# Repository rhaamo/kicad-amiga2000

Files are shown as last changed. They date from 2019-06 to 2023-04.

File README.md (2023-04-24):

# Amiga 2000 KiCAD Schematics and PCB

# Revision

Current schematics are based on 6.0 plus known 6.2 fixes.

Deviations from the original 6.2:
- The snapped resistor net around the 68k have been removed from schematics.
- The two res net soldered to U603 and U604 have a dedicated footprint on PCB
- The bridge C1/R1 also has footprint, same for R2 from U800
- The PST reset have dedicated footprint, diode have been removed
- There is an aditionnal header, J3, with OVR and INT2 breakout for accelerator cards, easier than clipping on chips
- Jumpers should have a default working configuration labelled on the PCB plus various notes
- The keyboard connector footprint have been modified to handle either the original one, or a standard MIDI one
- The battery terminals are just a two pins header, just plug some wires and use any battery you want aside or glued or whatever

# TODO

- Check if there is no useless local labels that could have generated spurious nets connected in the PCB

# Notes

The capacitors on the left of the POWER Connector are somewhat troubling if you don't have a lot of experience.

So the five caps should be placed like this (IGNORE the + footprint on the PCB):

- C400, GND pin on left
- C406, GND pin on left
- C408, GND pin on right
- C410, GND pin on left
- C412, GND pin on right

If using an A500-Flash from Retro 7-bit, U540 and U203 can't be socketted or they will be too high.

# Building

The file `amiga2000.csv` contains a full Mouser BOM, around ~150€.

Memory and RTC chip should be got from eBay, same for the PST reset thingy (U1).

The ISA (8bit and 16bit connectors) fits perfectly a full-length connector got from like an old PC motherboard.

The the table at the bottom of this README for a list of DigiKey and Mouser P/N for ZORRO, CoPro, Video and ISA slots.

Other chips (paula, denise, CIA, etc.) are got from a donor motherboard.

If building it for real: first test the PCB for short between GND and the various power lines (+5V, -5V, +12V, +5V_USER, etc.), the zorro should have all.

Then solder all the electrolytics caps, connect power, re-test all the lines.

Solder everything else, don't populate ICs yet, re-power and re-test.

Then you can add ICs and run DiagROM and then enjoy.

DO NOT POPULATE: J1, J2, C902, C917, R901, FB904, FB906, RP904, RP906, RP905, C230, C240, they are unpopulated on factory 6.2 rev, so, let them as-is.

# Testing

My first prototype have been tested with DiagROM v1.1.

Working: mouse, zorro listing of detected cards, composite video out, video out, serial (out at least), one audio ch (the other one should work too), keyboard.
Booting a workbench from the accelerator CF sorta work until noise issue or something make any disk I/O hang and crash.

Left to test: floppy, parallel port, if the RTC works properly.

The DiagROM detects 1024kB of chipmem, the extended test goes all the way up to 1023kB and then throw an error, I'm not sure if it's a DiagROM issue or just expected.

# Libraries

Uses libraries from https://dev.sigpipe.me/dashieelectronics/kicad_libraries

# Various tools

## extract_labels.py
NOTE: Broken since format change with KiCAD 7.0

Use this script to quickly extract all Global Labels from wanted sheets.

```
./extract_labels.py agnus.kicad_sch amiga2000.kicad_sch chipram.kicad_sch coprocessor\ slot.kicad_sch denise.kicad_sch expansion\ logic.kicad_sch parallel.kicad_sch paula.kicad_sch pc\ slots.kicad_sch power.kicad_sch processor.kicad_sch serial.kicad_sch zorro.kicad_sch
```

# License

CC0

# Sources

My own dying 6.2 A2000 board.

This pre-6.2 schematics, best scan quality available...:
- http://amiga.serveftp.net/Schematics/A2000_schematics/A2000_rev6_schematics_scanned.pdf

A big thanks for Floppie209 for his 1:1 board replica:
- https://github.com/Floppie209/Amiga2000-remake/

Whithout Floppie work I wouldn't have had enough motivation to sacrifice a sorta working board for measurements.

Documented 6.2 fixes: https://wiki.sigpipe.me/amiga:a2000:rev6.2fixes

# Random parts numbers

| for | Digikey PN | Mouser PN | Manufacturer PN | EOL |
|-----|---|---|---|-----|
| Zorro (100pins) | A121376-ND | 571-5645235-3 | 5645235-3 | no |
| CoPro (86pins) | A144213-ND | 571-1-5530843-0 | 1-5530843-0 | no |
| Video Slots and ISA16bit (36p) | A31716-ND |  571-5530843-3 | 5530843-3 | no |
| ISA 8bit (62) | A121053-ND |  571-7-5530843-0  | 7-5530843-0 | no |
| Full lenght ISA slots | A101941-ND |  571-5176139-2  | 5176139-2 | no |
| Power connector, 14 pins | | 538-26-60-4140 | 26-60-4140 | no |

# Pictures

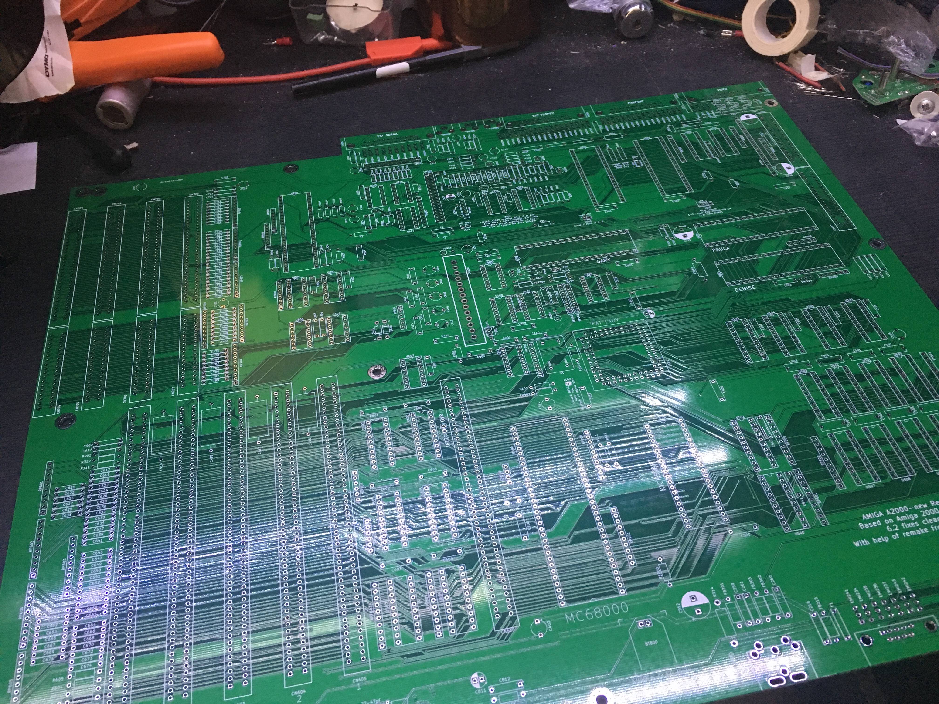
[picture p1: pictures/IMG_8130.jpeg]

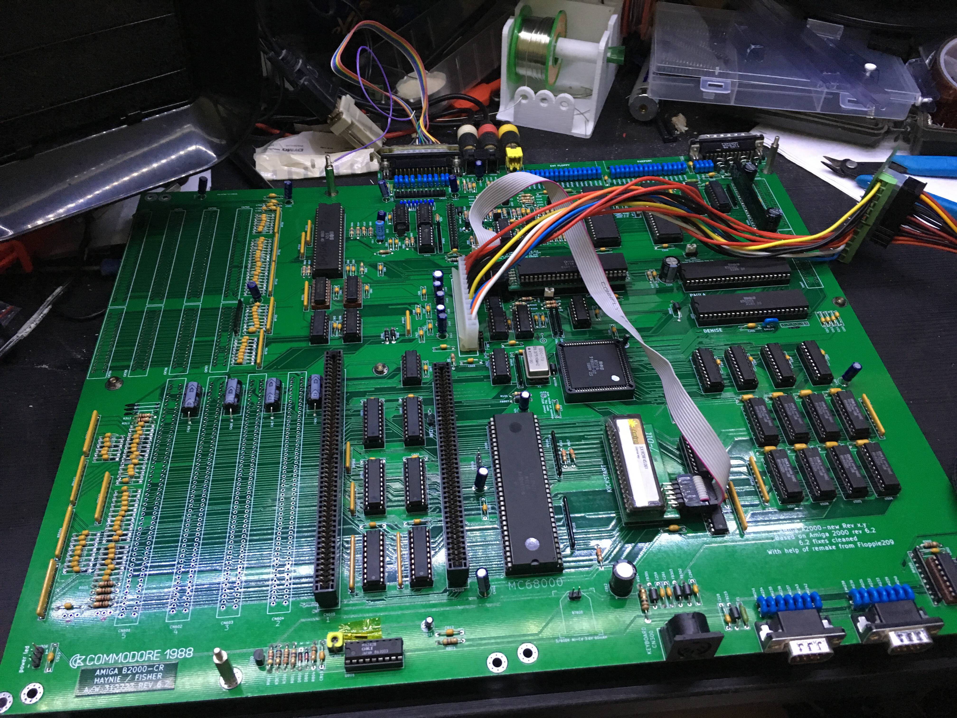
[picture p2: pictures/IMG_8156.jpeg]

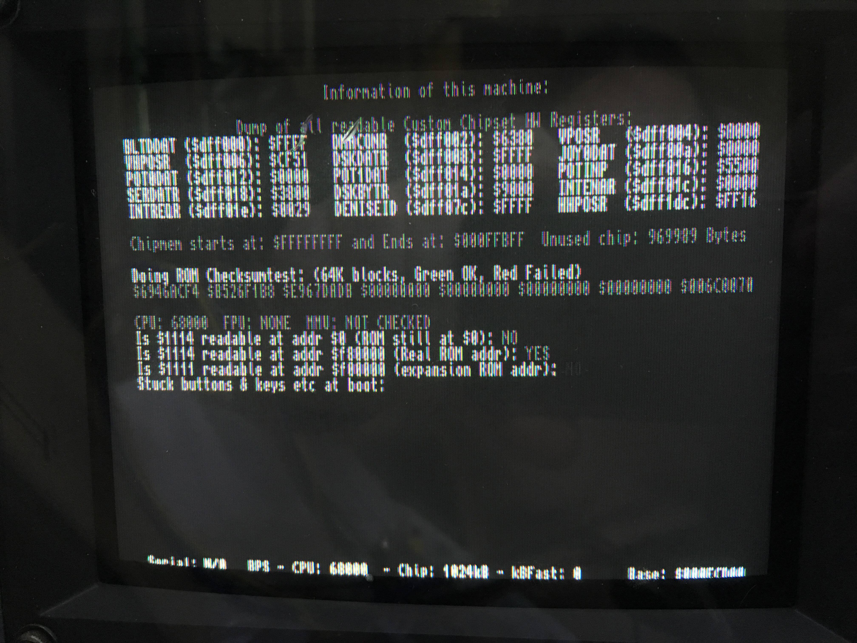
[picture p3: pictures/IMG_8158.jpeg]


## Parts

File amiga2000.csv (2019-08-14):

Ref | Qty | Value | Footprint | Datasheet | DoNotPopulate | Gender | MouserPN
BT800 | 1 | 3/60DK Ni-Cd 3.6V 60mAH | Connector_PinSocket_2.54mm:PinSocket_2x01_P2.54mm_Vertical | ~
C1 | 1 | 270pF | Capacitor_THT:C_Rect_L11.5mm_W2.6mm_P10.00mm_MKT | ~ |  |  | 581-SA101A271KAA
C100 C101 C102 C103 C104 C105 C106 C107 C108 C110 C200 C202 C203 C205 C206 C234 C244 C300 C301 C302 C303 C540 C541 C600 C601 C602 C603 C604 C605 C606 C607 C800 C802 C803 C804 C805 C812 C815 C900 C901 C903 C906 C909 C910 C915 C916 C918 C919 | 48 | 0.1uF | Capacitor_THT:C_Rect_L11.5mm_W2.6mm_P10.00mm_MKT | ~ |  |  | 581-SA105C104KARC
C201 C215 C216 C217 C219 C220 C221 C500 C700 C702 C703 C704 C705 | 13 | 0.22uF | Capacitor_THT:C_Rect_L11.5mm_W2.6mm_P10.00mm_MKT | ~ |  |  | 594-A224K20X7RF5TAA
C204 C305 C322 C323 C401 C407 C409 C411 C413 C414 | 10 | 0.01uF | Capacitor_THT:C_Rect_L11.5mm_W2.6mm_P10.00mm_MKT | ~ |  |  | 581-SA105C103K
C210 C211 C212 C213 C218 | 5 | 0.047uF | Capacitor_THT:C_Rect_L11.5mm_W2.6mm_P10.00mm_MKT | ~ |  |  | 581-SA105C473KARC
C214 C225 C226 C912 | 4 | 470uF 16/25v | Capacitor_THT:CP_Radial_D10.0mm_P5.00mm | ~ |  |  | 647-UVR1E471MPD
C222 C223 C402 C403 C404 C405 C406 C408 C410 C412 C420 C421 C422 | 13 | 47uF 16V | Capacitor_THT:CP_Radial_Tantal_D5.5mm_P5.00mm | ~ |  |  | 667-ECA-1CM470B
C224 C415 C811 | 3 | 4.7uF 16V | Capacitor_THT:CP_Radial_D5.0mm_P2.50mm | ~ |  |  | 647-UMA1C4R7MCD2TP
C230 C240 | 2 | 0.1uF | Capacitor_THT:C_Rect_L11.5mm_W2.6mm_P10.00mm_MKT | ~ | yes |  | 581-SA105C104KARC
C231 C241 | 2 | 6800pF | Capacitor_THT:C_Rect_L11.5mm_W2.6mm_P10.00mm_MKT | ~ |  |  | 581-SA101C682MAA
C232 C242 | 2 | 3900pF | Capacitor_THT:C_Rect_L11.5mm_W2.6mm_P10.00mm_MKT | ~ |  |  | 581-SA051C392KAA
C233 C243 C317 C318 C701 C813 C814 | 7 | 22uF 16V | Capacitor_THT:CP_Radial_Tantal_D5.0mm_P5.00mm | ~ |  |  | 667-ECA-1CM220B
C259 C260 C261 C304 C306 C904 C905 C907 C908 C914 C920 | 11 | 100pF | Capacitor_THT:C_Rect_L11.5mm_W2.6mm_P10.00mm_MKT | ~ |  |  | 80-C410C101K5G
C310 C311 C312 C313 C314 C315 C316 | 7 | 1000pF | Capacitor_THT:C_Rect_L7.0mm_W2.0mm_P5.00mm | ~ |  |  | 810-FG28C0G1H102JNT6
C320 C321 | 2 | 470pF | Capacitor_THT:C_Rect_L7.0mm_W2.0mm_P5.00mm | ~ |  |  | 810-FG28C0G1H471JNT0
C400 | 1 | 220uF 16V | Capacitor_THT:CP_Radial_Tantal_D6.0mm_P5.00mm | ~ |  |  | 667-ECA-1CM221B
C416 C417 C418 C419 | 4 | 220uF 16V | Capacitor_THT:C_Axial_L19.0mm_D8.0mm_P25.00mm_Horizontal | ~ |  |  | 75-516D227M025MM6AE3
C501 C502 C503 C504 C505 C506 C507 C508 | 8 | 0.33uF | Capacitor_THT:C_Rect_L11.5mm_W4.0mm_P10.00mm_MKT | ~ |  |  | 581-SA305C334KAA
C617 C619 C620 C621 C622 C623 C624 C625 C626 C627 C628 C629 C630 C631 C632 C633 C635 C637 C639 C641 C645 C647 C649 C650 C651 C652 C654 C655 C657 C658 C659 C660 C661 C662 C663 C664 C665 C666 C667 C668 C669 C670 C671 C672 C673 C674 C678 C711 C713 C714 C716 C717 C719 C720 C722 C726 C728 C730 C732 C734 C736 C738 C740 C742 C744 C746 C748 C750 C752 C754 C756 C758 C760 C762 C764 C766 C768 C770 C776 C778 C780 C782 C784 C786 C787 C789 C790 C791 C793 C794 C796 | 91 | 1000pF | Capacitor_THT:C_Rect_L11.5mm_W2.6mm_P10.00mm_MKT | ~ |  |  | 581-SA105C102KAR
C810 | 1 | 20pF | Capacitor_THT:C_Rect_L11.5mm_W2.6mm_P10.00mm_MKT | ~ |  |  | 581-SA102A200JAR
C902 C917 | 2 | empty | Capacitor_THT:C_Rect_L11.5mm_W2.0mm_P10.00mm_MKT | ~ | yes
C913 | 1 | 47pF | Capacitor_THT:C_Rect_L11.5mm_W2.6mm_P10.00mm_MKT | ~ |  |  | 80-C410C470K1G
CN200 | 1 | DB9P RIGHT(1) | Connector_Dsub:DSUB-9_Male_Horizontal_P2.77x2.84mm_EdgePinOffset7.70mm_Housed_MountingHolesOffset9.12mm | ~ |  | Male
CN201 | 1 | DB9P LEFT(0) | Connector_Dsub:DSUB-9_Male_Horizontal_P2.77x2.84mm_EdgePinOffset7.70mm_Housed_MountingHolesOffset9.12mm | ~ |  | Male
CN202 | 1 | DB23M | d_amiga:DSUB-23_Male_Horizontal_P2.77x2.84mm_EdgePinOffset7.70mm_Housed_MountingHolesOffset9.12mm | ~ |  | Male
CN203 | 1 | INTERNAL VIDEO SLOT TOP | d_amiga:VIDEOSLOT | ~
CN204 | 1 | RIGHT AUDIO | d_amiga:RCA | ~
CN205 | 1 | LEFT AUDIO | d_amiga:RCA | ~
CN206 | 1 | COMPOSITE | d_amiga:RCA | ~
CN207 | 1 | INTERNAL VIDEO SLOT BOT | d_amiga:VIDEOSLOT | ~
CN300 | 1 | KEYBOARD | d_amiga:DIN_5_KBD | http://www.mouser.com/ds/2/18/40_c091_abd_e-75918.pdf |  | Female
CN301 | 1 | DB25F | Connector_Dsub:DSUB-25_Female_Horizontal_P2.77x2.84mm_EdgePinOffset7.70mm_Housed_MountingHolesOffset9.12mm | ~ |  | Female
CN302 | 1 | DB23F | d_amiga:DSUB-23_Female_Horizontal_P2.77x2.84mm_EdgePinOffset7.70mm_Housed_MountingHolesOffset9.12mm | ~ |  | Female
CN303 | 1 | Conn_02x17_Odd_Even | Connector_PinHeader_2.54mm:PinHeader_2x17_P2.54mm_Vertical | ~ |  | Male
CN304 | 1 | Conn_02x13_Odd_Even | Connector_PinHeader_2.54mm:PinHeader_2x13_P2.54mm_Vertical | ~ |  | Male
CN305 | 1 | DB25M | Connector_Dsub:DSUB-25_Male_Horizontal_P2.77x2.84mm_EdgePinOffset7.70mm_Housed_MountingHolesOffset9.12mm | ~ |  | Male
CN400 | 1 | POWER_CONN | d_amiga:A2K_PWR | ~ |  | Male
CN600 | 1 | CO-PROCESSOR_SLOT | d_amiga:COPRO
CN601 CN602 CN603 CN604 CN605 | 5 | zorro_socket | d_amiga:Zorro
CN606 | 1 | Conn_01x04_Male | Connector_PinHeader_2.54mm:PinHeader_1x04_P2.54mm_Vertical | ~
CN700 CN701 CN702 CN703 | 4 | IBM_8_BIT_EXPANSION_BUS | ISA:ISA8
CN704 CN705 | 2 | IBM_16_BIT_EXTENDED_BUS | ISA:ISA16 |  | yes
CN706 CN707 | 2 | IBM_16_BIT_EXTENDED_BUS | ISA:ISA16
D300 D800 D801 | 3 | 1N4148 | Diode_THT:D_DO-35_SOD27_P7.62mm_Horizontal | https://assets.nexperia.com/documents/data-sheet/1N4148_1N4448.pdf |  |  | 78-1N4148
D400 D401 | 2 | 1N4001 | Diode_THT:D_DO-41_SOD81_P10.16mm_Horizontal | http://www.vishay.com/docs/88503/1n4001.pdf |  |  | 750-1N4001-G
EMI201 | 1 | Fitted with a double ferrite beads... | d_amiga:EMI_FILTER | ~ |  |  | 81-BL03RN2R1P1A
EMI206 EMI207 EMI210 EMI211 EMI229 EMI322 EMI323 EMI324 EMI339 EMI340 EMI341 | 11 | 100pF (Type C 101) | d_amiga:EMI_FILTER | ~ |  |  | Using Type F instead 81-DSS1NB32A101Q91A
EMI208 EMI311 EMI312 EMI313 EMI314 EMI315 EMI316 EMI317 EMI318 EMI319 EMI320 EMI321 | 12 | 100pF (Type F 101) | d_amiga:EMI_FILTER | ~ |  |  | 81-DSS1NB32A101Q91A
EMI209 | 1 | 3.8nF (Type F 382) | d_amiga:EMI_FILTER | ~ |  |  | 81-DSS1NB32A332Q91A
EMI230 EMI231 EMI232 EMI233 EMI234 EMI235 EMI236 EMI237 EMI238 EMI239 EMI240 EMI241 EMI242 EMI243 | 14 | 6.8nF (Type F 682) | d_amiga:EMI_FILTER | ~ |  |  | 81-DSS1NB32A682Q91A
EMI300 EMI301 EMI302 EMI303 EMI304 EMI305 EMI306 EMI307 EMI308 EMI309 EMI310 EMI325 EMI326 EMI327 EMI328 EMI329 EMI330 EMI331 EMI332 EMI333 EMI334 EMI335 EMI336 EMI337 EMI338 | 25 | 330pF (Type F 331) | d_amiga:EMI_FILTER | ~ |  |  | 81-DSS1NB32A331Q91A
F1 F2 F3 F4 F5 | 5 | 4A | Capacitor_THT:C_Rect_L11.5mm_W2.0mm_P10.00mm_MKT | ~ |  |  | 576-0251004.MRT1L
FB101 FB215 FB301 FB302 FB303 FB401 FB907 | 7 | Ferrite_Bead_Small | Inductor_THT:L_Axial_L7.0mm_D3.3mm_P10.16mm_Horizontal_Fastron_MICC | ~ |  |  | 875-28L0138-10R-10
FB102 | 1 | Ferrite_Bead_Small | Inductor_THT:L_Axial_L9.5mm_D4.0mm_P15.24mm_Horizontal_Fastron_SMCC | ~ |  |  | 875-28L0138-10R-10
FB216 FB217 FB218 FB219 FB220 FB221 FB900 FB901 FB902 FB903 | 10 | Ferrite_Bead_Small | d_amiga:FERRITE_BEADS_DOUBLE | ~ |  |  | 81-BL03RN2R1P1A
FB904 FB906 | 2 | Ferrite_Bead | Inductor_THT:L_Axial_L7.0mm_D3.3mm_P5.08mm_Vertical_Fastron_MICC | ~ | yes
H1 H2 H3 H4 H5 H6 H7 H8 H9 H10 H11 H12 H13 H14 | 14 | MountingHole_Pad | MountingHole:MountingHole_4mm_Pad_Via | ~ | yes
HY200 | 1 | HY200VIDIOT | Connector_PinSocket_2.54mm:PinSocket_1x22_P2.54mm_Vertical
J1 J2 | 2 | Conn_01x03_Male | Connector_PinHeader_2.54mm:PinHeader_1x03_P2.54mm_Vertical | ~ | yes
J3 | 1 | ACCEL | Connector_PinHeader_2.54mm:PinHeader_1x02_P2.54mm_Vertical | ~
J101 J200 J300 J306 | 4 | Conn_01x03_Male | Connector_PinHeader_2.54mm:PinHeader_1x03_P2.54mm_Vertical | ~
J102 | 1 | Jumper_2_Open | Jumper:SolderJumper-2_P1.3mm_Open_RoundedPad1.0x1.5mm | ~
J301 | 1 | DF1: | Connector_PinHeader_2.54mm:PinHeader_2x01_P2.54mm_Vertical | ~
J500 J900 | 2 | Jumper_2_Bridged | Connector_PinHeader_2.54mm:PinHeader_2x01_P2.54mm_Vertical | ~
Q200 Q201 | 2 | MPF102 | Package_TO_SOT_THT:TO-92_Inline | ~ |  |  | 610-2N3906 or 512-J113D74Z
Q202 Q302 | 2 | 2N3906 | Package_TO_SOT_THT:TO-92_Inline | https://www.fairchildsemi.com/datasheets/2N/2N3906.pdf |  |  | 833-2N3906-AP
Q300 | 1 | 2SC945 | Package_TO_SOT_THT:TO-92_Inline | ~
Q301 | 1 | 2N3904 | Package_TO_SOT_THT:TO-92_Inline | https://www.fairchildsemi.com/datasheets/2N/2N3904.pdf |  |  | 833-2N3904-AP
R1 R307 | 2 | 68 | Resistor_THT:R_Axial_DIN0207_L6.3mm_D2.5mm_P10.16mm_Horizontal | ~ |  |  | 603-CFR-25JT-52-68R
R2 R233 R243 R301 R302 R311 R312 R601 R602 R603 R604 R605 R800 R900 | 14 | 1k | Resistor_THT:R_Axial_DIN0207_L6.3mm_D2.5mm_P10.16mm_Horizontal | ~ |  |  | 603-CFR-25JR-521K
R101 R109 R201 R300 R309 R500 R806 R807 R902 R916 | 10 | 4.7k | Resistor_THT:R_Axial_DIN0207_L6.3mm_D2.5mm_P10.16mm_Horizontal | ~ |  |  | 603-CFR-25JT-52-4K7
R104 | 1 | 4.7K | Resistor_THT:R_Axial_DIN0207_L6.3mm_D2.5mm_P10.16mm_Horizontal | ~ |  |  | 603-CFR-25JR-524K7
R105 R106 R212 | 3 | 22 | Resistor_THT:R_Axial_DIN0207_L6.3mm_D2.5mm_P10.16mm_Horizontal | ~ |  |  | 603-CFR-25JR-52-22R
R110 R111 R114 R115 R917 R1000 | 6 | 330 | Resistor_THT:R_Axial_DIN0207_L6.3mm_D2.5mm_P10.16mm_Horizontal | ~ |  |  | 603-CFR-25JT-52-330R
R200 R215 | 2 | 1 | Resistor_THT:R_Axial_DIN0207_L6.3mm_D2.5mm_P10.16mm_Horizontal | ~ |  |  | 603-CFR-25JR-52-1R
R202 R203 R206 R211 R214 R216 R231 R232 R241 R242 R305 R306 R802 R804 | 14 | 10k | Resistor_THT:R_Axial_DIN0207_L6.3mm_D2.5mm_P10.16mm_Horizontal | ~ |  |  | 603-CFR-25JR-5210K
R204 R205 | 2 | 470k | Resistor_THT:R_Axial_DIN0207_L6.3mm_D2.5mm_P10.16mm_Horizontal | ~ |  |  | 603-CFR-25JR-52470K
R207 R208 | 2 | 10 | Resistor_THT:R_Axial_DIN0207_L6.3mm_D2.5mm_P10.16mm_Horizontal | ~ |  |  | 603-CFR-25JB-52-10R
R209 R210 | 2 | 1.2k | Resistor_THT:R_Axial_DIN0207_L6.3mm_D2.5mm_P10.16mm_Horizontal | ~ |  |  | 603-CFR-25JT-52-1K2
R213 | 1 | 2.7k | Resistor_THT:R_Axial_DIN0207_L6.3mm_D2.5mm_P10.16mm_Horizontal | ~ |  |  | 603-CFR-25JR-522K7
R230 R240 | 2 | 360 | Resistor_THT:R_Axial_DIN0207_L6.3mm_D2.5mm_P10.16mm_Horizontal | ~ |  |  | 603-CFR-25JB-52-360R
R234 R244 | 2 | 390 | Resistor_THT:R_Axial_DIN0207_L6.3mm_D2.5mm_P10.16mm_Horizontal | ~ |  |  | 603-CFR-25JR-52390R
R308 | 1 | 200 | Resistor_THT:R_Axial_DIN0207_L6.3mm_D2.5mm_P10.16mm_Horizontal | ~ |  |  | 603-CFR-25JR-52-200R
R310 | 1 | 47 0.5W | Resistor_THT:R_Axial_DIN0411_L9.9mm_D3.6mm_P15.24mm_Horizontal | ~ |  |  | 588-OL4705E-R52
R801 R803 | 2 | 470 | Resistor_THT:R_Axial_DIN0207_L6.3mm_D2.5mm_P10.16mm_Horizontal | ~ |  |  | 603-CFR-25JT-52-470R
R805 | 1 | 47k | Resistor_THT:R_Axial_DIN0207_L6.3mm_D2.5mm_P10.16mm_Horizontal | ~ |  |  | 603-CFR-25JR-5247K
R901 | 1 | empty | Resistor_THT:R_Axial_DIN0207_L6.3mm_D2.5mm_P10.16mm_Horizontal | ~ | yes
R904 R905 | 2 | 47 | Resistor_THT:R_Axial_DIN0207_L6.3mm_D2.5mm_P10.16mm_Horizontal | ~ |  |  | 603-CFR-25JT-52-47R
R914 | 1 | 1 0.5W | Resistor_THT:R_Axial_DIN0411_L9.9mm_D3.6mm_P15.24mm_Horizontal | ~ |  |  | 603-CFR-50JB-52-1R
RP100 RP101 RP200 RP705 | 4 | 4.7k | Resistor_THT:R_Array_SIP10 | http://www.vishay.com/docs/31509/csc.pdf |  |  | 858-L101S472LF
RP102 RP201 RP203 RP902 RP907 | 5 | 47 (isolated pack) | Resistor_THT:R_Array_SIP8 | http://www.vishay.com/docs/31509/csc.pdf |  |  | 858-L083S470LF
RP204 | 1 | 68 (isolated pack) | Resistor_THT:R_Array_SIP8 | http://www.vishay.com/docs/31509/csc.pdf |  |  | 858-L083S680LF
RP205 RP301 RP607 RP903 RP908 | 5 | 1k | Resistor_THT:R_Array_SIP6 | http://www.vishay.com/docs/31509/csc.pdf |  |  | 652-4606M-1LF-1K
RP300 | 1 | 10k | Resistor_THT:R_Array_SIP10 | http://www.vishay.com/docs/31509/csc.pdf |  |  | 652-4610X-1LF-10K
RP500 RP501 | 2 | 47 (isolated pack) | Resistor_THT:R_Array_SIP10 | http://www.vishay.com/docs/31509/csc.pdf |  |  | 652-4610X-2LF-47
RP502 | 1 | 22 (isolated pack) | Resistor_THT:R_Array_SIP10 | http://www.vishay.com/docs/31509/csc.pdf |  |  | 652-4610X-2LF-22
RP503 RP604 | 2 | 470 | Resistor_THT:R_Array_SIP10 | http://www.vishay.com/docs/31509/csc.pdf |  |  | 652-4610X-1LF-470
RP600 | 1 | 10k | Resistor_THT:R_Array_SIP8 | http://www.vishay.com/docs/31509/csc.pdf |  |  | 652-4608X-101-103FLF
RP601 RP602 RP603 RP605 RP700 RP701 RP702 RP703 RP704 | 9 | 1k | Resistor_THT:R_Array_SIP10 | http://www.vishay.com/docs/31509/csc.pdf |  |  | 652-4610X-1LF-1K
RP800 | 1 | 1k | Resistor_THT:R_Array_SIP8 | http://www.vishay.com/docs/31509/csc.pdf |  |  | 652-4608X-AP1-102LF
RP801 | 1 | 4.7k | Resistor_THT:R_Array_SIP8 | http://www.vishay.com/docs/31509/csc.pdf |  |  | 652-4608X-AP1-472LF
RP802 | 1 | 1k (isolated pack) | Resistor_THT:R_Array_SIP10 | http://www.vishay.com/docs/31509/csc.pdf |  |  | 269-1.0K-RC
RP904 RP905 RP906 | 3 | 4.7k | Resistor_THT:R_Array_SIP6 | http://www.vishay.com/docs/31509/csc.pdf | yes |  | 264-4.7K-RC
RPF603 RPF604 | 2 | 3.3k | Resistor_THT:R_Array_SIP10 | http://www.vishay.com/docs/31509/csc.pdf |  |  | 652-4610X-1LF-3.3K
U1 | 1 | PST518B | Package_TO_SOT_THT:TO-92L_Inline | http://www.amigawiki.org/lib/exe/fetch.php?media=de:service:upgrades:pst518b_mitsumi_datasheet.pdf
U100 | 1 | MC68000 | Package_DIP:DIP-64_W22.86mm_Socket | https://www.nxp.com/docs/en/reference-manual/MC68000UM.pdf
U101 | 1 | AGNUS8372 | Package_LCC:PLCC-84_THT-Socket
U102 | 1 | GARY5719 | Package_DIP:DIP-48_W15.24mm_Socket
U103 U105 | 2 | 74F245 | Package_DIP:DIP-20_W7.62mm_Socket | http://www.mouser.com/ds/2/308/fairchild%20semiconductor_74f245-1116738.pdf |  |  | 595-SN74F245N
U104 U106 | 2 | 74LS373 | Package_DIP:DIP-20_W7.62mm_Socket | http://www.ti.com/lit/gpn/sn74LS373 |  |  | 595-SN74LS373N
U107 | 1 | 74F04 | Package_DIP:DIP-14_W7.62mm_Socket | https://www.soemtron.org/downloads/disposals/74f04.pdf |  |  | 595-SN74F04N
U108 | 1 | 74LS74A | Package_DIP:DIP-14_W7.62mm_Socket | http://www.ti.com/lit/ds/symlink/sn74ls74a.pdf |  |  | 595-SN74LS74AN
U200 | 1 | PAULA | Package_DIP:DIP-48_W15.24mm_Socket | https://www.amigawiki.org/doku.php?id=de:parts:paula
U201 | 1 | DENISE8373 | Package_DIP:DIP-48_W15.24mm_Socket
U202 | 1 | 74LS157 | Package_DIP:DIP-16_W7.62mm_Socket | http://www.ti.com/lit/gpn/sn74LS157 |  |  | 595-SN74LS157N
U203 | 1 | 74LS38 | Package_DIP:DIP-14_W7.62mm_Socket | http://www.ti.com/lit/gpn/sn74LS38 |  |  | 595-SN74LS38N
U204 | 1 | LF347 | Package_DIP:DIP-14_W7.62mm_Socket | http://www.ti.com/lit/ds/symlink/lf347-n.pdf |  |  | 926-LF347N/NOPB
U205 U206 | 2 | 74LS244 | Package_DIP:DIP-20_W7.62mm_Socket | http://www.ti.com/lit/gpn/sn74LS244 |  |  | 595-SN74LS244N
U300 | 1 | CIA8520 | Package_DIP:DIP-40_W15.24mm_Socket | https://www.amigawiki.org/doku.php?id=de:parts:cia
U301 | 1 | 8520 | Package_DIP:DIP-40_W15.24mm_Socket | https://www.amigawiki.org/doku.php?id=de:parts:cia
U302 U606 | 2 | 74LS32 | Package_DIP:DIP-14_W7.62mm_Socket | http://www.ti.com/lit/gpn/sn74LS32 |  |  | 595-SN74LS32N
U303 | 1 | 74F08 | Package_DIP:DIP-14_W7.62mm_Socket | http://www.ti.com/lit/gpn/sn74LS08 |  |  | 595-SN74F08N
U304 | 1 | 1488 | Package_DIP:DIP-14_W7.62mm_Socket | https://www.onsemi.com/pub/Collateral/MC1488-D.PDF |  |  | 595-MC1488N
U305 | 1 | 1489 | Package_DIP:DIP-14_W7.62mm_Socket | https://www.onsemi.com/pub/Collateral/MC1489-D.PDF |  |  | 595-MC1489N
U500 | 1 | 62402 | Package_DIP:DIP-40_W15.24mm_Socket
U501 U502 U503 U504 U505 U506 U507 U508 | 8 | XX4256-15 | Package_DIP:DIP-20_W7.62mm_Socket
U540 U541 | 2 | 74F244 | Package_DIP:DIP-20_W7.62mm_Socket | http://www.ti.com/lit/gpn/sn74F244 |  |  | 595-SN74F244N
U600 U601 U603 U604 | 4 | 74LS245 | Package_DIP:DIP-20_W7.62mm_Socket | http://www.ti.com/lit/gpn/sn74LS245 |  |  | 595-SN74LS245N
U602 U605 | 2 | 74ALS245 | Package_DIP:DIP-20_W7.62mm_Socket | http://www.ti.com/lit/ds/symlink/sn74als245a.pdf |  |  | 595-SN74ALS245AN
U607 U803 | 2 | 74LS08 | Package_DIP:DIP-14_W7.62mm_Socket | http://www.ti.com/lit/gpn/sn74LS08 |  |  | 595-SN74LS08N
U800 | 1 | BUSTER5721 | Package_DIP:DIP-48_W15.24mm_Socket | http://obligement.free.fr/articles/chipsetamiga.php#buster
U801 | 1 | MSM6242 | Package_DIP:DIP-18_W7.62mm_Socket | https://pdf1.alldatasheet.com/datasheet-pdf/view/11259/OKI/MSM6242B.html
U802 | 1 | 74LS138 | Package_DIP:DIP-16_W7.62mm_Socket | http://www.ti.com/lit/gpn/sn74LS138 |  |  | 595-SN74LS138N
U804 | 1 | 74LS148 | Package_DIP:DIP-16_W7.62mm_Socket | http://www.ti.com/lit/gpn/sn74LS148 |  |  | 595-SN74LS148N
U805 | 1 | LM339 | Package_DIP:DIP-14_W7.62mm_Socket | http://www.ti.com/lit/ds/symlink/lm339.pdf |  |  | 595-LM339N
U900 | 1 | 74F00 | Package_DIP:DIP-14_W7.62mm_Socket | http://www.ti.com/lit/gpn/sn74ls00 |  |  | 595-SN74F00N
VC800 | 1 | 22-47pF | Capacitor_THT:C_Rect_L7.0mm_W6.5mm_P5.00mm | ~
X1 | 1 | 28.37516MHz (pal) | Oscillator:Oscillator_DIP-14
Y800 | 1 | 32768Hz | Crystal:Crystal_DS15_D1.5mm_L5.0mm_Horizontal | ~ |  |  | 695-CFS145-327K-U

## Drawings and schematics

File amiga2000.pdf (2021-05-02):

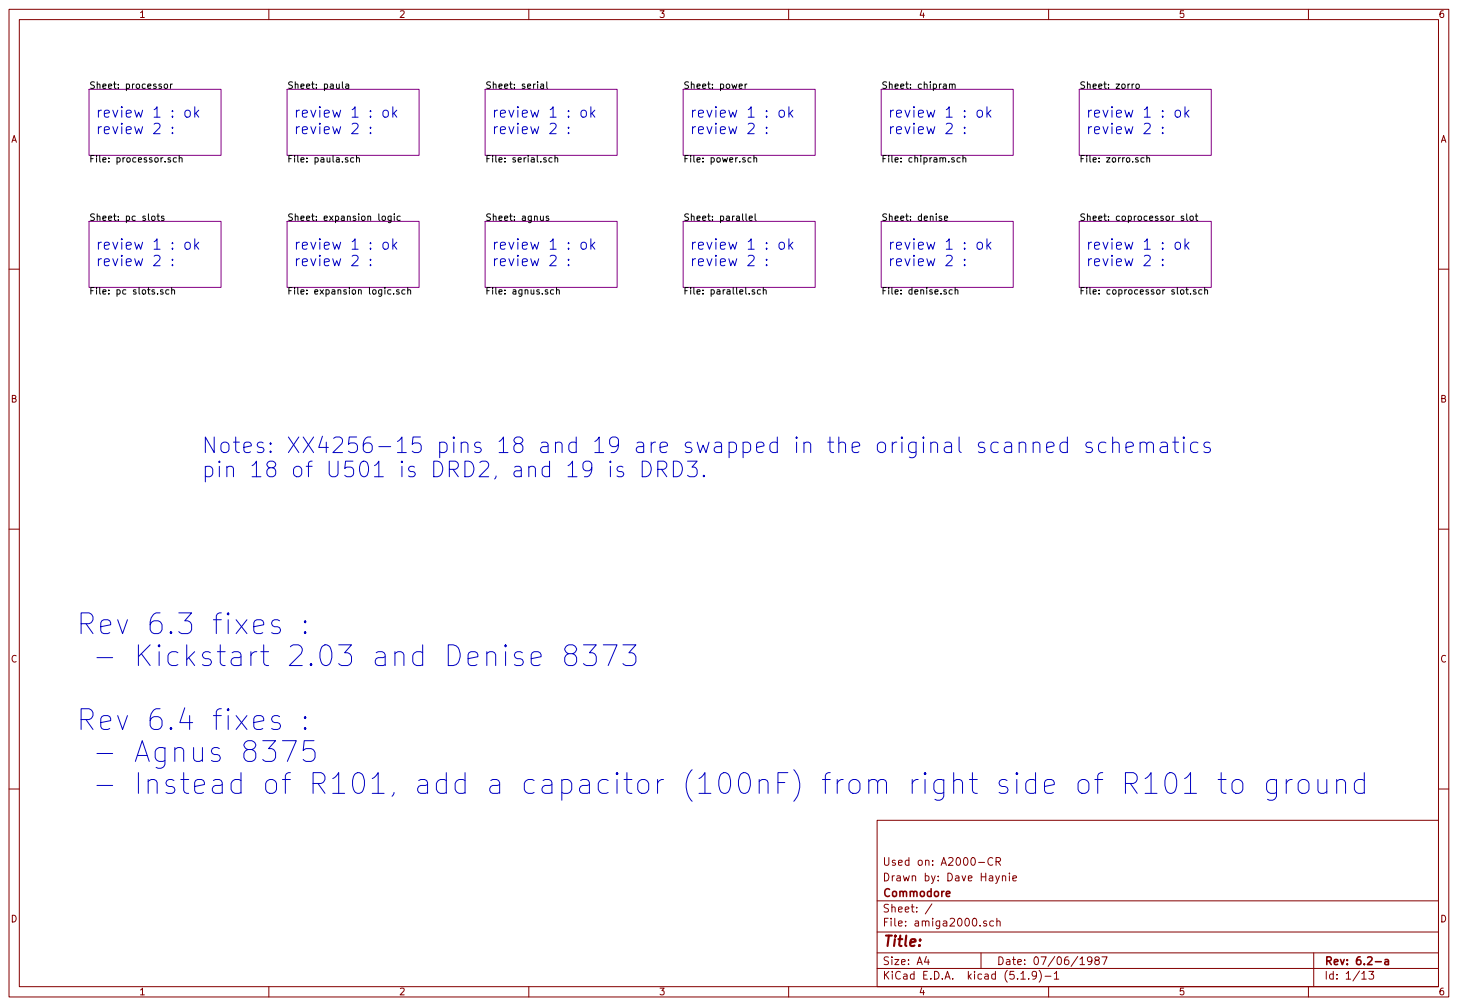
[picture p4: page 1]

File: power.sch Sheet: serial File: serial.sch Notes: XX4256-15 pins 18 and 19 are swapped in the original scanned schematics

File: coprocessor slot.sch Sheet: denise File: denise.sch Sheet: parallel
review 1 : ok
review 2 :

File: expansion logic.sch

pin 18 of U501 is DRD2, and 19 is DRD3.

Rev 6.3 fixes :
- Kickstart 2.03 and Denise 8373
Rev 6.4 fixes :
- Agnus 8375
- Instead of R101, add a capacitor (100nF) from right side of R101 to ground

File: amiga2000.sch Sheet: / Commodore Drawn by: Dave Haynie Used on: A2000-CR

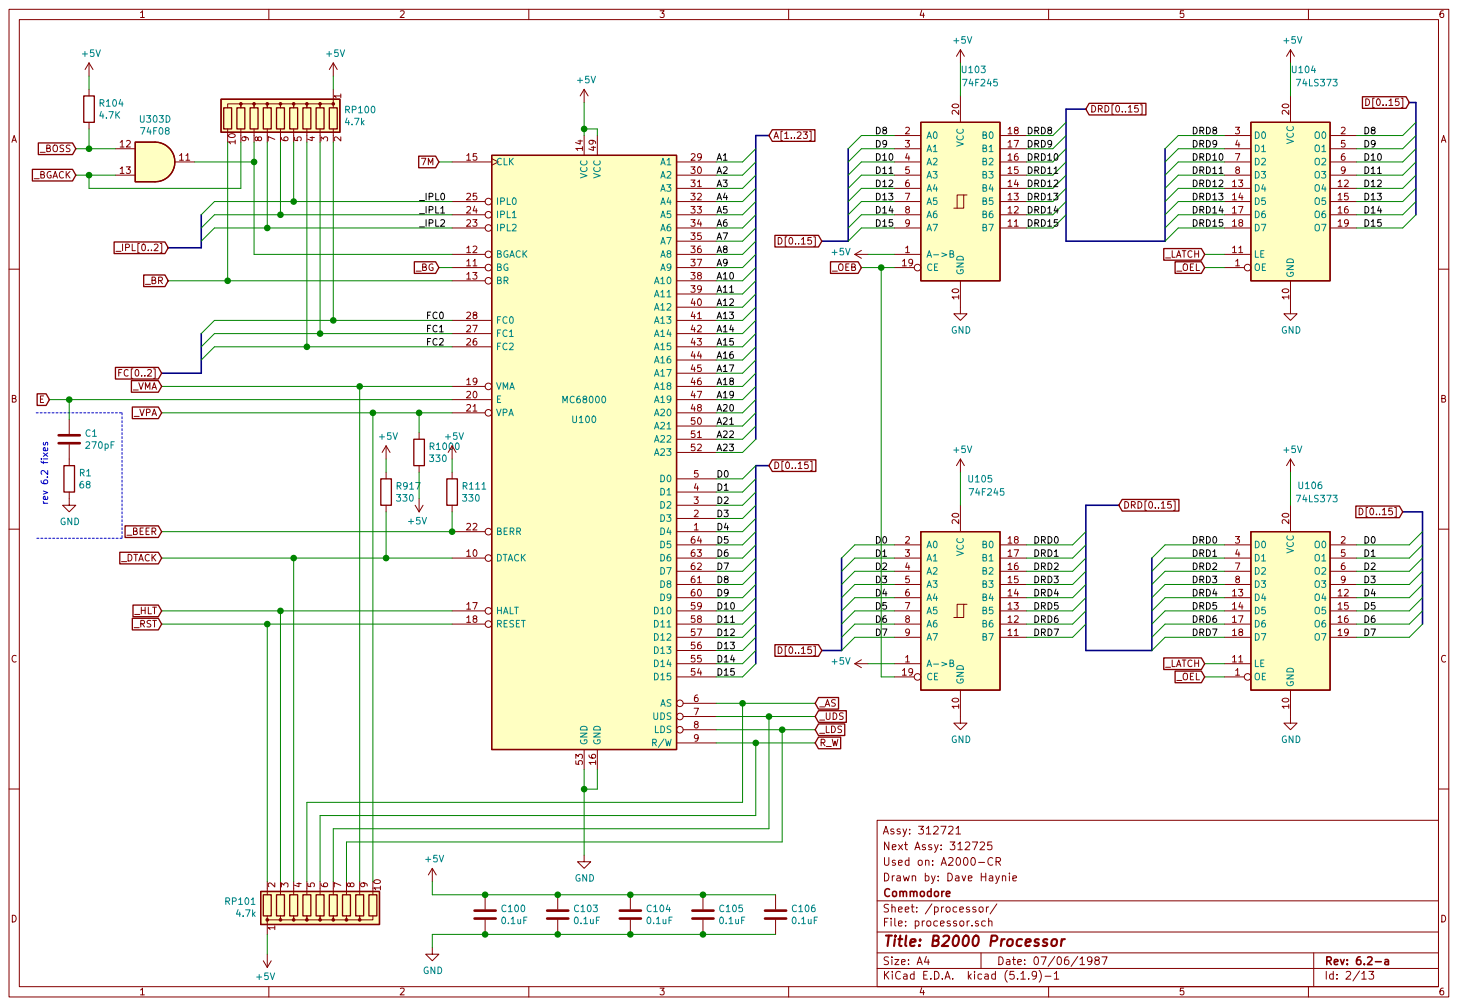
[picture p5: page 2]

Next Assy: 312725
Sheet: /processor/ Commodore Drawn by: Dave Haynie Used on: A2000-CR

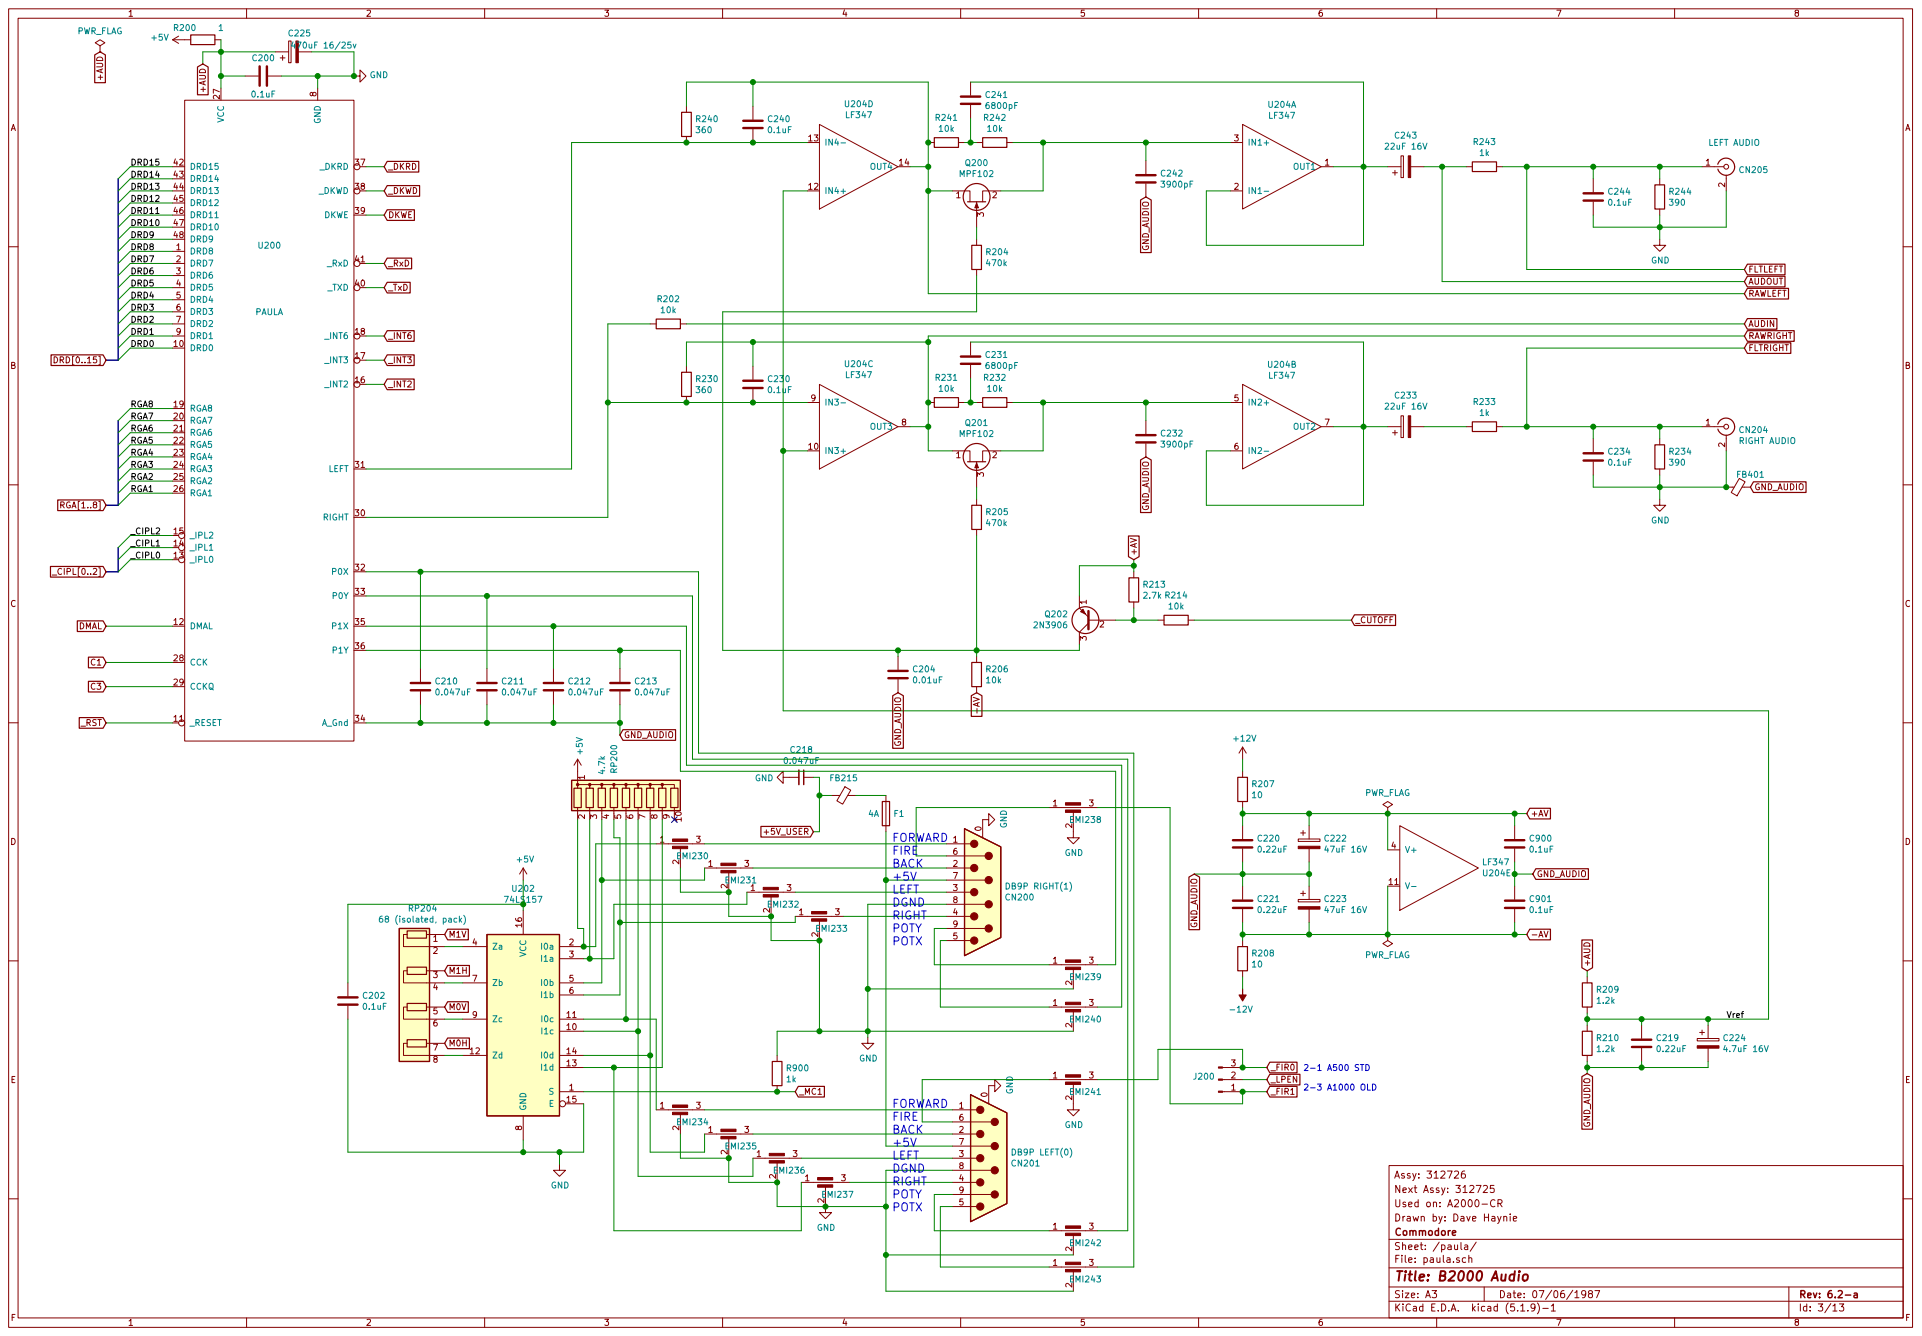
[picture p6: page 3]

1 | BACK | 6

Assy: 312726
Next Assy: 312725
Sheet: /paula/ Commodore Drawn by: Dave Haynie Used on: A2000-CR

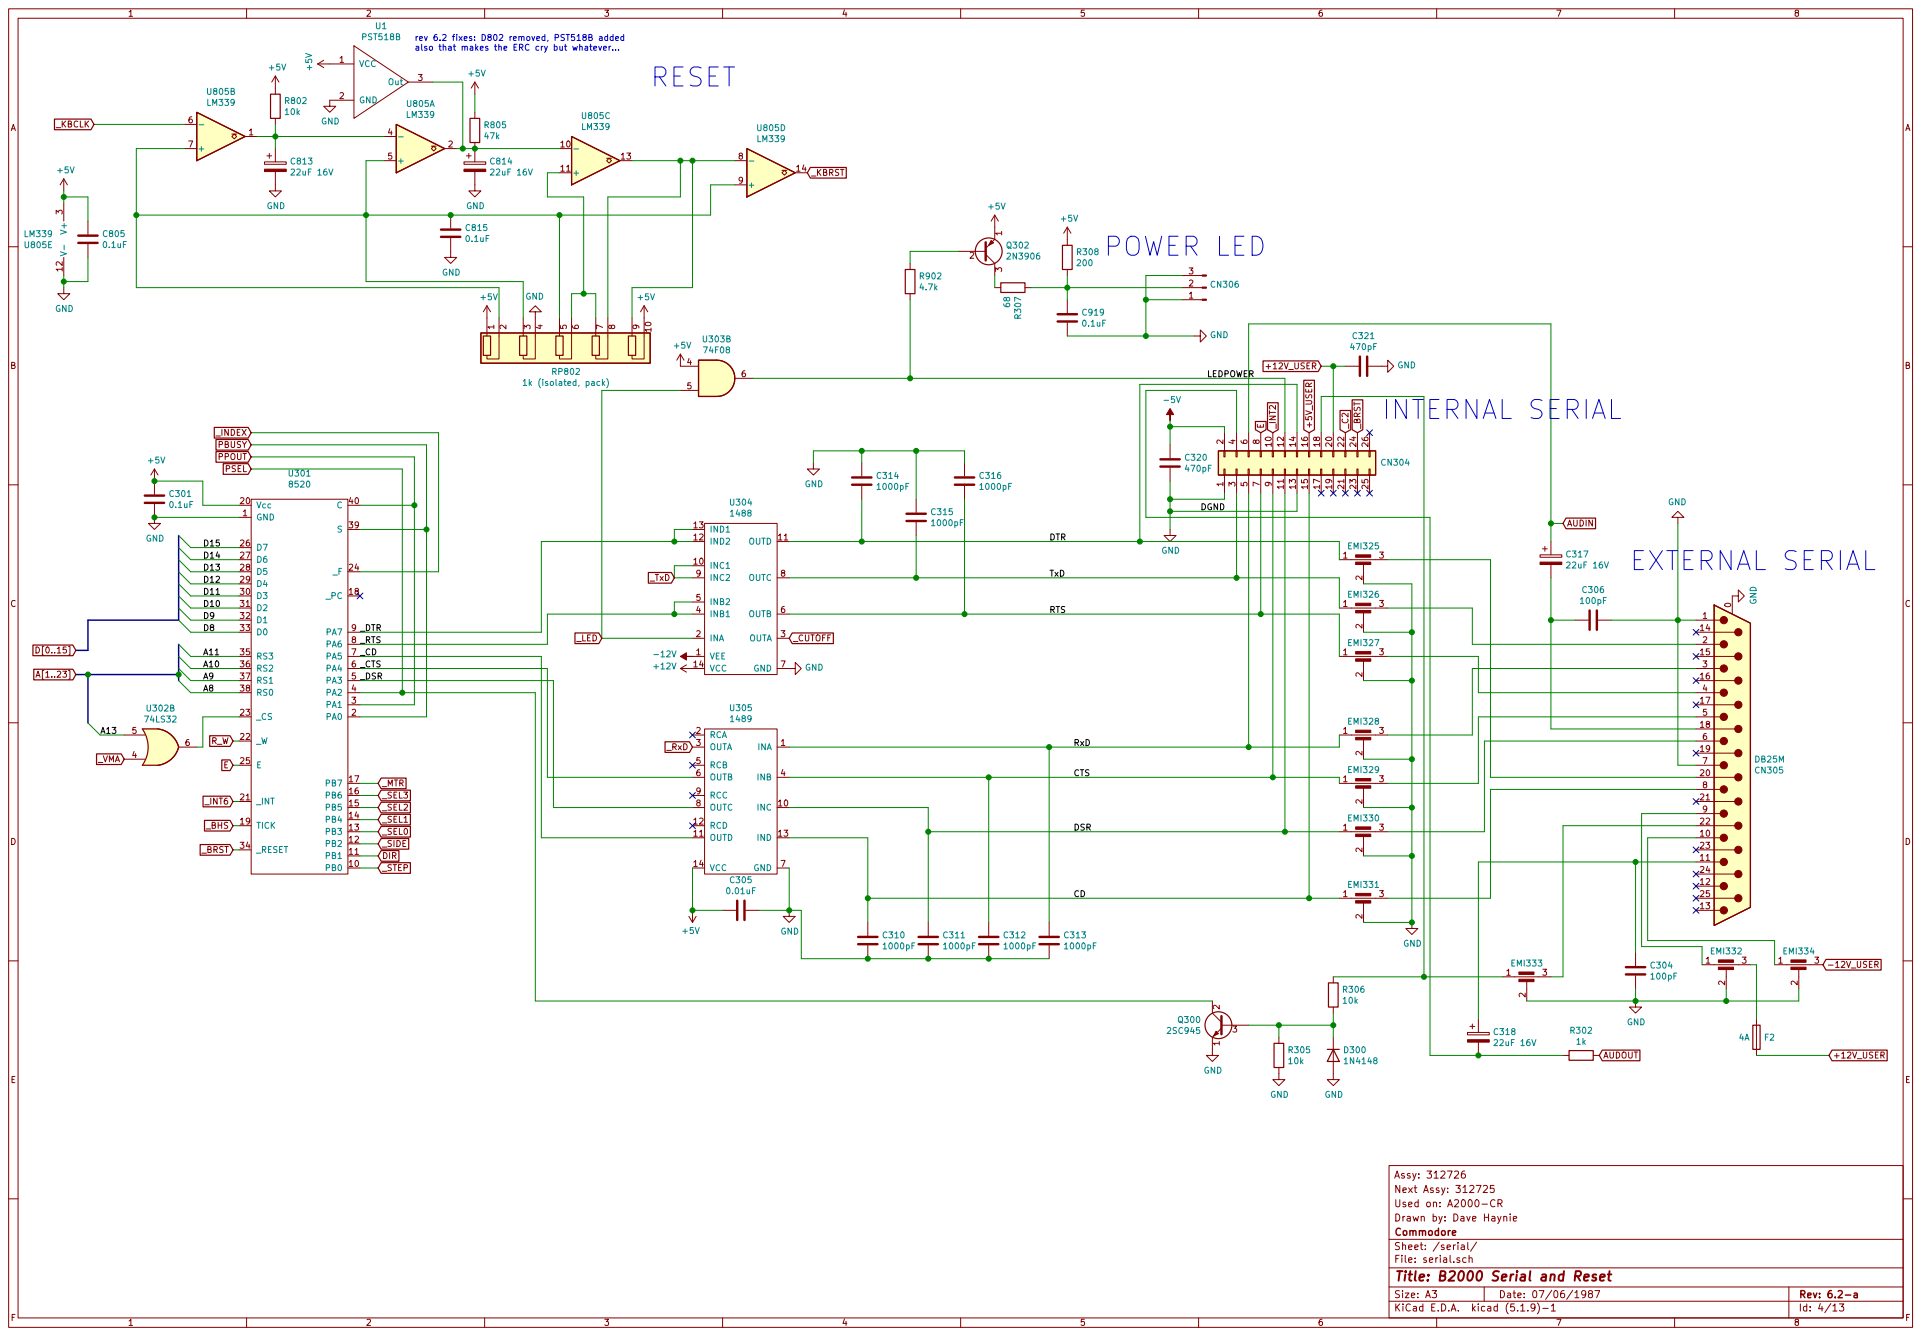
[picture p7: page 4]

rev 6.2 fixes: D802 removed, PST518B added
also that makes the ERC cry but whatever...

TxD

_DTR

CTS DSR

Assy: 312726
Next Assy: 312725
Id: 4/13 Title: B2000 Serial and Reset File: serial.sch Sheet: /serial/ Commodore Drawn by: Dave Haynie Used on: A2000-CR

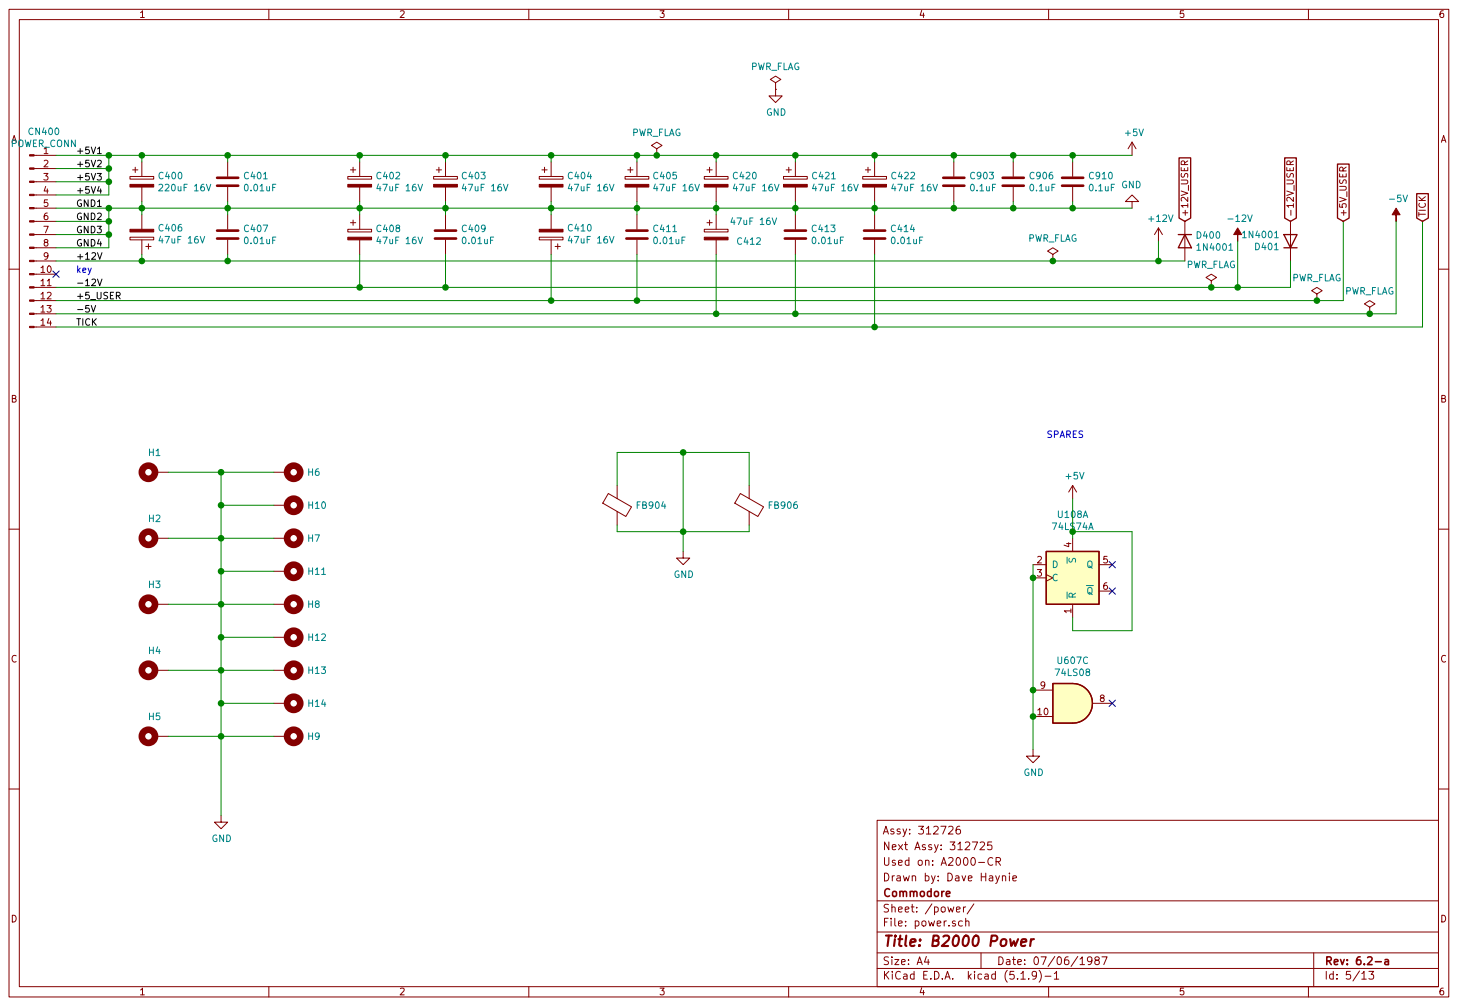
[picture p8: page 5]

Next Assy: 312725
Sheet: /power/ Commodore Drawn by: Dave Haynie Used on: A2000-CR

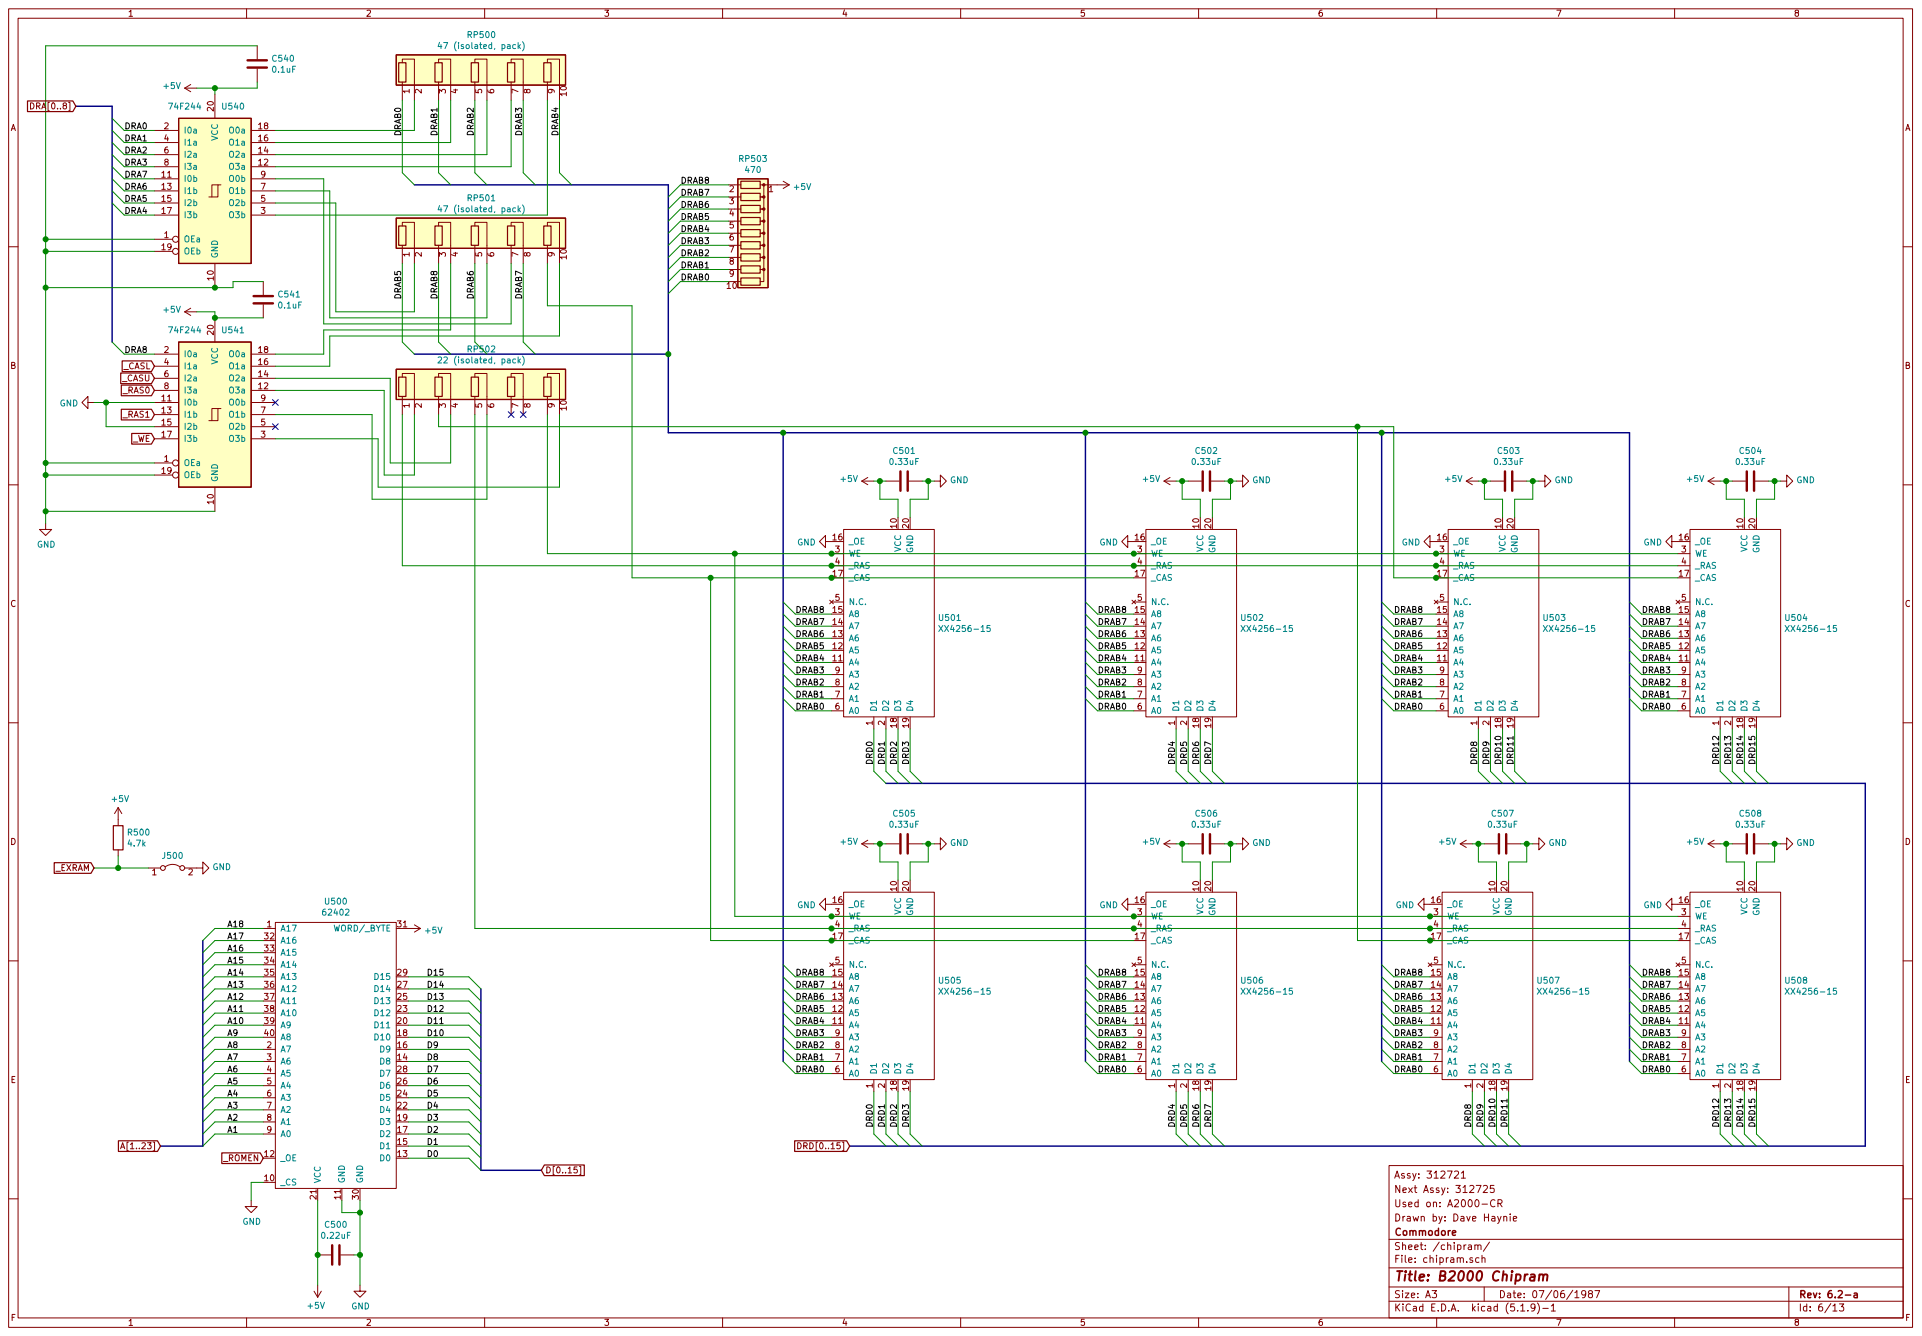
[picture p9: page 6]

Assy: 312721
Next Assy: 312725
Sheet: /chipram/ Commodore Drawn by: Dave Haynie Used on: A2000-CR

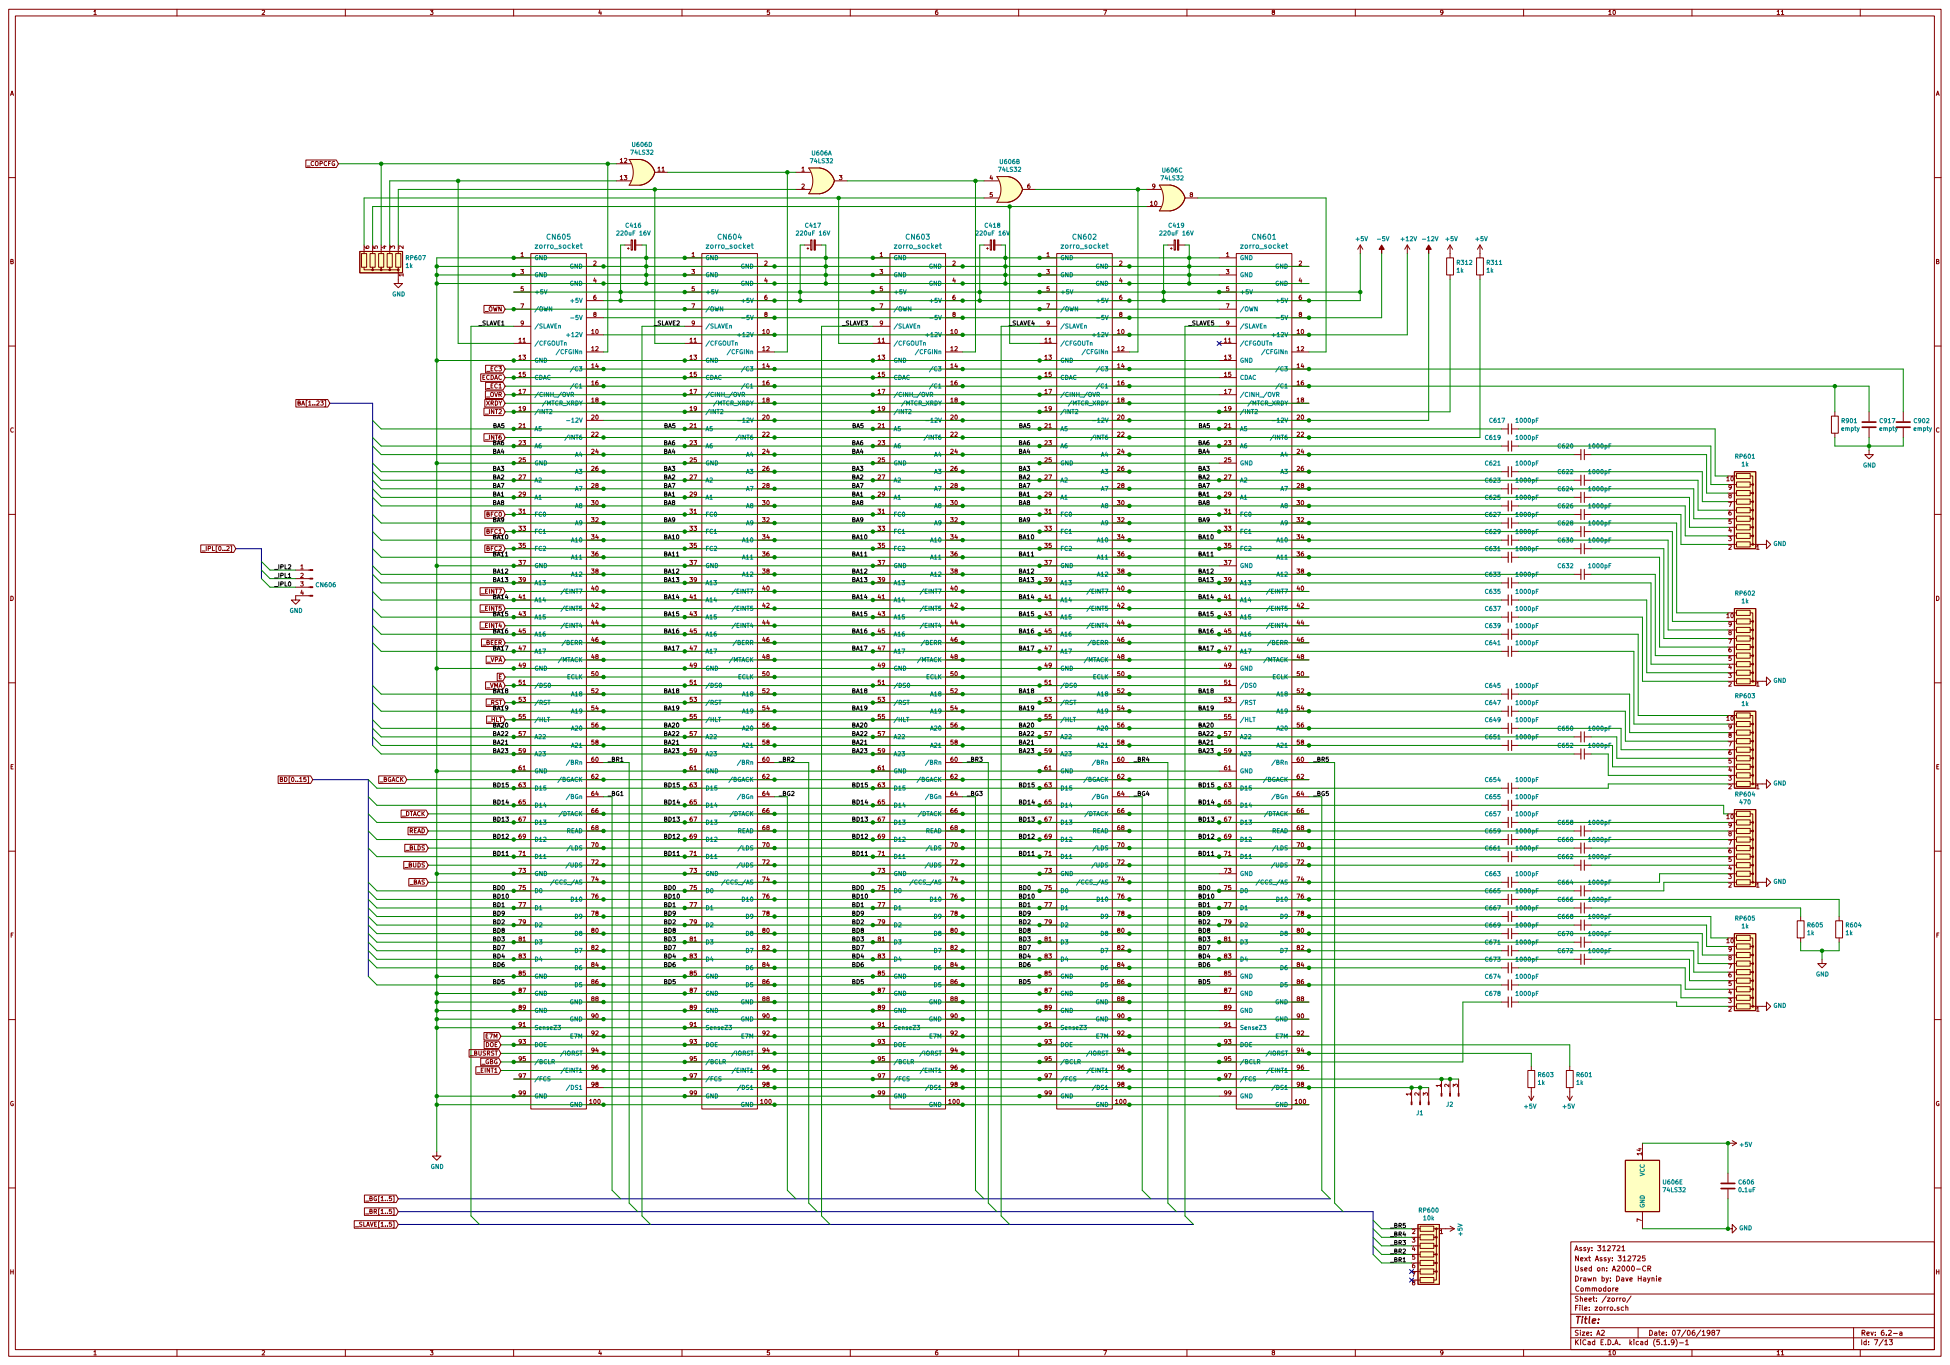
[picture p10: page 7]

Assy: 312721
Next Assy: 312725
Id: 7/13 Title: File: zorro.sch Sheet: /zorro/ Commodore Drawn by: Dave Haynie Used on: A2000-CR

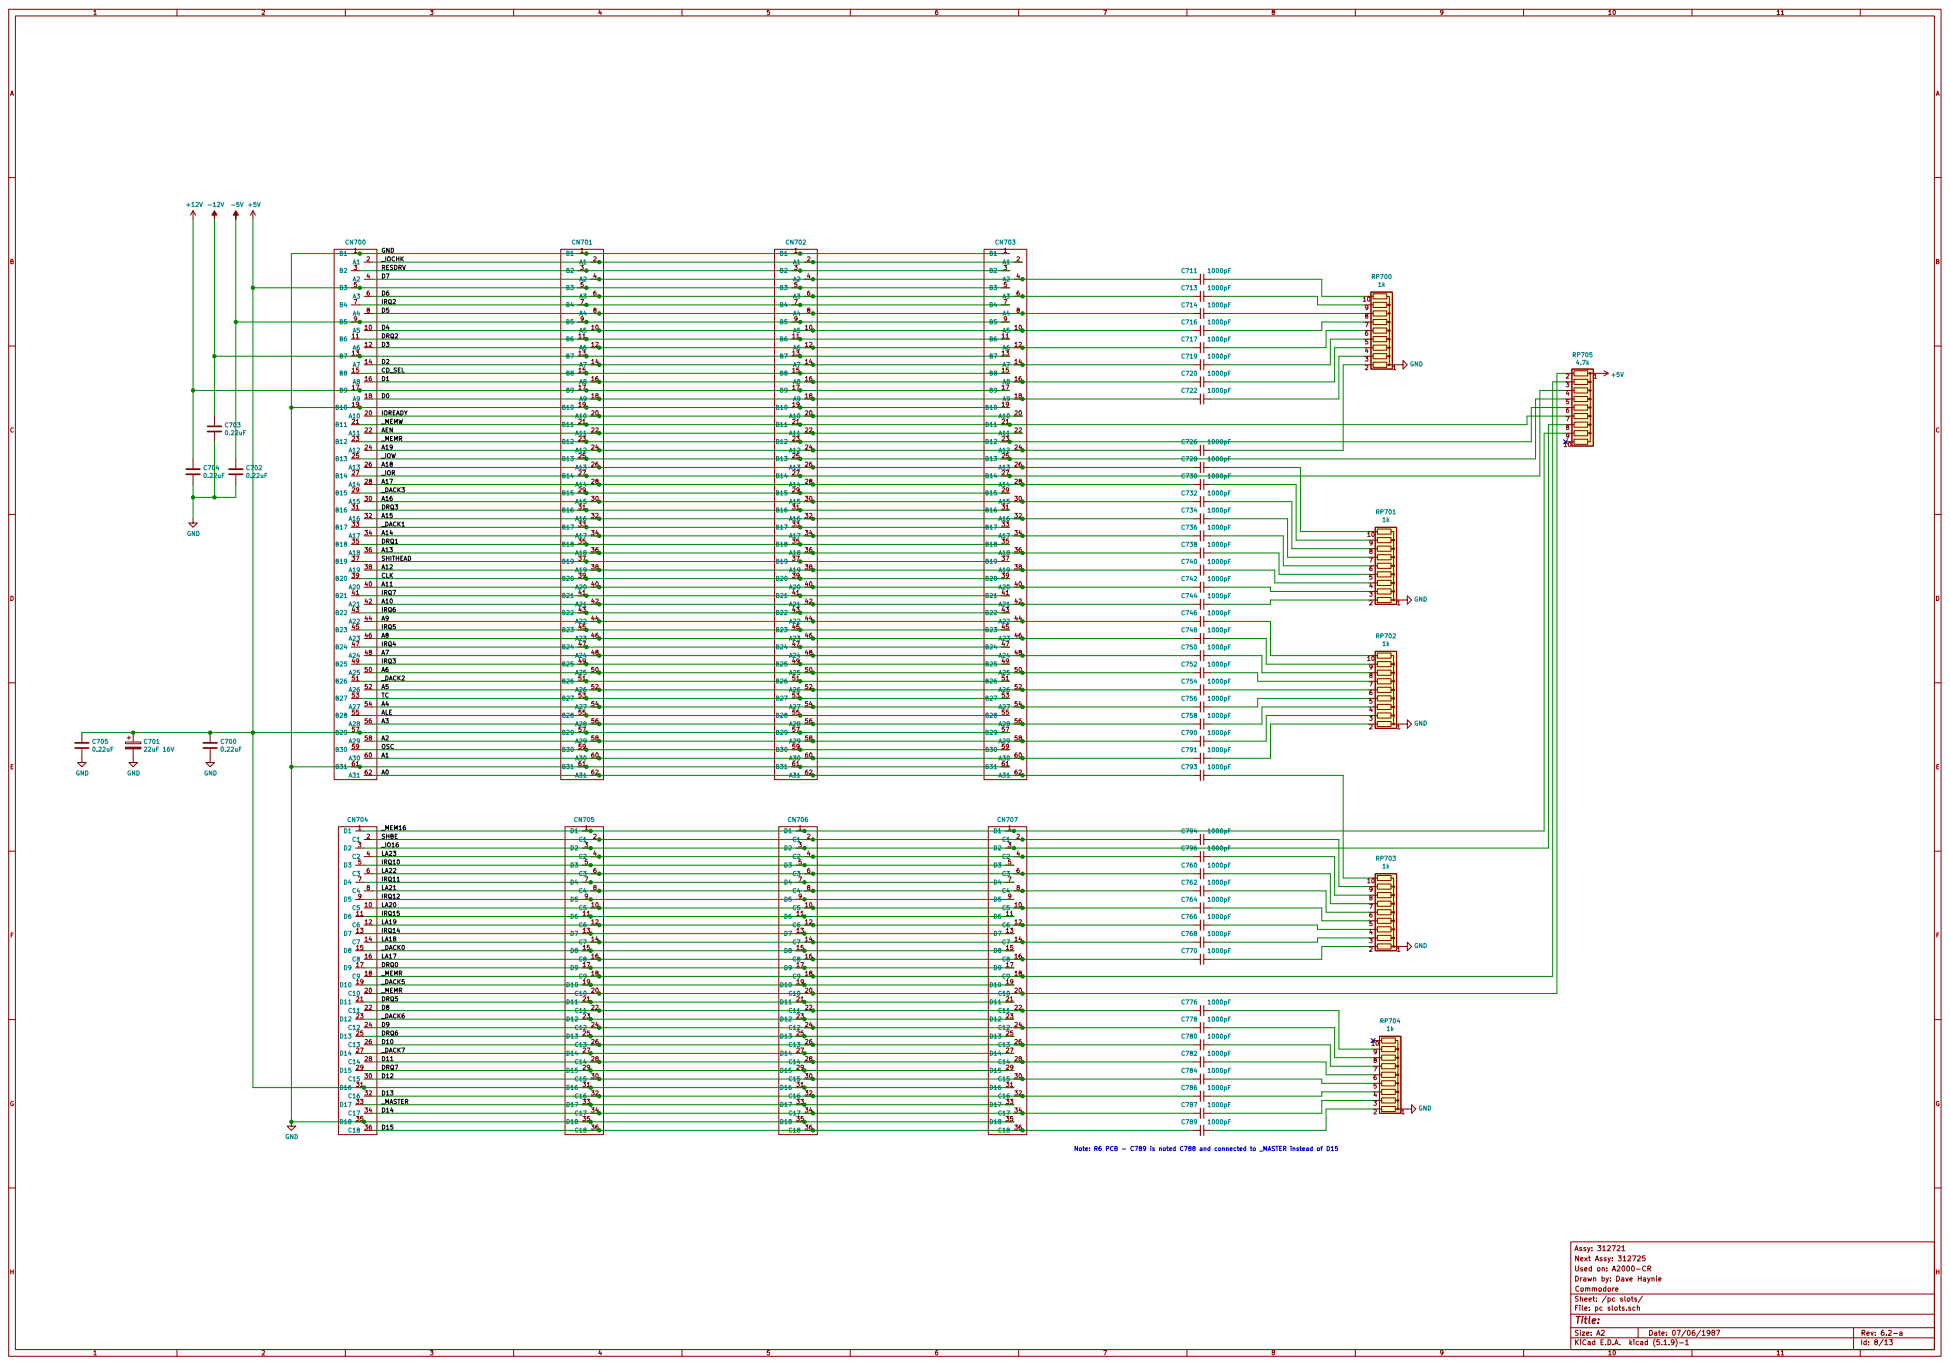
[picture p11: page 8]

Note: R6 PCB - C789 is noted C788 and connected to _MASTER instead of D15

Assy: 312721
Next Assy: 312725
Sheet: /pc slots/ Commodore Drawn by: Dave Haynie Used on: A2000-CR

File: pc slots.sch
Id: 8/13 Title:

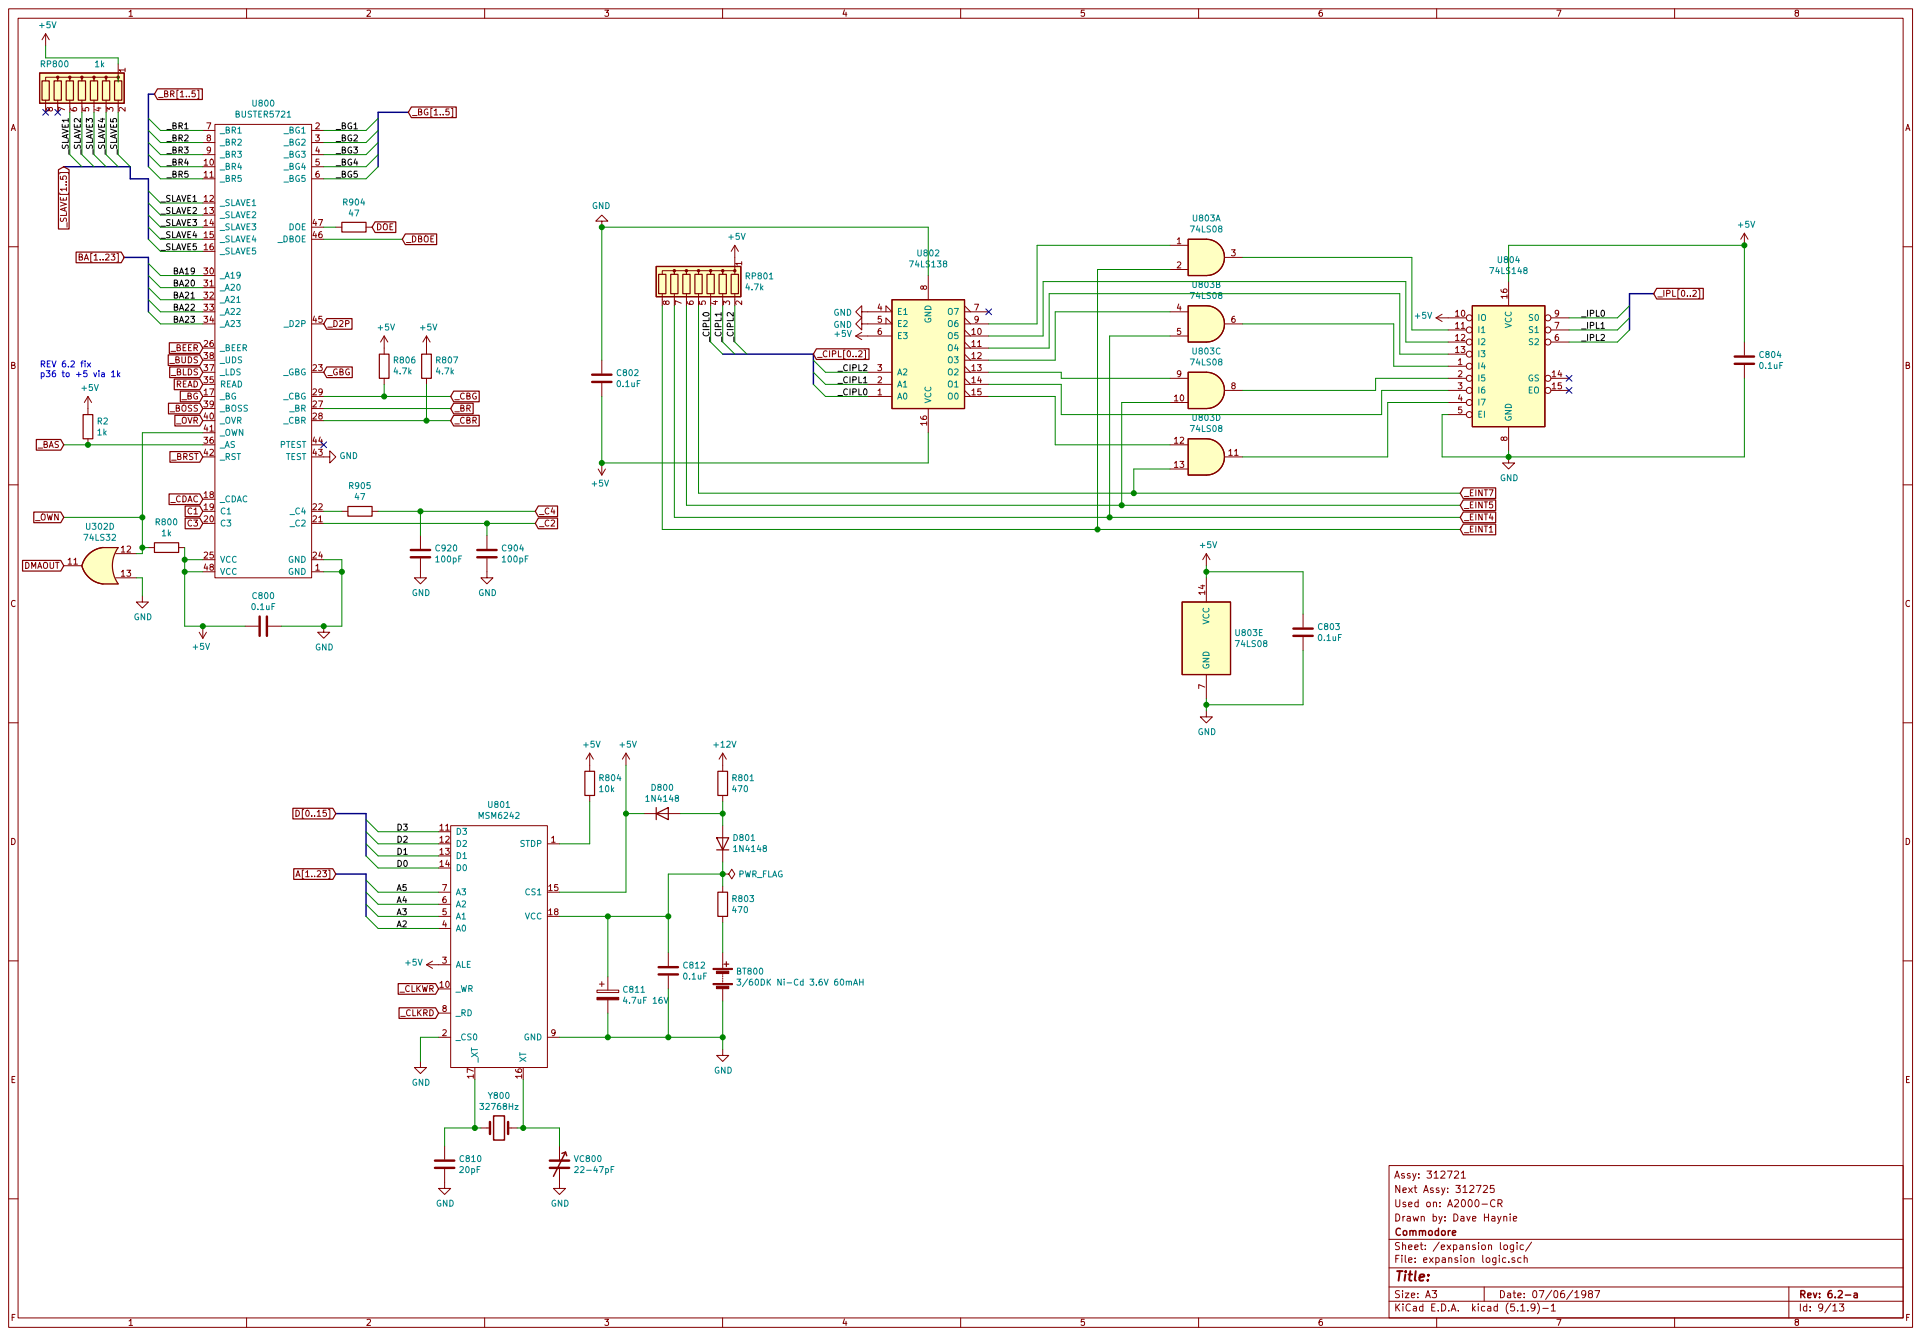
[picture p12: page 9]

_CIPL2 REV 6.2 fix p36 to +5 via 1k

Next Assy: 312725
Sheet: /expansion logic/ Commodore Drawn by: Dave Haynie Used on: A2000-CR

File: expansion logic.sch
Id: 9/13 Title:

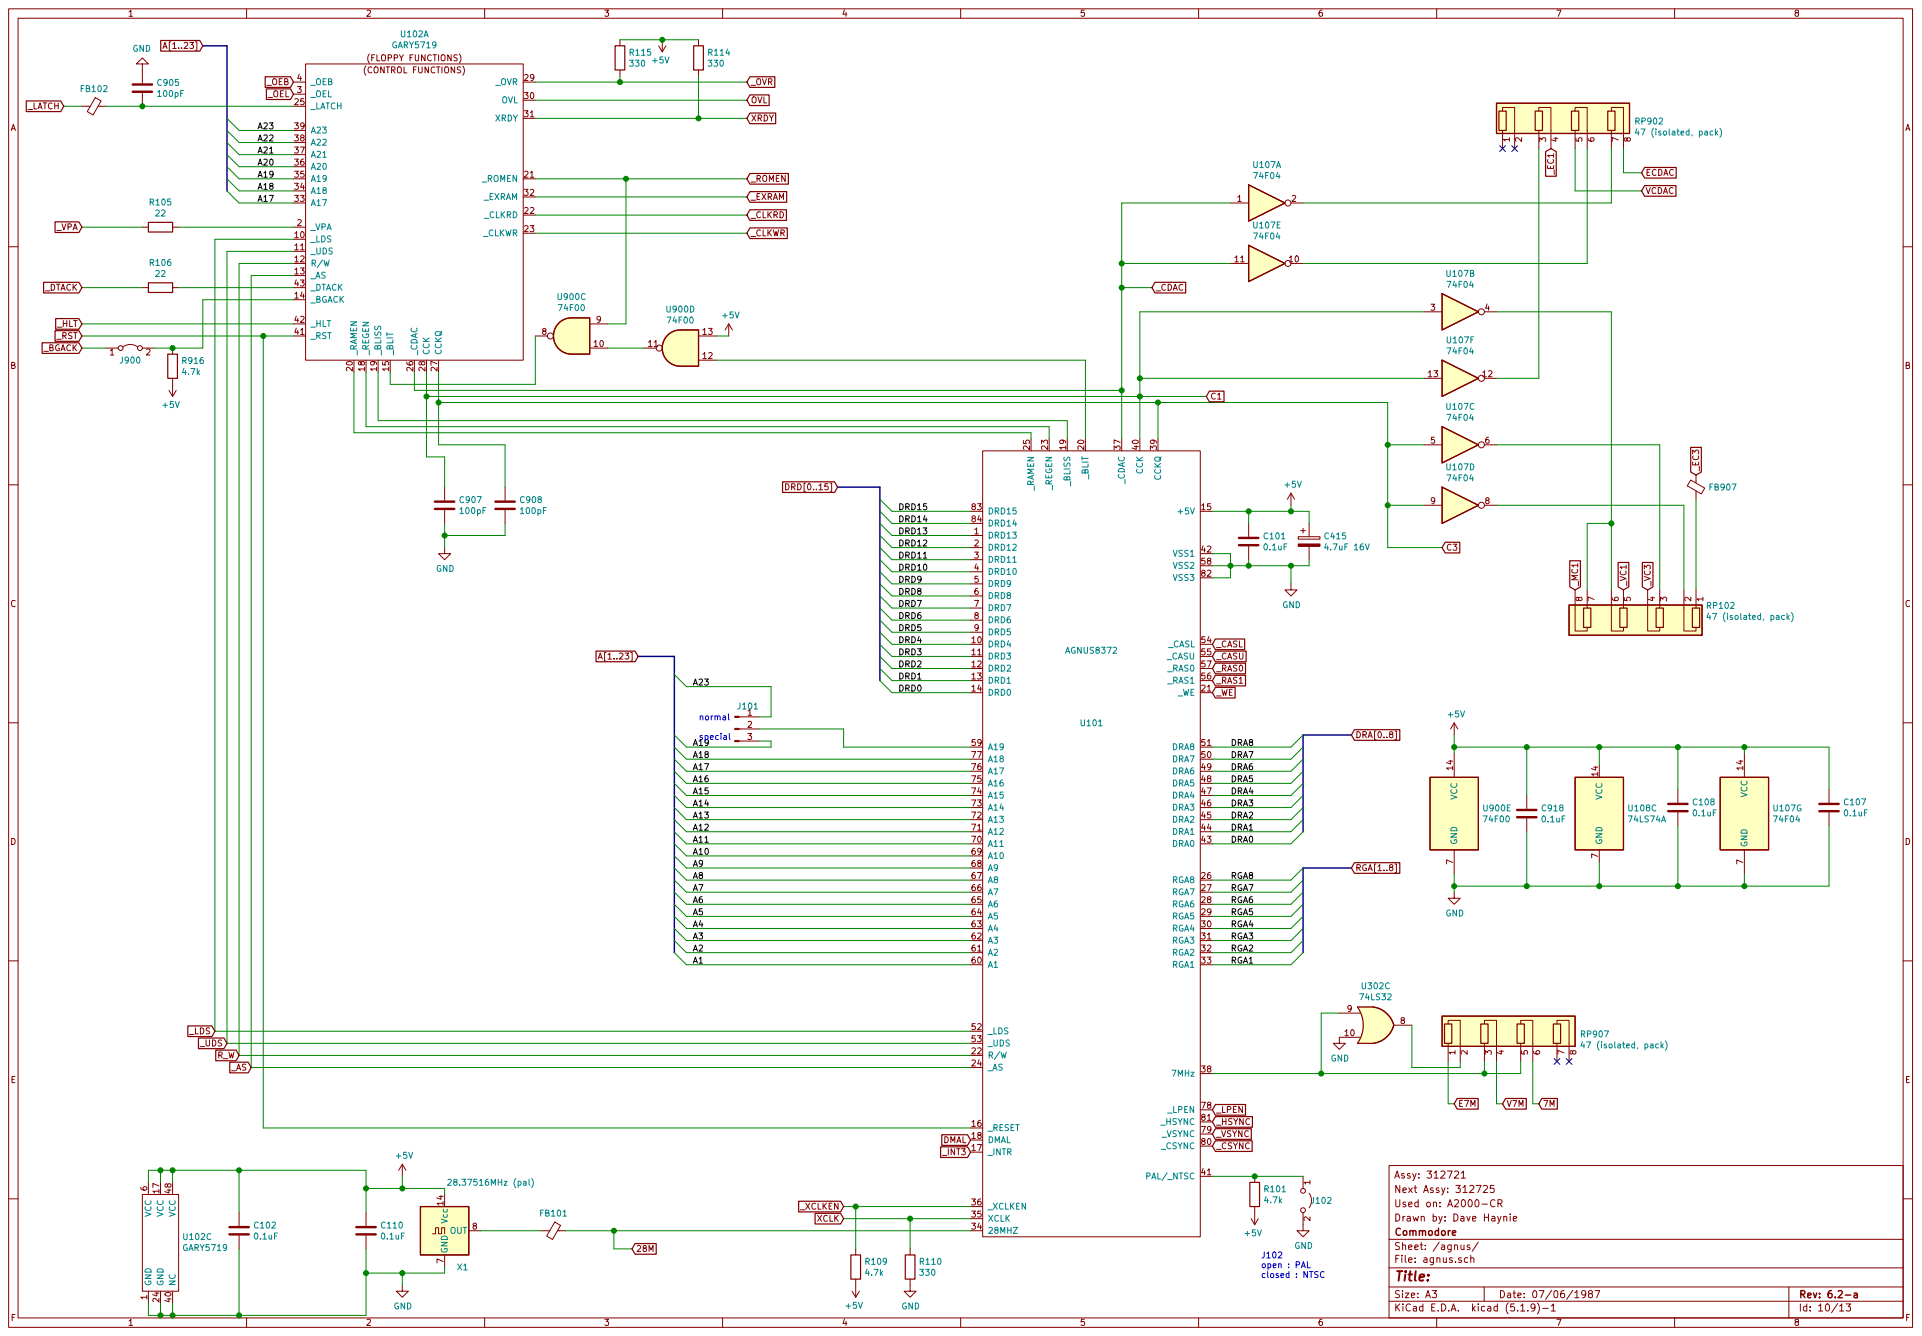
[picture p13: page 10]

Assy: 312721
Next Assy: 312725
Sheet: /agnus/ Commodore Drawn by: Dave Haynie Used on: A2000-CR

1 VCC 17 GND 24 NC 40 VCC 48 VCC

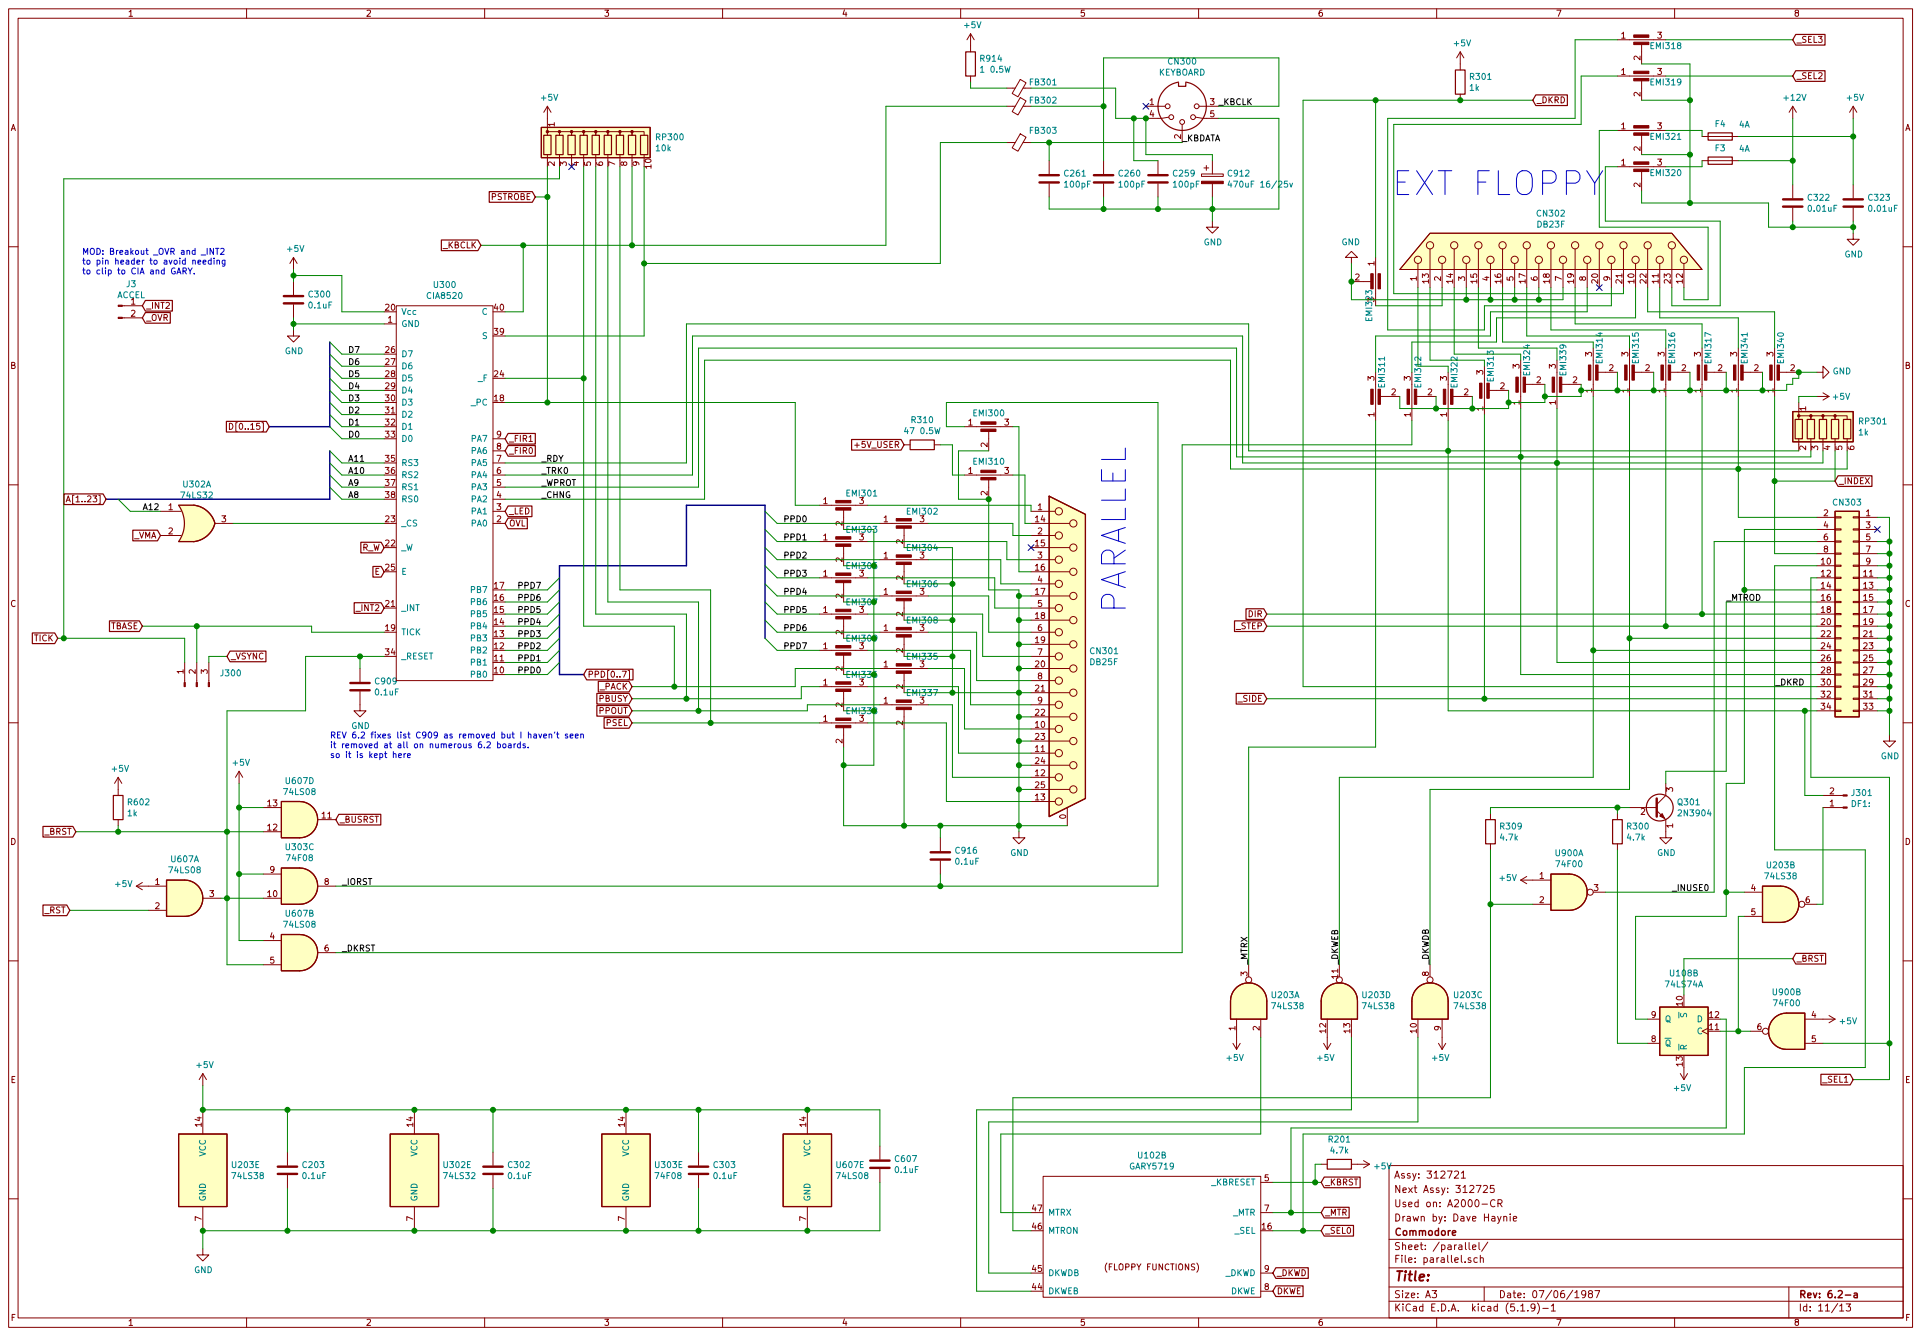
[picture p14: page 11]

MOD: Breakout _OVR and _INT2
to pin header to avoid needing
to clip to CIA and GARY.

_TRK0
_WPROT
_CHNG

_LED

20 | 19
22 | 21

26 | 25
28 | 27

REV 6.2 fixes list C909 as removed but I haven't seen
it removed at all on numerous 6.2 boards. so it is kept here

Assy: 312721
Next Assy: 312725
Sheet: /parallel/ Commodore Drawn by: Dave Haynie Used on: A2000-CR

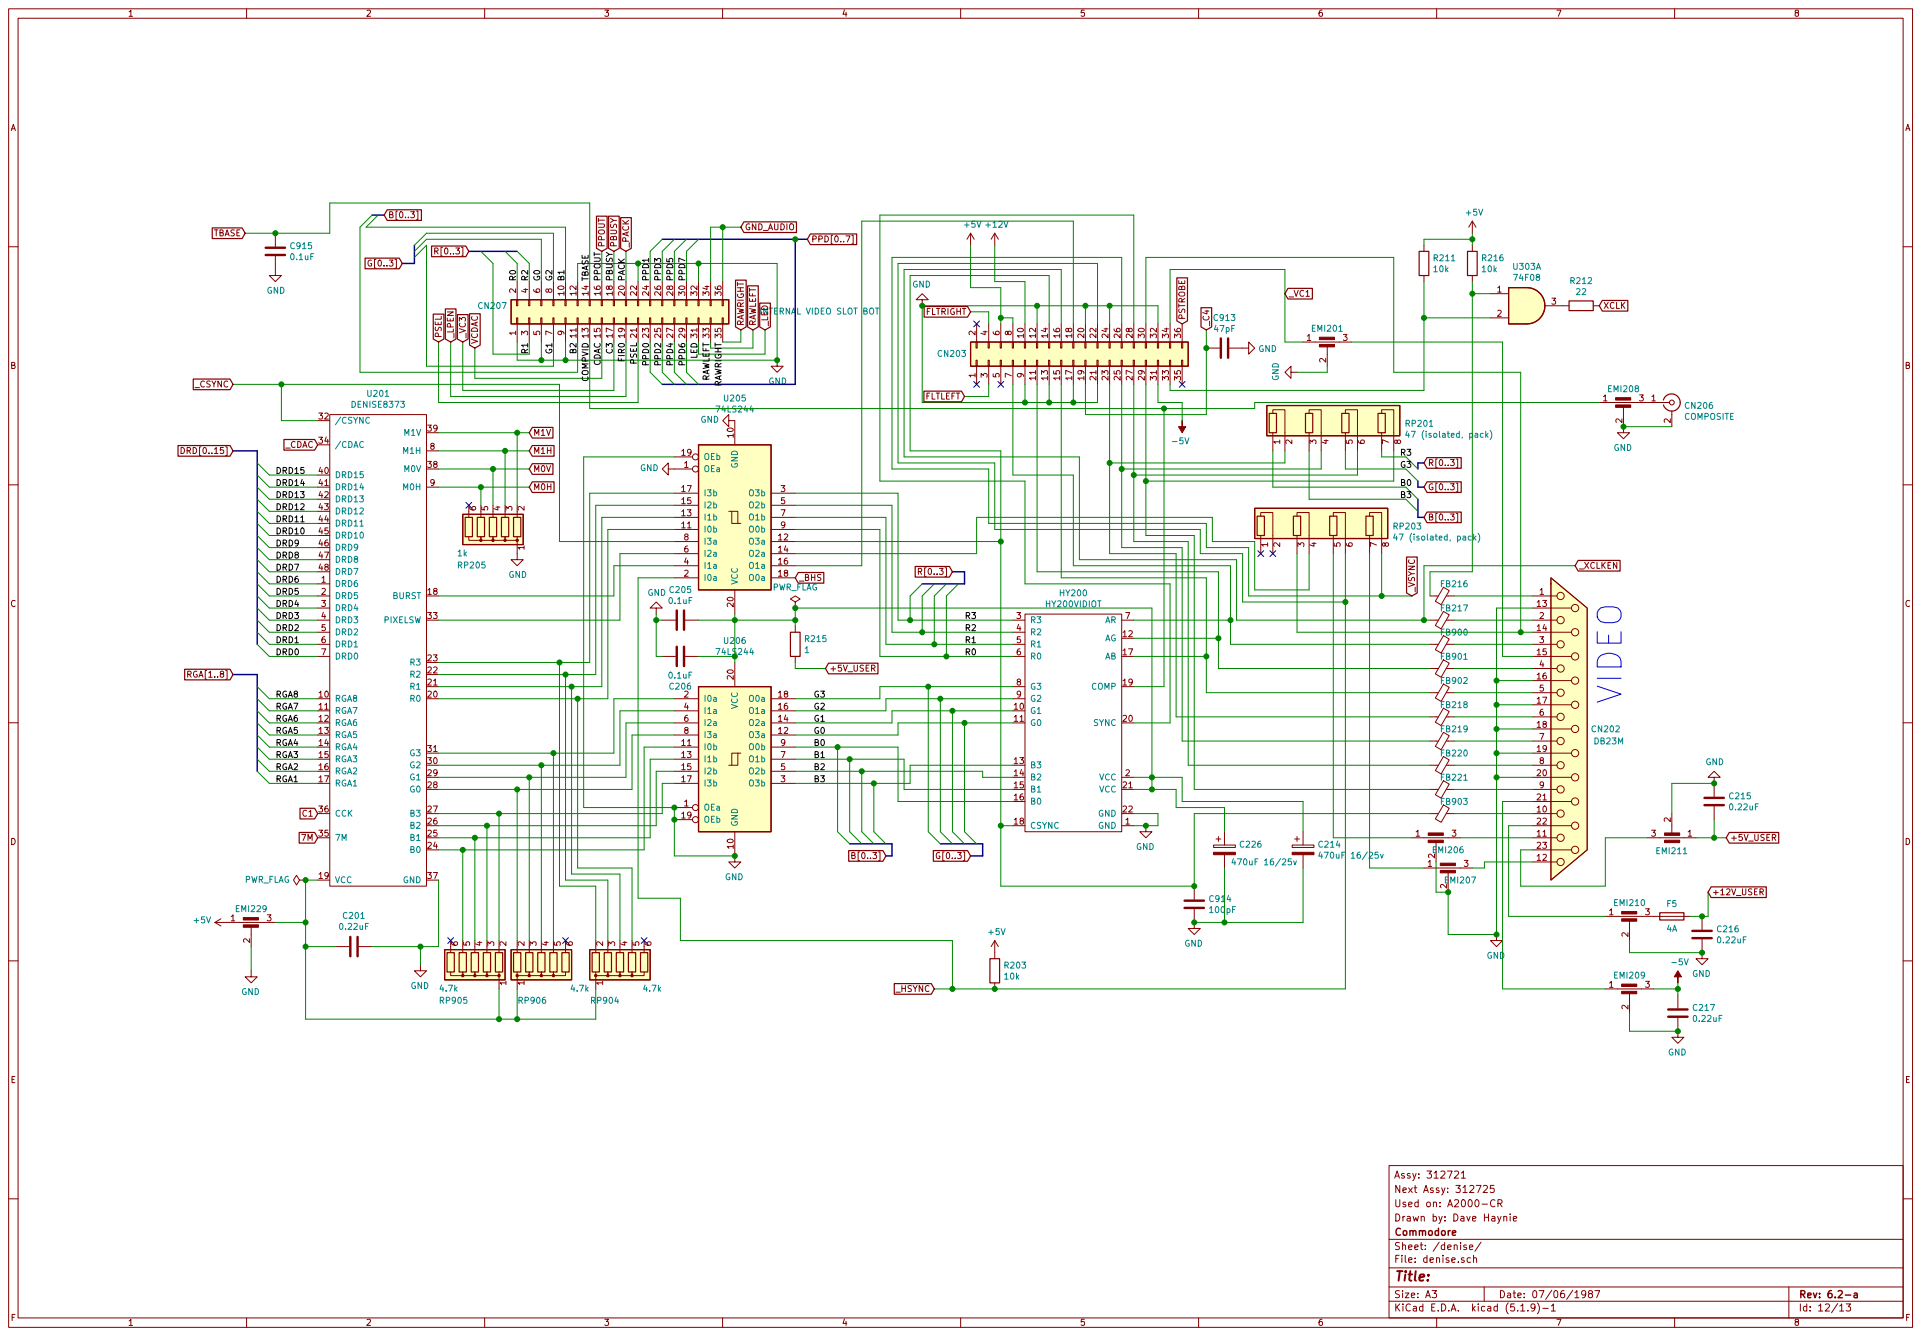
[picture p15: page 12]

9 CN207 INTERNAL VIDEO SLOT BOT

Assy: 312721
Next Assy: 312725
Id: 12/13 Title: File: denise.sch Sheet: /denise/ Commodore Drawn by: Dave Haynie Used on: A2000-CR


REV 6.2 fixes: RP900 and RP901, 3.3k both, connected to D[0..15] were removed
And instead connected directly to U603 and U604

Assy: 312721
Next Assy: 312725
Sheet: /coprocessor slot/ Commodore Drawn by: Dave Haynie Used on: A2000-CR

File: coprocessor slot.sch
Id: 13/13 Title:

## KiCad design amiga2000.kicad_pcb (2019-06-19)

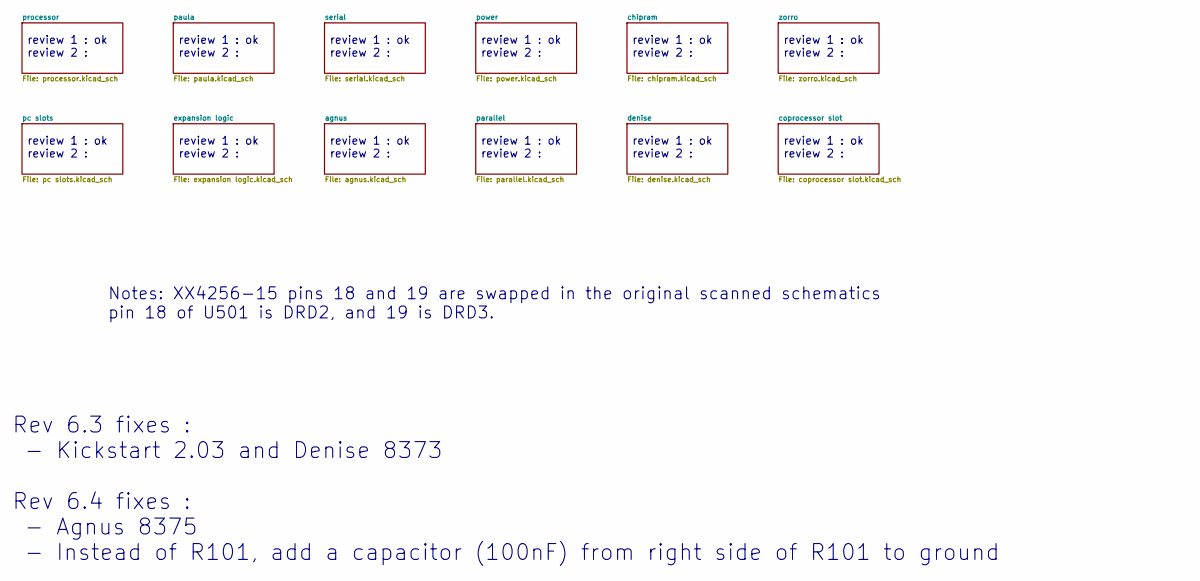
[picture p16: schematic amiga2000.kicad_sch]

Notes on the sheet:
review 1 : ok review 2 :
Notes: XX4256-15 pins 18 and 19 are swapped in the original scanned schematics pin 18 of U501 is DRD2, and 19 is DRD3.
Rev 6.3 fixes : - Kickstart 2.03 and Denise 8373 Rev 6.4 fixes : - Agnus 8375 - Instead of R101, add a capacitor (100nF) from right side of R101 to ground

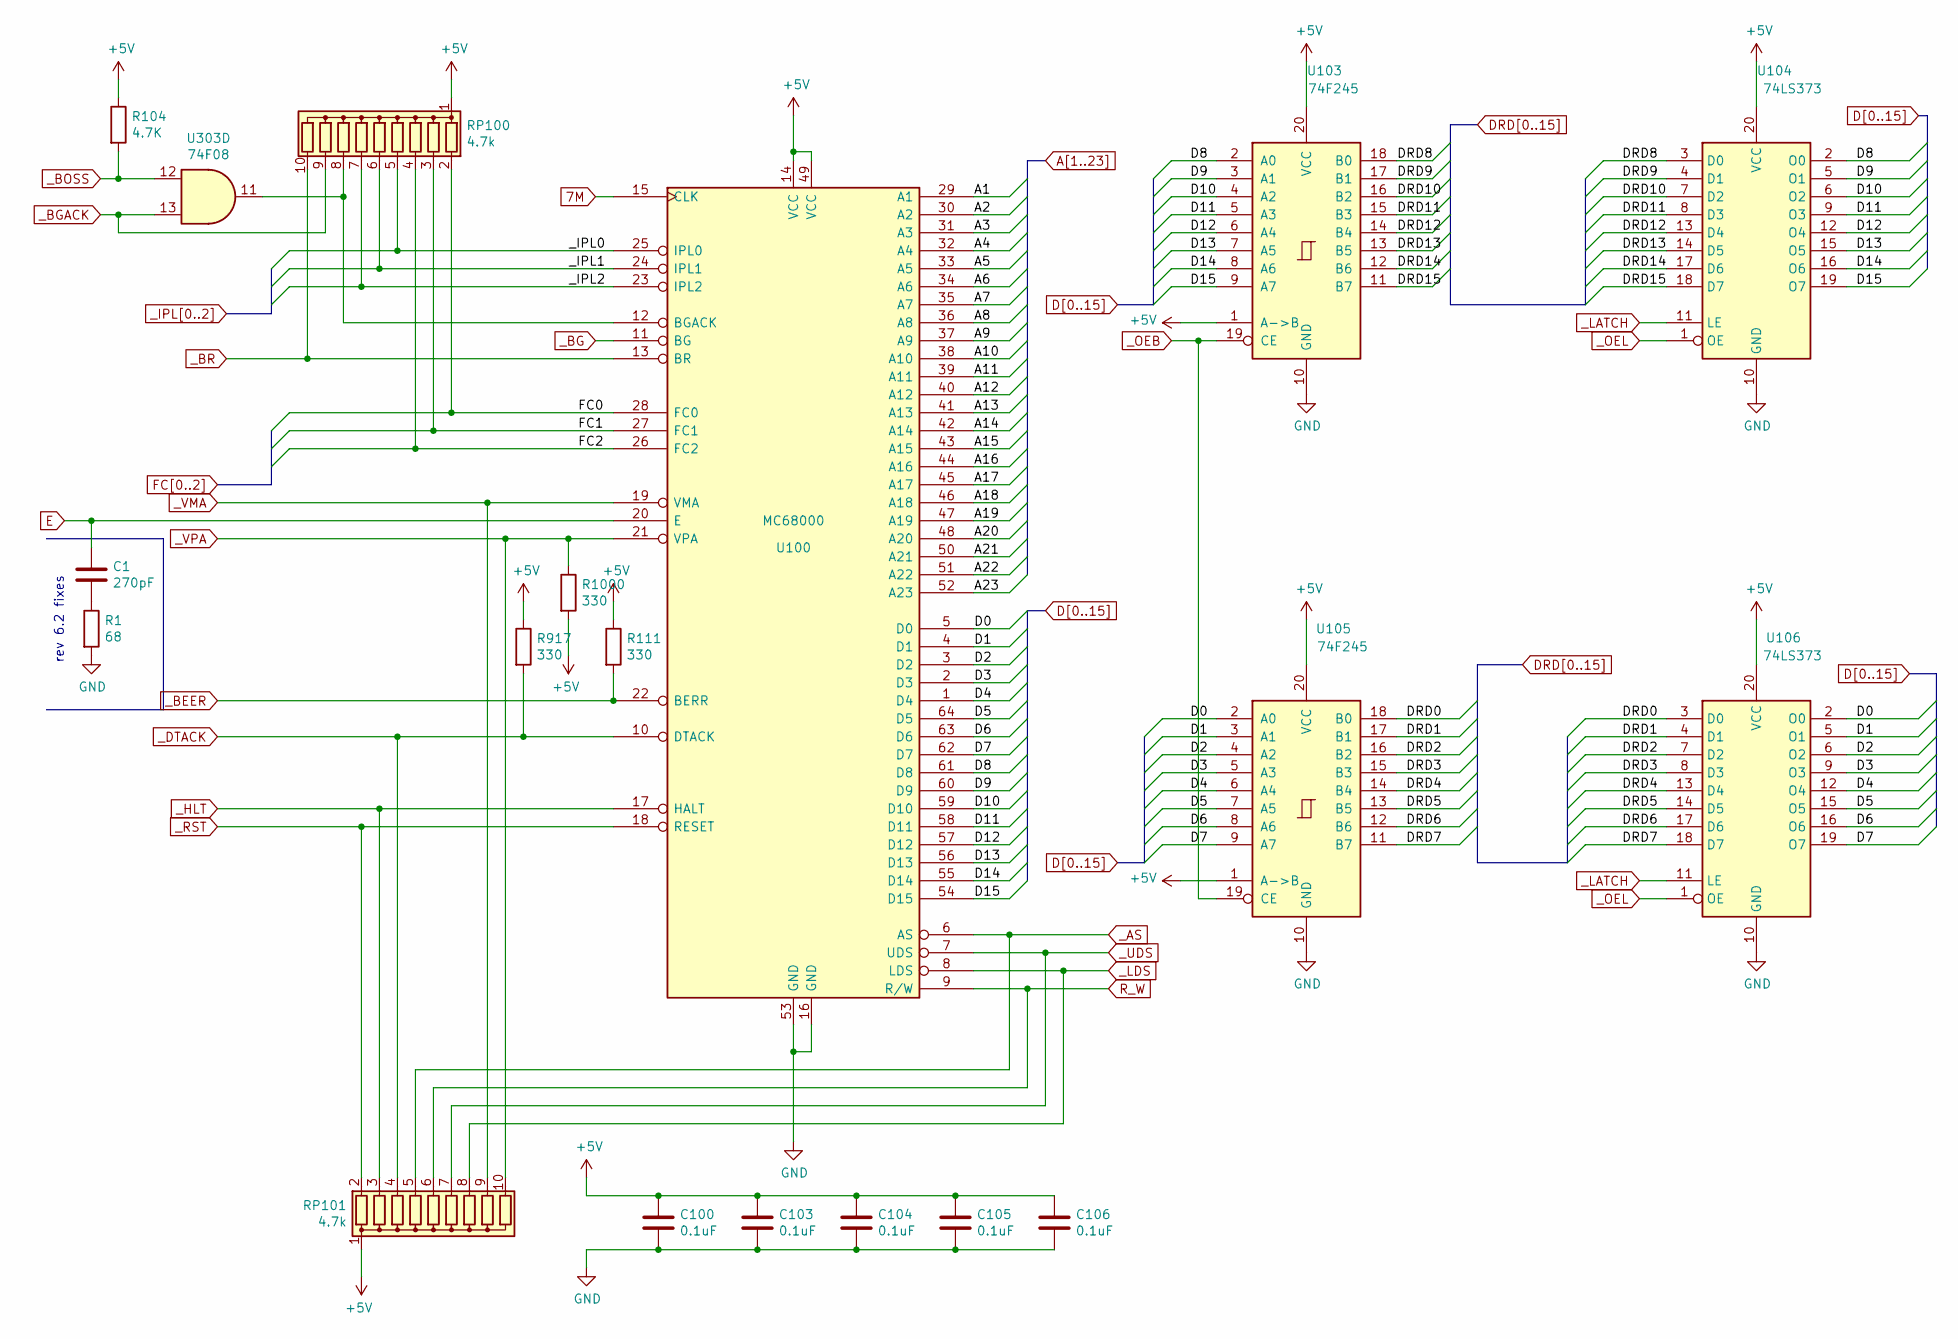
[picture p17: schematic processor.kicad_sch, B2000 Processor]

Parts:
C1: 270pF; C_Rect_L11.5mm_W2.6mm_P10.00mm_MKT
C100, C103, C104, C105, C106: 0.1uF; C_Rect_L11.5mm_W2.6mm_P10.00mm_MKT
R1: 68; R_Axial_DIN0207_L6.3mm_D2.5mm_P10.16mm_Horizontal
R104: 4.7K; R_Axial_DIN0207_L6.3mm_D2.5mm_P10.16mm_Horizontal
R111, R917, R1000: 330; R_Axial_DIN0207_L6.3mm_D2.5mm_P10.16mm_Horizontal
RP100, RP101: 4.7k; R_Array_SIP10
U100: MC68000; DIP-64_W22.86mm_Socket
U103, U105: 74F245; DIP-20_W7.62mm_Socket
U104, U106: 74LS373; DIP-20_W7.62mm_Socket
U303: 74F08; DIP-14_W7.62mm_Socket

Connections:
7M: U100.15 (CLK); also elsewhere on the board
A1: U100.29 (A1); also elsewhere on the board
A2: U100.30 (A2); also elsewhere on the board
A3: U100.31 (A3); also elsewhere on the board
A4: U100.32 (A4); also elsewhere on the board
A5: U100.33 (A5); also elsewhere on the board
A6: U100.34 (A6); also elsewhere on the board
A7: U100.35 (A7); also elsewhere on the board
A8: U100.36 (A8); also elsewhere on the board
A9: U100.37 (A9); also elsewhere on the board
A10: U100.38 (A10); also elsewhere on the board
A11: U100.39 (A11); also elsewhere on the board
A12: U100.40 (A12); also elsewhere on the board
A13: U100.41 (A13); also elsewhere on the board
A14: U100.42 (A14); also elsewhere on the board
A15: U100.43 (A15); also elsewhere on the board
A16: U100.44 (A16); also elsewhere on the board
A17: U100.45 (A17); also elsewhere on the board
A18: U100.46 (A18); also elsewhere on the board
A19: U100.47 (A19); also elsewhere on the board
A20: U100.48 (A20); also elsewhere on the board
A21: U100.50 (A21); also elsewhere on the board
A22: U100.51 (A22); also elsewhere on the board
A23: U100.52 (A23); also elsewhere on the board
D0: U100.5 (D0), U105.2 (A0), U106.2 (O0); also elsewhere on the board
D1: U100.4 (D1), U105.3 (A1), U106.5 (O1); also elsewhere on the board
D2: U100.3 (D2), U105.4 (A2), U106.6 (O2); also elsewhere on the board
D3: U100.2 (D3), U105.5 (A3), U106.9 (O3); also elsewhere on the board
D4: U100.1 (D4), U105.6 (A4), U106.12 (O4); also elsewhere on the board
D5: U100.64 (D5), U105.7 (A5), U106.15 (O5); also elsewhere on the board
D6: U100.63 (D6), U105.8 (A6), U106.16 (O6); also elsewhere on the board
D7: U100.62 (D7), U105.9 (A7), U106.19 (O7); also elsewhere on the board
D8: U100.61 (D8), U103.2 (A0), U104.2 (O0); also elsewhere on the board
D9: U100.60 (D9), U103.3 (A1), U104.5 (O1); also elsewhere on the board
D10: U100.59 (D10), U103.4 (A2), U104.6 (O2); also elsewhere on the board
D11: U100.58 (D11), U103.5 (A3), U104.9 (O3); also elsewhere on the board
D12: U100.57 (D12), U103.6 (A4), U104.12 (O4); also elsewhere on the board
D13: U100.56 (D13), U103.7 (A5), U104.15 (O5); also elsewhere on the board
D14: U100.55 (D14), U103.8 (A6), U104.16 (O6); also elsewhere on the board
D15: U100.54 (D15), U103.9 (A7), U104.19 (O7); also elsewhere on the board
DRD0: U105.18 (B0), U106.3 (D0); also elsewhere on the board
DRD1: U105.17 (B1), U106.4 (D1); also elsewhere on the board
DRD2: U105.16 (B2), U106.7 (D2); also elsewhere on the board
DRD3: U105.15 (B3), U106.8 (D3); also elsewhere on the board
DRD4: U105.14 (B4), U106.13 (D4); also elsewhere on the board
DRD5: U105.13 (B5), U106.14 (D5); also elsewhere on the board
DRD6: U105.12 (B6), U106.17 (D6); also elsewhere on the board
DRD7: U105.11 (B7), U106.18 (D7); also elsewhere on the board
DRD8: U103.18 (B0), U104.3 (D0); also elsewhere on the board
DRD9: U103.17 (B1), U104.4 (D1); also elsewhere on the board
DRD10: U103.16 (B2), U104.7 (D2); also elsewhere on the board
DRD11: U103.15 (B3), U104.8 (D3); also elsewhere on the board
DRD12: U103.14 (B4), U104.13 (D4); also elsewhere on the board
DRD13: U103.13 (B5), U104.14 (D5); also elsewhere on the board
DRD14: U103.12 (B6), U104.17 (D6); also elsewhere on the board
DRD15: U103.11 (B7), U104.18 (D7); also elsewhere on the board
E: C1.1, U100.20 (E); also elsewhere on the board
FC0: RP100.2 (R1), U100.28 (FC0); also elsewhere on the board
FC1: RP100.3 (R2), U100.27 (FC1); also elsewhere on the board
FC2: RP100.4 (R3), U100.26 (FC2); also elsewhere on the board
GND: C100.2, C103.2, C104.2, C105.2, C106.2, R1.2, U100.16 (GND), U100.53 (GND), U103.10 (GND), U104.10 (GND), U105.10 (GND), U106.10 (GND); also elsewhere on the board
unnamed: C1.2, R1.1
unnamed: RP100.8 (R7), U100.12 (BGACK), U303.11
R_W: RP101.6 (R5), U100.9 (R/W); also elsewhere on the board
_AS: RP101.5 (R4), U100.6 (AS); also elsewhere on the board
_BEER: R111.2, U100.22 (BERR); also elsewhere on the board
_BG: U100.11 (BG); also elsewhere on the board
_BGACK: RP100.9 (R8), U303.13; also elsewhere on the board
_BOSS: R104.2, U303.12; also elsewhere on the board
_BR: RP100.10 (R9), U100.13 (BR); also elsewhere on the board
_DTACK: R917.2, RP101.4 (R3), U100.10 (DTACK); also elsewhere on the board
_HLT: RP101.3 (R2), U100.17 (HALT); also elsewhere on the board
_IPL0: RP100.5 (R4), U100.25 (IPL0); also elsewhere on the board
_IPL1: RP100.6 (R5), U100.24 (IPL1); also elsewhere on the board
_IPL2: RP100.7 (R6), U100.23 (IPL2); also elsewhere on the board
_LATCH: U104.11 (LE), U106.11 (LE); also elsewhere on the board
_LDS: RP101.8 (R7), U100.8 (LDS); also elsewhere on the board
_OEB: U103.19 (CE), U105.19 (CE); also elsewhere on the board
_OEL: U104.1 (OE), U106.1 (OE); also elsewhere on the board
_RST: RP101.2 (R1), U100.18 (RESET); also elsewhere on the board
_UDS: RP101.7 (R6), U100.7 (UDS); also elsewhere on the board
_VMA: RP101.9 (R8), U100.19 (VMA); also elsewhere on the board
_VPA: R1000.1, RP101.10 (R9), U100.21 (VPA); also elsewhere on the board

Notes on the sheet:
rev 6.2 fixes

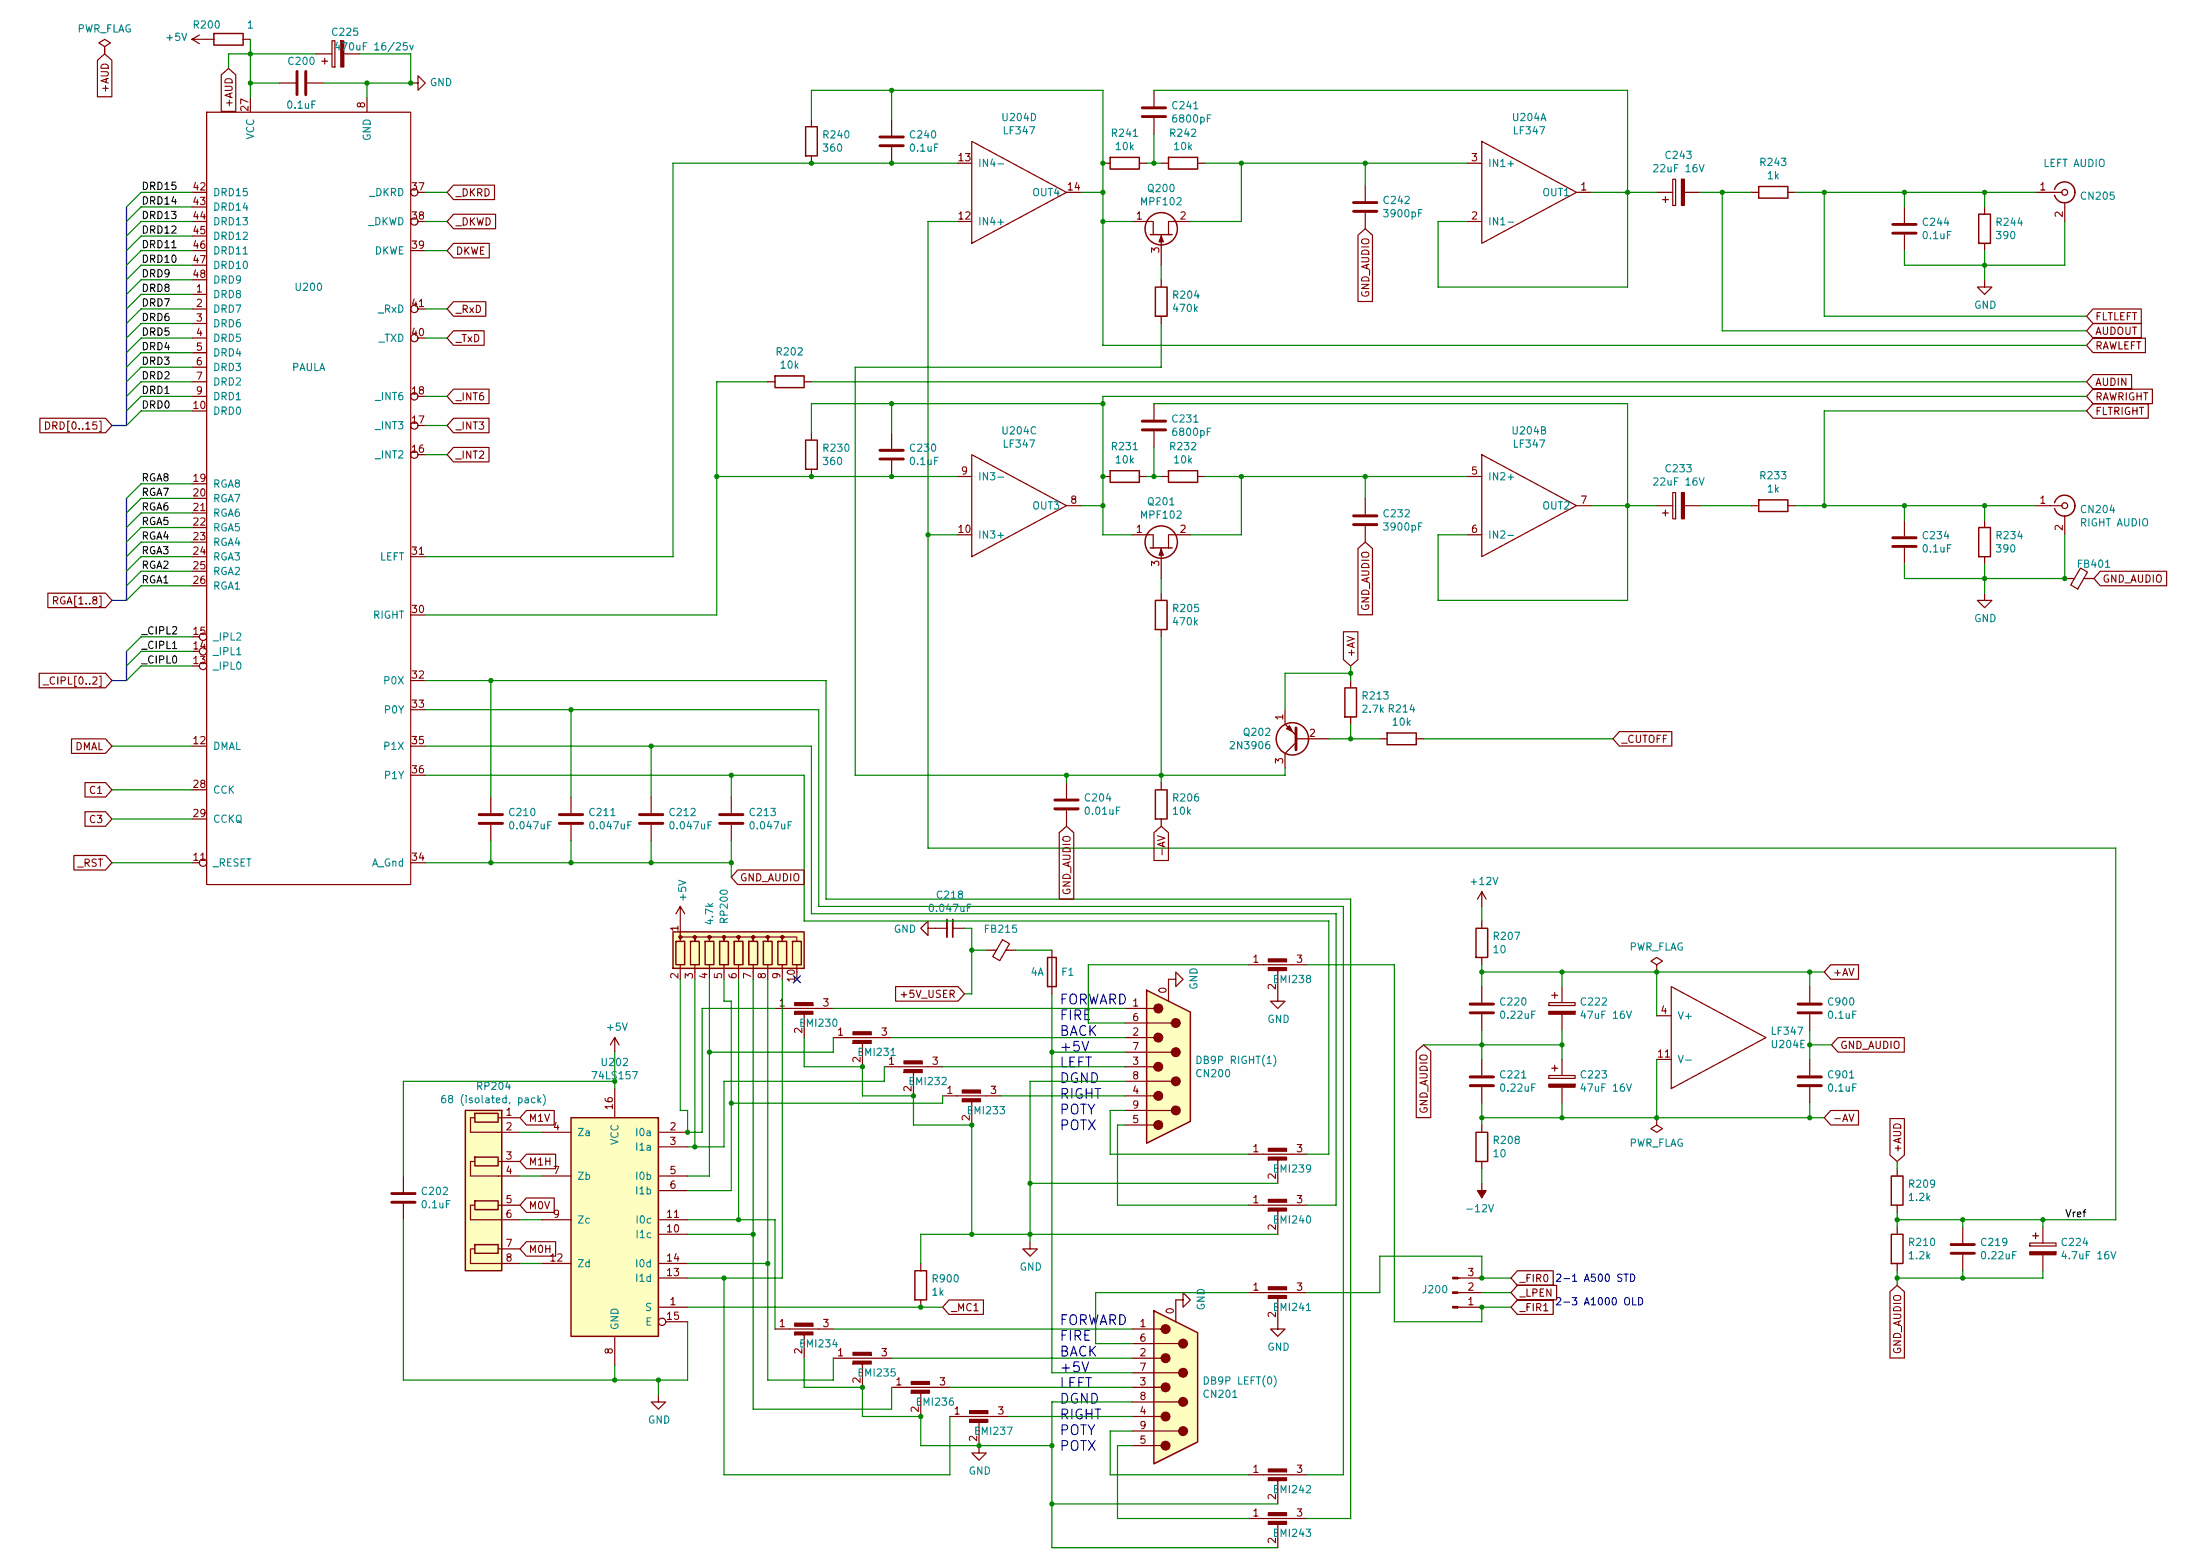
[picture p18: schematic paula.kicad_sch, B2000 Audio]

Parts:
C200, C202, C230, C234, C240, C244, C900, C901: 0.1uF; C_Rect_L11.5mm_W2.6mm_P10.00mm_MKT
C204: 0.01uF; C_Rect_L11.5mm_W2.6mm_P10.00mm_MKT
C210, C211, C212, C213, C218: 0.047uF; C_Rect_L11.5mm_W2.6mm_P10.00mm_MKT
C219, C220, C221: 0.22uF; C_Rect_L11.5mm_W2.6mm_P10.00mm_MKT
C222, C223: 47uF 16V; CP_Radial_Tantal_D5.5mm_P5.00mm
C224: 4.7uF 16V; CP_Radial_D5.0mm_P2.50mm
C225: 470uF 16/25v; CP_Radial_D10.0mm_P5.00mm
C231, C241: 6800pF; C_Rect_L11.5mm_W2.6mm_P10.00mm_MKT
C232, C242: 3900pF; C_Rect_L11.5mm_W2.6mm_P10.00mm_MKT
C233, C243: 22uF 16V; CP_Radial_Tantal_D5.0mm_P5.00mm
CN200: DB9P RIGHT(1); DSUB-9_Male_Horizontal_P2.77x2.84mm_EdgePinOffset7.70mm_Hou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
CN201: DB9P LEFT(0); DSUB-9_Male_Horizontal_P2.77x2.84mm_EdgePinOffset7.70mm_Hou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
CN204: RIGHT AUDIO; RCA
CN205: LEFT AUDIO; RCA
EMI230, EMI231, EMI232, EMI233, EMI234, EMI235, EMI236, EMI237, EMI238, EMI239, EMI240, EMI241, EMI242, EMI243: 6.8nF (Type F 682); EMI_FILTER
F1: 4A; C_Rect_L11.5mm_W2.0mm_P10.00mm_MKT
FB215, FB401: Ferrite_Bead_Small; L_Axial_L7.0mm_D3.3mm_P10.16mm_Horizontal_Fastron_MICC
J200: Conn_01x03_Male; PinHeader_1x03_P2.54mm_Vertical
Q200, Q201: MPF102; TO-92_Inline
Q202: 2N3906; TO-92_Inline
R200: 1; R_Axial_DIN0207_L6.3mm_D2.5mm_P10.16mm_Horizontal
R202, R206, R214, R231, R232, R241, R242: 10k; R_Axial_DIN0207_L6.3mm_D2.5mm_P10.16mm_Horizontal
R204, R205: 470k; R_Axial_DIN0207_L6.3mm_D2.5mm_P10.16mm_Horizontal
R207, R208: 10; R_Axial_DIN0207_L6.3mm_D2.5mm_P10.16mm_Horizontal
R209, R210: 1.2k; R_Axial_DIN0207_L6.3mm_D2.5mm_P10.16mm_Horizontal
R213: 2.7k; R_Axial_DIN0207_L6.3mm_D2.5mm_P10.16mm_Horizontal
R230, R240: 360; R_Axial_DIN0207_L6.3mm_D2.5mm_P10.16mm_Horizontal
R233, R243, R900: 1k; R_Axial_DIN0207_L6.3mm_D2.5mm_P10.16mm_Horizontal
R234, R244: 390; R_Axial_DIN0207_L6.3mm_D2.5mm_P10.16mm_Horizontal
RP200: 4.7k; R_Array_SIP10
RP204: 68 (isolated, pack); R_Array_SIP8
U200: PAULA; DIP-48_W15.24mm_Socket
U202: 74LS157; DIP-16_W7.62mm_Socket
U204: LF347; DIP-14_W7.62mm_Socket

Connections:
+5V_USER: C218.1, FB215.2; also elsewhere on the board
+12V: R207.1; also elsewhere on the board
+AUD: C200.2, C225.1, R200.1, R209.1, U200.27 (VCC)
+AV: C220.1, C222.1, C900.1, Q202.1 (E), R207.2, R213.1, U204.4 (V+)
-12V: R208.2; also elsewhere on the board
-AV: C221.2, C223.2, C901.2, R206.2, R208.1, U204.11 (V-)
/paula/Vref: C219.1, C224.1, R209.2, R210.1, U204.10 (IN3+), U204.12 (IN4+)
AUDIN: R202.1; also elsewhere on the board
AUDOUT: C243.2, R243.2; also elsewhere on the board
C1: U200.28 (CCK); also elsewhere on the board
C3: U200.29 (CCKQ); also elsewhere on the board
DKWE: U200.39 (DKWE); also elsewhere on the board
DMAL: U200.12 (DMAL); also elsewhere on the board
DRD0: U200.10 (DRD0); also elsewhere on the board
DRD1: U200.9 (DRD1); also elsewhere on the board
DRD2: U200.7 (DRD2); also elsewhere on the board
DRD3: U200.6 (DRD3); also elsewhere on the board
DRD4: U200.5 (DRD4); also elsewhere on the board
DRD5: U200.4 (DRD5); also elsewhere on the board
DRD6: U200.3 (DRD6); also elsewhere on the board
DRD7: U200.2 (DRD7); also elsewhere on the board
DRD8: U200.1 (DRD8); also elsewhere on the board
DRD9: U200.48 (DRD9); also elsewhere on the board
DRD10: U200.47 (DRD10); also elsewhere on the board
DRD11: U200.46 (DRD11); also elsewhere on the board
DRD12: U200.45 (DRD12); also elsewhere on the board
DRD13: U200.44 (DRD13); also elsewhere on the board
DRD14: U200.43 (DRD14); also elsewhere on the board
DRD15: U200.42 (DRD15); also elsewhere on the board
FLTLEFT: C244.1, CN205.1 (In), R243.1, R244.1; also elsewhere on the board
FLTRIGHT: C234.1, CN204.1 (In), R233.1, R234.1; also elsewhere on the board
GND: C200.1, C202.2, C218.2, C225.2, C234.2, C244.2, CN200.0 (PAD), CN200.8, CN201.0 (PAD), CN201.8, CN204.2 (Ext), CN205.2 (Ext), EMI230.2, EMI231.2, EMI232.2, EMI233.2, EMI234.2, EMI235.2, EMI236.2, EMI237.2, EMI238.2, EMI239.2, EMI240.2, EMI241.2, EMI242.2, EMI243.2, FB401.1, R234.2, R244.2, R900.1, U200.8 (GND), U202.8 (GND), U202.15 (E); also elsewhere on the board
GND_AUDIO: C204.2, C210.2, C211.2, C212.2, C213.2, C219.2, C220.2, C221.1, C222.2, C223.1, C224.2, C232.2, C242.2, C900.2, C901.1, FB401.2, R210.2, U200.34 (A_Gnd); also elsewhere on the board
M0H: RP204.7 (R4.1); also elsewhere on the board
M0V: RP204.5 (R3.1); also elsewhere on the board
M1H: RP204.3 (R2.1); also elsewhere on the board
M1V: RP204.1 (R1.1); also elsewhere on the board
unnamed: C204.1, Q202.3 (C), R204.2, R205.2, R206.1
unnamed: C210.1, EMI243.3, U200.32 (P0X)
unnamed: C211.1, EMI242.3, U200.33 (P0Y)
unnamed: C212.1, EMI240.3, U200.35 (P1X)
unnamed: C213.1, EMI239.3, U200.36 (P1Y)
unnamed: C230.2, R202.2, R230.2, U200.30 (RIGHT), U204.9 (IN3-)
unnamed: C231.1, C233.1, U204.6 (IN2-), U204.7 (OUT2)
unnamed: C231.2, R231.1, R232.2
unnamed: C232.1, Q201.2 (S), R232.1, U204.5 (IN2+)
unnamed: C233.2, R233.2
unnamed: C240.2, R240.2, U200.31 (LEFT), U204.13 (IN4-)
unnamed: C241.1, C243.1, U204.1 (OUT1), U204.2 (IN1-)
unnamed: C241.2, R241.1, R242.2
unnamed: C242.1, Q200.2 (S), R242.1, U204.3 (IN1+)
unnamed: EMI230.1, RP200.2 (R1), U202.2 (I0a)
unnamed: EMI231.1, RP200.4 (R3), U202.5 (I0b)
unnamed: EMI232.1, RP200.3 (R2), U202.3 (I1a)
unnamed: EMI233.1, RP200.5 (R4), U202.6 (I1b)
unnamed: EMI234.1, RP200.6 (R5), U202.11 (I0c)
unnamed: EMI235.1, RP200.8 (R7), U202.14 (I0d)
unnamed: EMI236.1, RP200.7 (R6), U202.10 (I1c)
unnamed: EMI237.1, RP200.9 (R8), U202.13 (I1d)
unnamed: F1.1, FB215.1
unnamed: Q200.3 (G), R204.1
unnamed: Q201.3 (G), R205.1
unnamed: Q202.2 (B), R213.2, R214.2
unnamed: RP204.2 (R1.2), U202.4 (Za)
unnamed: RP204.4 (R2.2), U202.7 (Zb)
unnamed: RP204.6 (R3.2), U202.9 (Zc)
unnamed: RP204.8 (R4.2), U202.12 (Zd)
RAWLEFT: C240.1, Q200.1 (D), R240.1, R241.2, U204.14 (OUT4); also elsewhere on the board
RAWRIGHT: C230.1, Q201.1 (D), R230.1, R231.2, U204.8 (OUT3); also elsewhere on the board
RGA1: U200.26 (RGA1); also elsewhere on the board
RGA2: U200.25 (RGA2); also elsewhere on the board
RGA3: U200.24 (RGA3); also elsewhere on the board
RGA4: U200.23 (RGA4); also elsewhere on the board
RGA5: U200.22 (RGA5); also elsewhere on the board
RGA6: U200.21 (RGA6); also elsewhere on the board
RGA7: U200.20 (RGA7); also elsewhere on the board
RGA8: U200.19 (RGA8); also elsewhere on the board
_CIPL0: U200.13 (_IPL0); also elsewhere on the board
_CIPL1: U200.14 (_IPL1); also elsewhere on the board
_CIPL2: U200.15 (_IPL2); also elsewhere on the board
_CUTOFF: R214.1; also elsewhere on the board
_DKWD: U200.38 (_DKWD); also elsewhere on the board
_FIR0: EMI241.3, J200.3; also elsewhere on the board
_FIR1: EMI238.3, J200.1; also elsewhere on the board
_INT2: U200.16 (_INT2); also elsewhere on the board
_INT3: U200.17 (_INT3); also elsewhere on the board
_INT6: U200.18 (_INT6); also elsewhere on the board
_LPEN: J200.2; also elsewhere on the board
_MC1: R900.2, U202.1 (S); also elsewhere on the board
_RST: U200.11 (_RESET); also elsewhere on the board
_RxD: U200.41 (_RxD); also elsewhere on the board
_TxD: U200.40 (_TXD); also elsewhere on the board

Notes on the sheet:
FORWARD FIRE BACK +5V LEFT DGND RIGHT POTY POTX
2-1 A500 STD 2-3 A1000 OLD

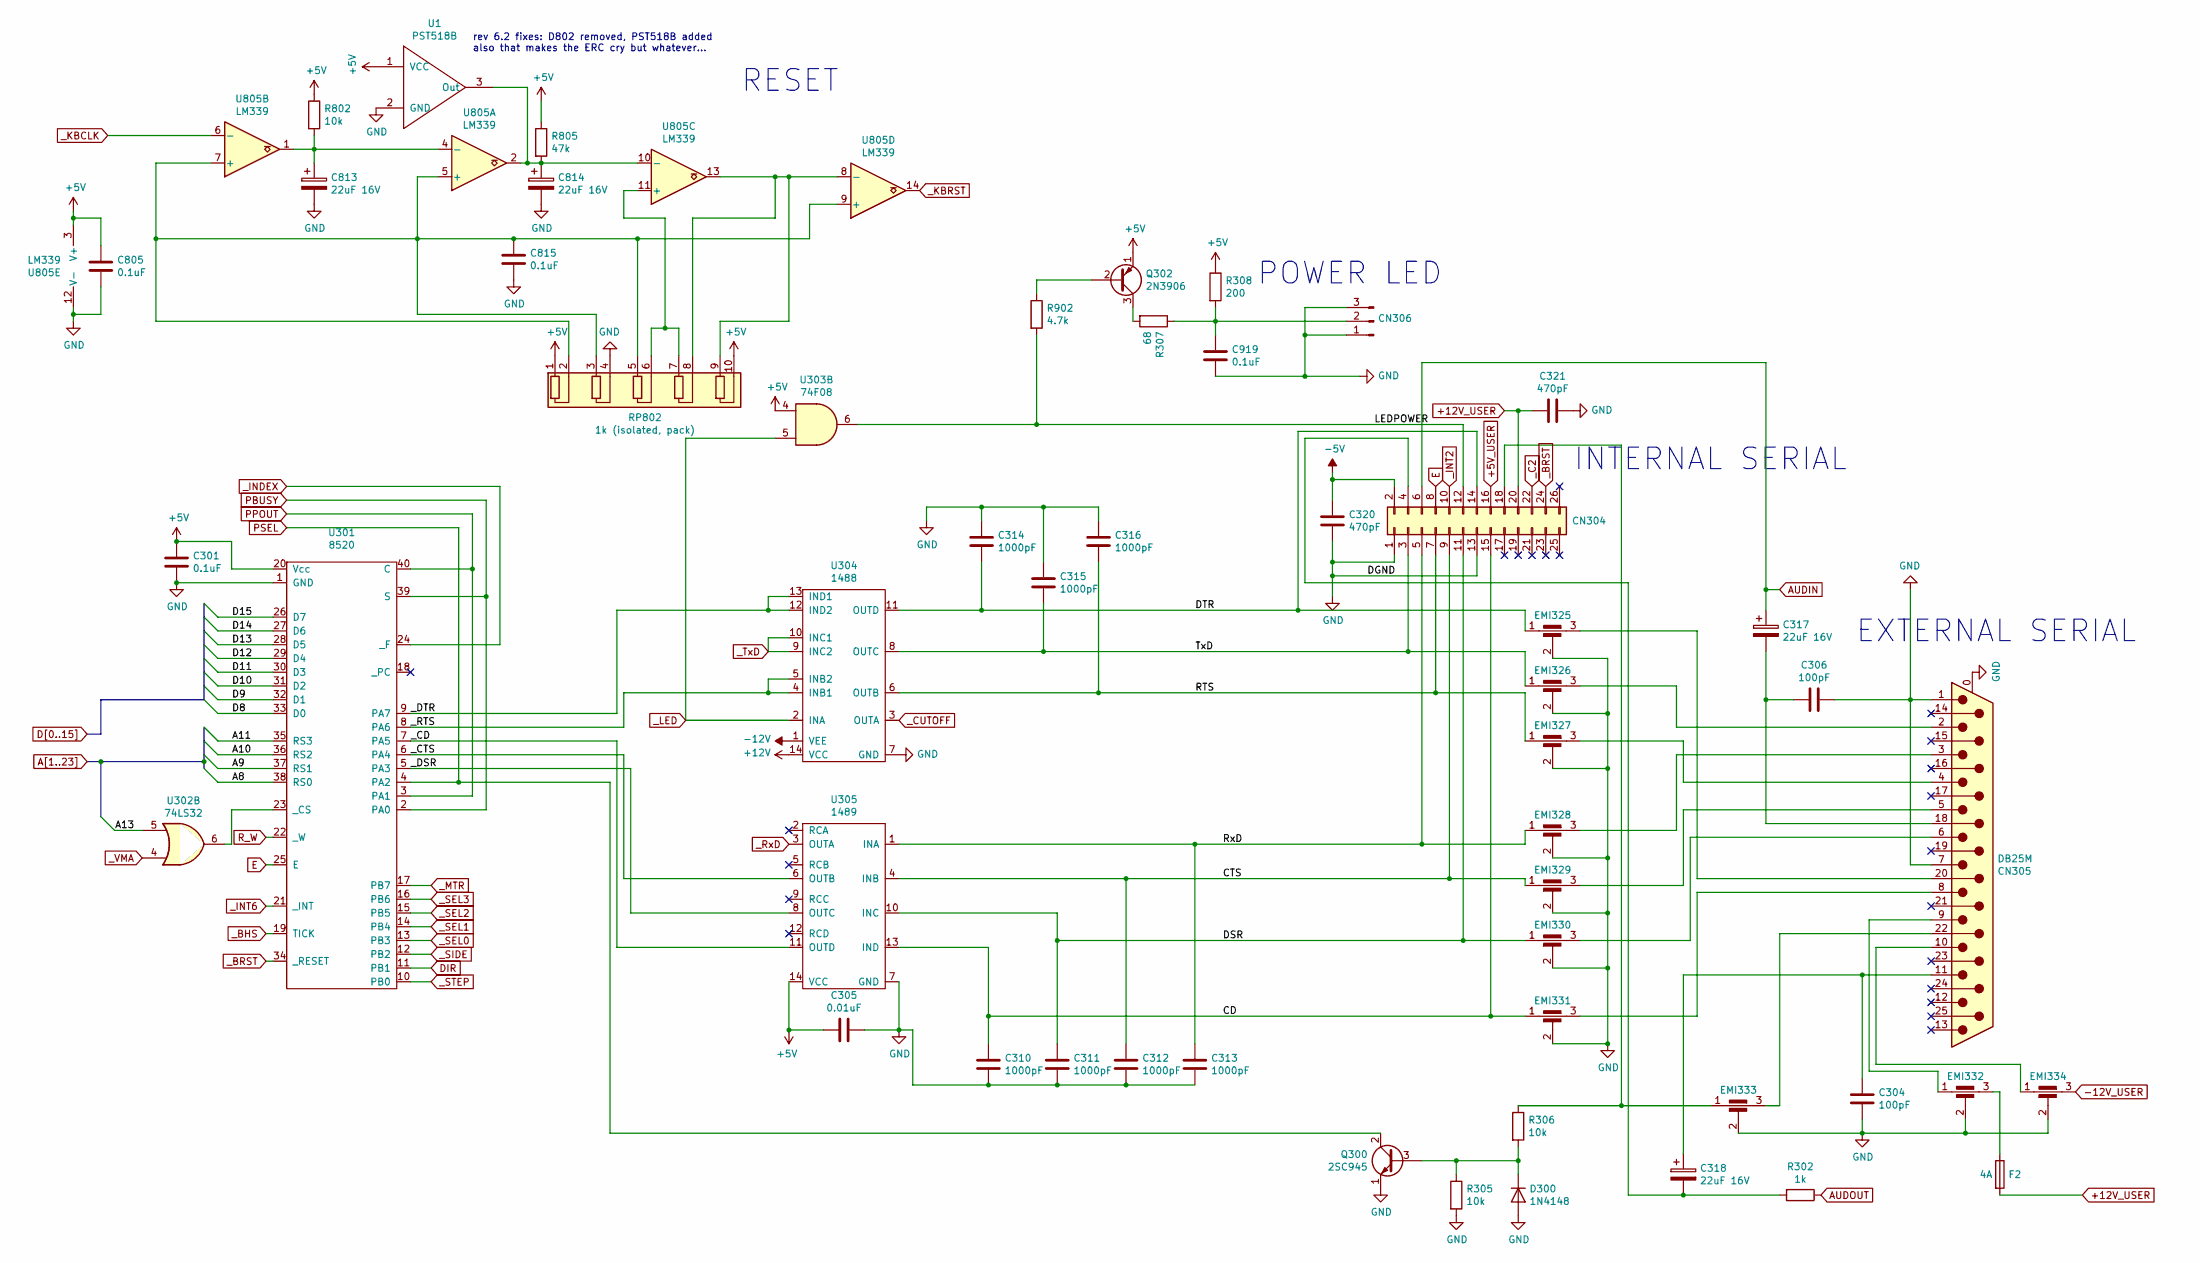
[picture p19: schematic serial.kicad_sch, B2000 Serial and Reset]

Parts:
C301, C805, C815, C919: 0.1uF; C_Rect_L11.5mm_W2.6mm_P10.00mm_MKT
C304, C306: 100pF; C_Rect_L11.5mm_W2.6mm_P10.00mm_MKT
C305: 0.01uF; C_Rect_L11.5mm_W2.6mm_P10.00mm_MKT
C310, C311, C312, C313, C314, C315, C316: 1000pF; C_Rect_L7.0mm_W2.0mm_P5.00mm
C317, C318, C813, C814: 22uF 16V; CP_Radial_Tantal_D5.0mm_P5.00mm
C320, C321: 470pF; C_Rect_L7.0mm_W2.0mm_P5.00mm
CN304: Conn_02x13_Odd_Even; PinHeader_2x13_P2.54mm_Vertical
CN305: DB25M; DSUB-25_Male_Horizontal_P2.77x2.84mm_EdgePinOffset7.70mm_Ho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
CN306: Conn_01x03_Male; PinHeader_1x03_P2.54mm_Vertical
D300: 1N4148; D_DO-35_SOD27_P7.62mm_Horizontal
EMI325, EMI326, EMI327, EMI328, EMI329, EMI330, EMI331, EMI332, EMI333, EMI334: 330pF (Type F 331); EMI_FILTER
F2: 4A; C_Rect_L11.5mm_W2.0mm_P10.00mm_MKT
Q300: 2SC945; TO-92_Inline
Q302: 2N3906; TO-92_Inline
R302: 1k; R_Axial_DIN0207_L6.3mm_D2.5mm_P10.16mm_Horizontal
R305, R306, R802: 10k; R_Axial_DIN0207_L6.3mm_D2.5mm_P10.16mm_Horizontal
R307: 68; R_Axial_DIN0207_L6.3mm_D2.5mm_P10.16mm_Horizontal
R308: 200; R_Axial_DIN0207_L6.3mm_D2.5mm_P10.16mm_Horizontal
R805: 47k; R_Axial_DIN0207_L6.3mm_D2.5mm_P10.16mm_Horizontal
R902: 4.7k; R_Axial_DIN0207_L6.3mm_D2.5mm_P10.16mm_Horizontal
RP802: 1k (isolated, pack); R_Array_SIP10
U1: PST518B; TO-92L_Inline
U301: 8520; DIP-40_W15.24mm_Socket
U302: 74LS32; DIP-14_W7.62mm_Socket
U303: 74F08; DIP-14_W7.62mm_Socket
U304: 1488; DIP-14_W7.62mm_Socket
U305: 1489; DIP-14_W7.62mm_Socket
U805: LM339; DIP-14_W7.62mm_Socket

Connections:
+5V_USER: CN304.16; also elsewhere on the board
+12V: U304.14 (VCC); also elsewhere on the board
+12V_USER: C321.2, CN304.20, F2.2; also elsewhere on the board
-5V: C320.1, CN304.2; also elsewhere on the board
-12V: U304.1 (VEE); also elsewhere on the board
-12V_USER: EMI334.3; also elsewhere on the board
/serial/CD: C310.1, CN304.15, EMI331.1, U305.13 (IND)
/serial/CTS: C312.1, CN304.9, EMI329.1, U305.4 (INB)
/serial/DSR: C311.1, CN304.11, EMI330.1, U305.10 (INC)
/serial/DTR: C314.2, CN304.14, EMI325.1, U304.11 (OUTD)
/serial/LEDPOWER: CN304.12, R902.2, U303.6
/serial/RTS: C316.2, CN304.7, EMI327.1, U304.6 (OUTB)
/serial/RxD: C313.1, CN304.5, EMI328.1, U305.1 (INA)
/serial/TxD: C315.2, CN304.3, EMI326.1, U304.8 (OUTC)
/serial/_CD: U301.7 (PA5), U305.11 (OUTD)
/serial/_CTS: U301.6 (PA4), U305.6 (OUTB)
/serial/_DSR: U301.5 (PA3), U305.8 (OUTC)
/serial/_DTR: U301.9 (PA7), U304.12 (IND2), U304.13 (IND1)
/serial/_RTS: U301.8 (PA6), U304.4 (INB1), U304.5 (INB2)
A8: U301.38 (RS0); also elsewhere on the board
A9: U301.37 (RS1); also elsewhere on the board
A10: U301.36 (RS2); also elsewhere on the board
A11: U301.35 (RS3); also elsewhere on the board
A13: U302.5; also elsewhere on the board
AUDIN: C317.1, CN304.6; also elsewhere on the board
AUDOUT: R302.1; also elsewhere on the board
D8: U301.33 (D0); also elsewhere on the board
D9: U301.32 (D1); also elsewhere on the board
D10: U301.31 (D2); also elsewhere on the board
D11: U301.30 (D3); also elsewhere on the board
D12: U301.29 (D4); also elsewhere on the board
D13: U301.28 (D5); also elsewhere on the board
D14: U301.27 (D6); also elsewhere on the board
D15: U301.26 (D7); also elsewhere on the board
DIR: U301.11 (PB1); also elsewhere on the board
E: CN304.8, U301.25 (E); also elsewhere on the board
GND: C301.2, C304.2, C305.1, C306.1, C310.2, C311.2, C312.2, C313.2, C314.1, C315.1, C316.1, C320.2, C321.1, C805.2, C813.2, C814.2, C815.2, C919.2, CN304.1, CN304.13, CN305.0 (PAD), CN305.1, CN305.7, CN306.1, CN306.3, D300.2 (A), EMI325.2, EMI326.2, EMI327.2, EMI328.2, EMI329.2, EMI330.2, EMI331.2, EMI332.2, EMI333.2, EMI334.2, Q300.1 (E), R305.2, RP802.4 (R2.2), U1.2 (GND), U301.1 (GND), U304.7 (GND), U305.7 (GND), U805.12 (V-); also elsewhere on the board
unnamed: C304.1, C318.1, CN305.11
unnamed: C306.2, C317.2, CN305.18
unnamed: C318.2, CN304.4, R302.2
unnamed: C813.1, R802.2, U805.1, U805.4 (-)
unnamed: C814.1, R805.2, U1.3 (Out), U805.2, U805.10 (-)
unnamed: C815.1, RP802.2 (R1.2), RP802.3 (R2.1), RP802.5 (R3.1), U805.5 (+), U805.7 (+), U805.9 (+)
unnamed: C919.1, CN306.2, R307.1, R308.2
unnamed: CN304.18, EMI333.1, R306.1
unnamed: CN305.2, EMI326.3
unnamed: CN305.3, EMI328.3
unnamed: CN305.4, EMI327.3
unnamed: CN305.5, EMI329.3
unnamed: CN305.6, EMI330.3
unnamed: CN305.8, EMI331.3
unnamed: CN305.9, EMI332.1
unnamed: CN305.10, EMI334.1
unnamed: CN305.20, EMI325.3
unnamed: CN305.22, EMI333.3
unnamed: D300.1 (K), Q300.3 (B), R305.1, R306.2
unnamed: EMI332.3, F2.1
unnamed: Q302.2 (B), R902.1
unnamed: Q302.3 (C), R307.2
unnamed: RP802.6 (R3.2), RP802.7 (R4.1), U805.11 (+)
unnamed: RP802.8 (R4.2), RP802.9 (R5.1), U805.8 (-), U805.13
unnamed: U301.23 (_CS), U302.6
PBUSY: U301.2 (PA0), U301.39 (S); also elsewhere on the board
PPOUT: U301.3 (PA1), U301.40 (C); also elsewhere on the board
PSEL: Q300.2 (C), U301.4 (PA2); also elsewhere on the board
R_W: U301.22 (_W); also elsewhere on the board
_BHS: U301.19 (TICK); also elsewhere on the board
_BRST: CN304.24, U301.34 (_RESET); also elsewhere on the board
_C2: CN304.22; also elsewhere on the board
_CUTOFF: U304.3 (OUTA); also elsewhere on the board
_INDEX: U301.24 (_F); also elsewhere on the board
_INT2: CN304.10; also elsewhere on the board
_INT6: U301.21 (_INT); also elsewhere on the board
_KBCLK: U805.6 (-); also elsewhere on the board
_KBRST: U805.14; also elsewhere on the board
_LED: U303.5, U304.2 (INA); also elsewhere on the board
_MTR: U301.17 (PB7); also elsewhere on the board
_RxD: U305.3 (OUTA); also elsewhere on the board
_SEL0: U301.13 (PB3); also elsewhere on the board
_SEL2: U301.15 (PB5); also elsewhere on the board
_SEL3: U301.16 (PB6); also elsewhere on the board
_SIDE: U301.12 (PB2); also elsewhere on the board
_STEP: U301.10 (PB0); also elsewhere on the board
_TxD: U304.9 (INC2), U304.10 (INC1); also elsewhere on the board
_VMA: U302.4; also elsewhere on the board

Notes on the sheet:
RESET
POWER LED
EXTERNAL SERIAL
INTERNAL SERIAL
rev 6.2 fixes: D802 removed, PST518B added also that makes the ERC cry but whatever...

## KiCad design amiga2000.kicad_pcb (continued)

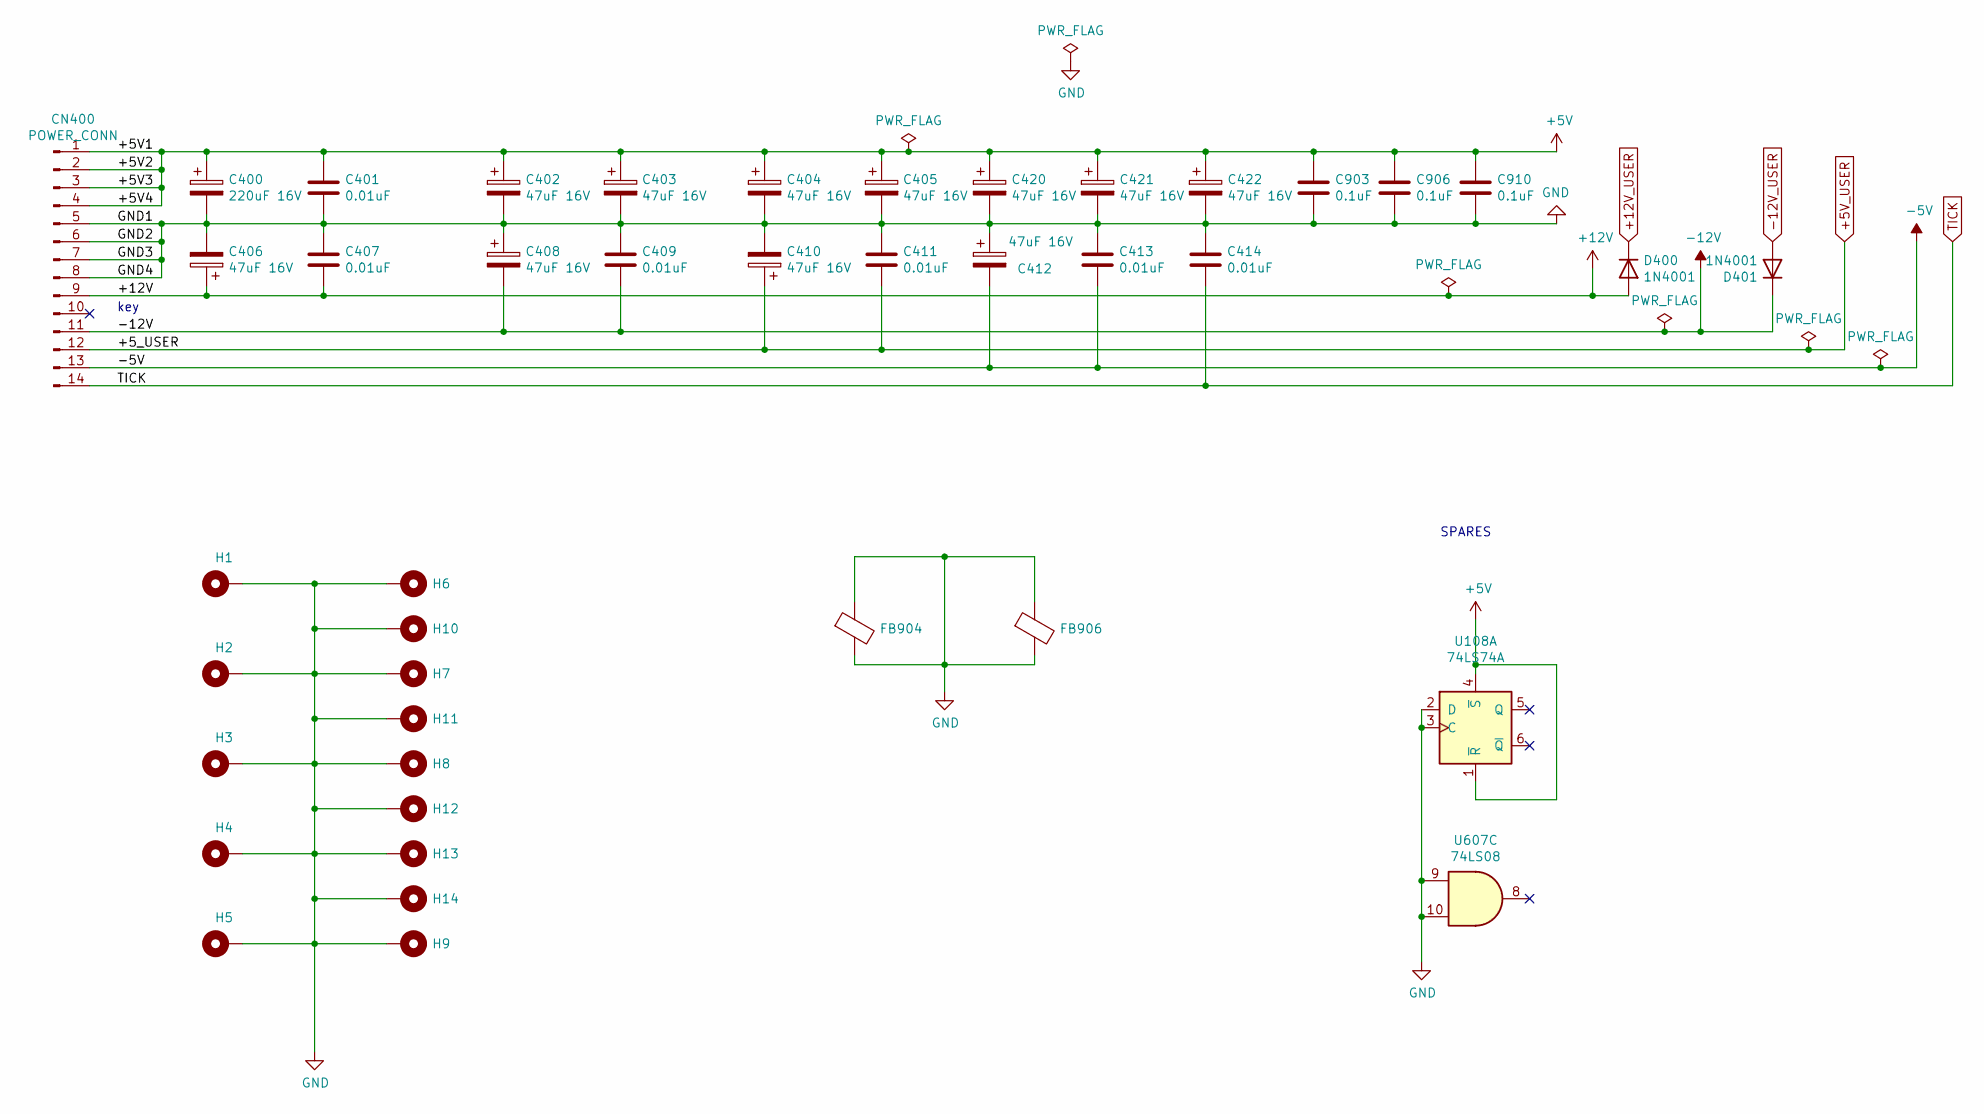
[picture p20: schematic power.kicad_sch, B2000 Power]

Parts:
C400: 220uF 16V; CP_Radial_Tantal_D6.0mm_P5.00mm
C401, C407, C409, C411, C413, C414: 0.01uF; C_Rect_L11.5mm_W2.6mm_P10.00mm_MKT
C402, C403, C404, C405, C406, C408, C410, C412, C420, C421, C422: 47uF 16V; CP_Radial_Tantal_D5.5mm_P5.00mm
C903, C906, C910: 0.1uF; C_Rect_L11.5mm_W2.6mm_P10.00mm_MKT
CN400: POWER_CONN; A2K_PWR
D400, D401: 1N4001; D_DO-41_SOD81_P10.16mm_Horizontal
FB904, FB906: Ferrite_Bead; L_Axial_L7.0mm_D3.3mm_P5.08mm_Vertical_Fastron_MICC
H1, H2, H3, H4, H5, H6, H7, H8, H9, H10, H11, H12, H13, H14: MountingHole_Pad; MountingHole_4mm_Pad_Via
U108: 74LS74A; DIP-14_W7.62mm_Socket
U607: 74LS08; DIP-14_W7.62mm_Socket

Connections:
+5V_USER: C410.1, C411.2, CN400.12; also elsewhere on the board
+12V: C406.1, C407.2, CN400.9, D400.2 (A); also elsewhere on the board
+12V_USER: D400.1 (K); also elsewhere on the board
-5V: C412.2, C413.2, CN400.13; also elsewhere on the board
-12V: C408.2, C409.2, CN400.11, D401.1 (K); also elsewhere on the board
-12V_USER: D401.2 (A); also elsewhere on the board
GND: C400.2, C401.2, C402.2, C403.2, C404.2, C405.2, C406.2, C407.1, C408.1, C409.1, C410.2, C411.1, C412.1, C413.1, C414.1, C420.2, C421.2, C422.2, C903.2, C906.2, C910.2, CN400.5, CN400.6, CN400.7, CN400.8, FB904.1, FB904.2, FB906.1, FB906.2, H1.1, H2.1, H3.1, H4.1, H5.1, H6.1, H7.1, H8.1, H9.1, H10.1, H11.1, H12.1, H13.1, H14.1, U108.2 (D), U108.3 (C), U607.9, U607.10; also elsewhere on the board
TICK: C414.2, CN400.14; also elsewhere on the board

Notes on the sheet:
key
SPARES

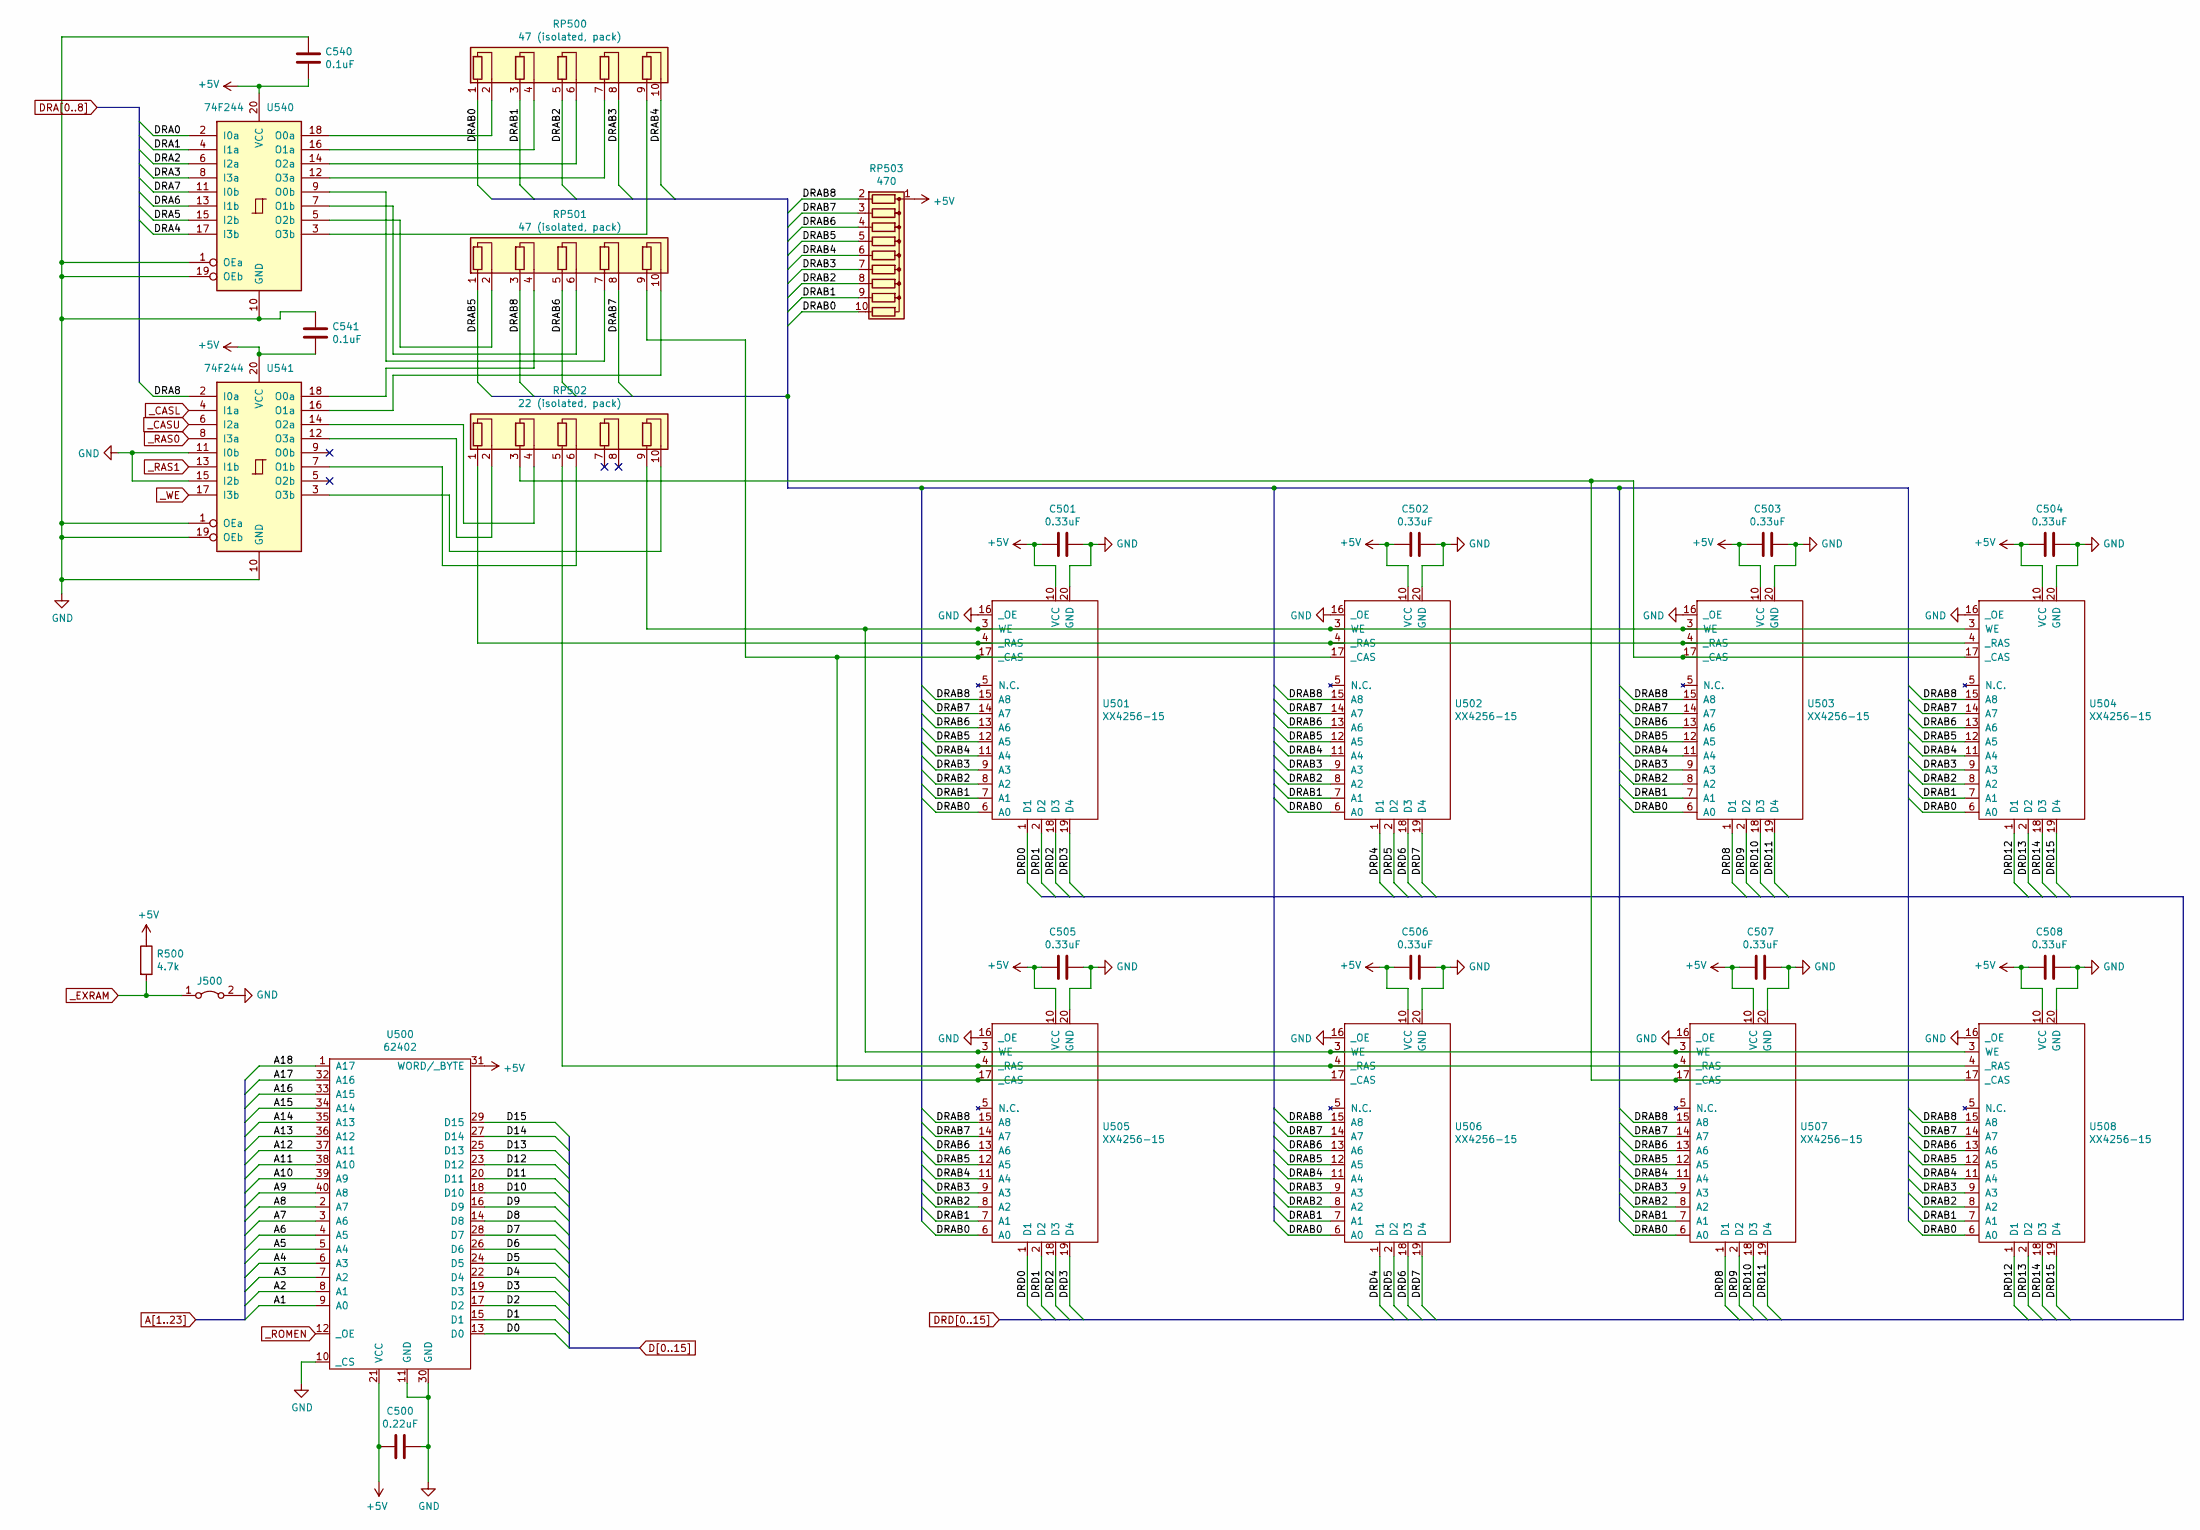
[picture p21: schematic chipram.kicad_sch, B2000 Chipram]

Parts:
C500: 0.22uF; C_Rect_L11.5mm_W2.6mm_P10.00mm_MKT
C501, C502, C503, C504, C505, C506, C507, C508: 0.33uF; C_Rect_L11.5mm_W4.0mm_P10.00mm_MKT
C540, C541: 0.1uF; C_Rect_L11.5mm_W2.6mm_P10.00mm_MKT
J500: Jumper_2_Bridged; PinHeader_2x01_P2.54mm_Vertical
R500: 4.7k; R_Axial_DIN0207_L6.3mm_D2.5mm_P10.16mm_Horizontal
RP500, RP501: 47 (isolated, pack); R_Array_SIP10
RP502: 22 (isolated, pack); R_Array_SIP10
RP503: 470; R_Array_SIP10
U500: 62402; DIP-40_W15.24mm_Socket
U501, U502, U503, U504, U505, U506, U507, U508: XX4256-15; DIP-20_W7.62mm_Socket
U540, U541: 74F244; DIP-20_W7.62mm_Socket

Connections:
/chipram/DRAB0: RP500.1 (R1.1), RP503.10 (R9), U501.6 (A0), U502.6 (A0), U503.6 (A0), U504.6 (A0), U505.6 (A0), U506.6 (A0), U507.6 (A0), U508.6 (A0)
/chipram/DRAB1: RP500.3 (R2.1), RP503.9 (R8), U501.7 (A1), U502.7 (A1), U503.7 (A1), U504.7 (A1), U505.7 (A1), U506.7 (A1), U507.7 (A1), U508.7 (A1)
/chipram/DRAB2: RP500.5 (R3.1), RP503.8 (R7), U501.8 (A2), U502.8 (A2), U503.8 (A2), U504.8 (A2), U505.8 (A2), U506.8 (A2), U507.8 (A2), U508.8 (A2)
/chipram/DRAB3: RP500.8 (R4.2), RP503.7 (R6), U501.9 (A3), U502.9 (A3), U503.9 (A3), U504.9 (A3), U505.9 (A3), U506.9 (A3), U507.9 (A3), U508.9 (A3)
/chipram/DRAB4: RP500.10 (R5.2), RP503.6 (R5), U501.11 (A4), U502.11 (A4), U503.11 (A4), U504.11 (A4), U505.11 (A4), U506.11 (A4), U507.11 (A4), U508.11 (A4)
/chipram/DRAB5: RP501.1 (R1.1), RP503.5 (R4), U501.12 (A5), U502.12 (A5), U503.12 (A5), U504.12 (A5), U505.12 (A5), U506.12 (A5), U507.12 (A5), U508.12 (A5)
/chipram/DRAB6: RP501.5 (R3.1), RP503.4 (R3), U501.13 (A6), U502.13 (A6), U503.13 (A6), U504.13 (A6), U505.13 (A6), U506.13 (A6), U507.13 (A6), U508.13 (A6)
/chipram/DRAB7: RP501.8 (R4.2), RP503.3 (R2), U501.14 (A7), U502.14 (A7), U503.14 (A7), U504.14 (A7), U505.14 (A7), U506.14 (A7), U507.14 (A7), U508.14 (A7)
/chipram/DRAB8: RP501.3 (R2.1), RP503.2 (R1), U501.15 (A8), U502.15 (A8), U503.15 (A8), U504.15 (A8), U505.15 (A8), U506.15 (A8), U507.15 (A8), U508.15 (A8)
A1: U500.9 (A0); also elsewhere on the board
A2: U500.8 (A1); also elsewhere on the board
A3: U500.7 (A2); also elsewhere on the board
A4: U500.6 (A3); also elsewhere on the board
A5: U500.5 (A4); also elsewhere on the board
A6: U500.4 (A5); also elsewhere on the board
A7: U500.3 (A6); also elsewhere on the board
A8: U500.2 (A7); also elsewhere on the board
A9: U500.40 (A8); also elsewhere on the board
A10: U500.39 (A9); also elsewhere on the board
A11: U500.38 (A10); also elsewhere on the board
A12: U500.37 (A11); also elsewhere on the board
A13: U500.36 (A12); also elsewhere on the board
A14: U500.35 (A13); also elsewhere on the board
A15: U500.34 (A14); also elsewhere on the board
A16: U500.33 (A15); also elsewhere on the board
A17: U500.32 (A16); also elsewhere on the board
A18: U500.1 (A17); also elsewhere on the board
D0: U500.13 (D0); also elsewhere on the board
D1: U500.15 (D1); also elsewhere on the board
D2: U500.17 (D2); also elsewhere on the board
D3: U500.19 (D3); also elsewhere on the board
D4: U500.22 (D4); also elsewhere on the board
D5: U500.24 (D5); also elsewhere on the board
D6: U500.26 (D6); also elsewhere on the board
D7: U500.28 (D7); also elsewhere on the board
D8: U500.14 (D8); also elsewhere on the board
D9: U500.16 (D9); also elsewhere on the board
D10: U500.18 (D10); also elsewhere on the board
D11: U500.20 (D11); also elsewhere on the board
D12: U500.23 (D12); also elsewhere on the board
D13: U500.25 (D13); also elsewhere on the board
D14: U500.27 (D14); also elsewhere on the board
D15: U500.29 (D15); also elsewhere on the board
DRA0: U540.2 (I0a); also elsewhere on the board
DRA1: U540.4 (I1a); also elsewhere on the board
DRA2: U540.6 (I2a); also elsewhere on the board
DRA3: U540.8 (I3a); also elsewhere on the board
DRA4: U540.17 (I3b); also elsewhere on the board
DRA5: U540.15 (I2b); also elsewhere on the board
DRA6: U540.13 (I1b); also elsewhere on the board
DRA7: U540.11 (I0b); also elsewhere on the board
DRA8: U541.2 (I0a); also elsewhere on the board
DRD0: U501.1 (D1), U505.1 (D1); also elsewhere on the board
DRD1: U501.2 (D2), U505.2 (D2); also elsewhere on the board
DRD2: U501.18 (D3), U505.18 (D3); also elsewhere on the board
DRD3: U501.19 (D4), U505.19 (D4); also elsewhere on the board
DRD4: U502.1 (D1), U506.1 (D1); also elsewhere on the board
DRD5: U502.2 (D2), U506.2 (D2); also elsewhere on the board
DRD6: U502.18 (D3), U506.18 (D3); also elsewhere on the board
DRD7: U502.19 (D4), U506.19 (D4); also elsewhere on the board
DRD8: U503.1 (D1), U507.1 (D1); also elsewhere on the board
DRD9: U503.2 (D2), U507.2 (D2); also elsewhere on the board
DRD10: U503.18 (D3), U507.18 (D3); also elsewhere on the board
DRD11: U503.19 (D4), U507.19 (D4); also elsewhere on the board
DRD12: U504.1 (D1), U508.1 (D1); also elsewhere on the board
DRD13: U504.2 (D2), U508.2 (D2); also elsewhere on the board
DRD14: U504.18 (D3), U508.18 (D3); also elsewhere on the board
DRD15: U504.19 (D4), U508.19 (D4); also elsewhere on the board
GND: C500.1, C501.1, C502.1, C503.1, C504.1, C505.1, C506.1, C507.1, C508.1, C540.1, C541.1, J500.2 (B), U500.10 (_CS), U500.11 (GND), U500.30 (GND), U501.16 (_OE), U501.20 (GND), U502.16 (_OE), U502.20 (GND), U503.16 (_OE), U503.20 (GND), U504.16 (_OE), U504.20 (GND), U505.16 (_OE), U505.20 (GND), U506.16 (_OE), U506.20 (GND), U507.16 (_OE), U507.20 (GND), U508.16 (_OE), U508.20 (GND), U540.1 (OEa), U540.10 (GND), U540.19 (OEb), U541.1 (OEa), U541.10 (GND), U541.11 (I0b), U541.15 (I2b), U541.19 (OEb); also elsewhere on the board
unnamed: RP500.2 (R1.2), U540.18 (O0a)
unnamed: RP500.4 (R2.2), U540.16 (O1a)
unnamed: RP500.6 (R3.2), U540.14 (O2a)
unnamed: RP500.7 (R4.1), U540.12 (O3a)
unnamed: RP500.9 (R5.1), U540.3 (O3b)
unnamed: RP501.2 (R1.2), U540.5 (O2b)
unnamed: RP501.4 (R2.2), U541.18 (O0a)
unnamed: RP501.6 (R3.2), U540.7 (O1b)
unnamed: RP501.7 (R4.1), U540.9 (O0b)
unnamed: RP501.9 (R5.1), U501.17 (_CAS), U502.17 (_CAS), U505.17 (_CAS), U506.17 (_CAS)
unnamed: RP501.10 (R5.2), U541.16 (O1a)
unnamed: RP502.1 (R1.1), U501.4 (_RAS), U502.4 (_RAS), U503.4 (_RAS), U504.4 (_RAS)
unnamed: RP502.2 (R1.2), U541.12 (O3a)
unnamed: RP502.3 (R2.1), U503.17 (_CAS), U504.17 (_CAS), U507.17 (_CAS), U508.17 (_CAS)
unnamed: RP502.4 (R2.2), U541.14 (O2a)
unnamed: RP502.5 (R3.1), U505.4 (_RAS), U506.4 (_RAS), U507.4 (_RAS), U508.4 (_RAS)
unnamed: RP502.6 (R3.2), U541.7 (O1b)
unnamed: RP502.9 (R5.1), U501.3 (WE), U502.3 (WE), U503.3 (WE), U504.3 (WE), U505.3 (WE), U506.3 (WE), U507.3 (WE), U508.3 (WE)
unnamed: RP502.10 (R5.2), U541.3 (O3b)
_CASL: U541.4 (I1a); also elsewhere on the board
_CASU: U541.6 (I2a); also elsewhere on the board
_EXRAM: J500.1 (A), R500.2; also elsewhere on the board
_RAS0: U541.8 (I3a); also elsewhere on the board
_RAS1: U541.13 (I1b); also elsewhere on the board
_ROMEN: U500.12 (_OE); also elsewhere on the board
_WE: U541.17 (I3b); also elsewhere on the board

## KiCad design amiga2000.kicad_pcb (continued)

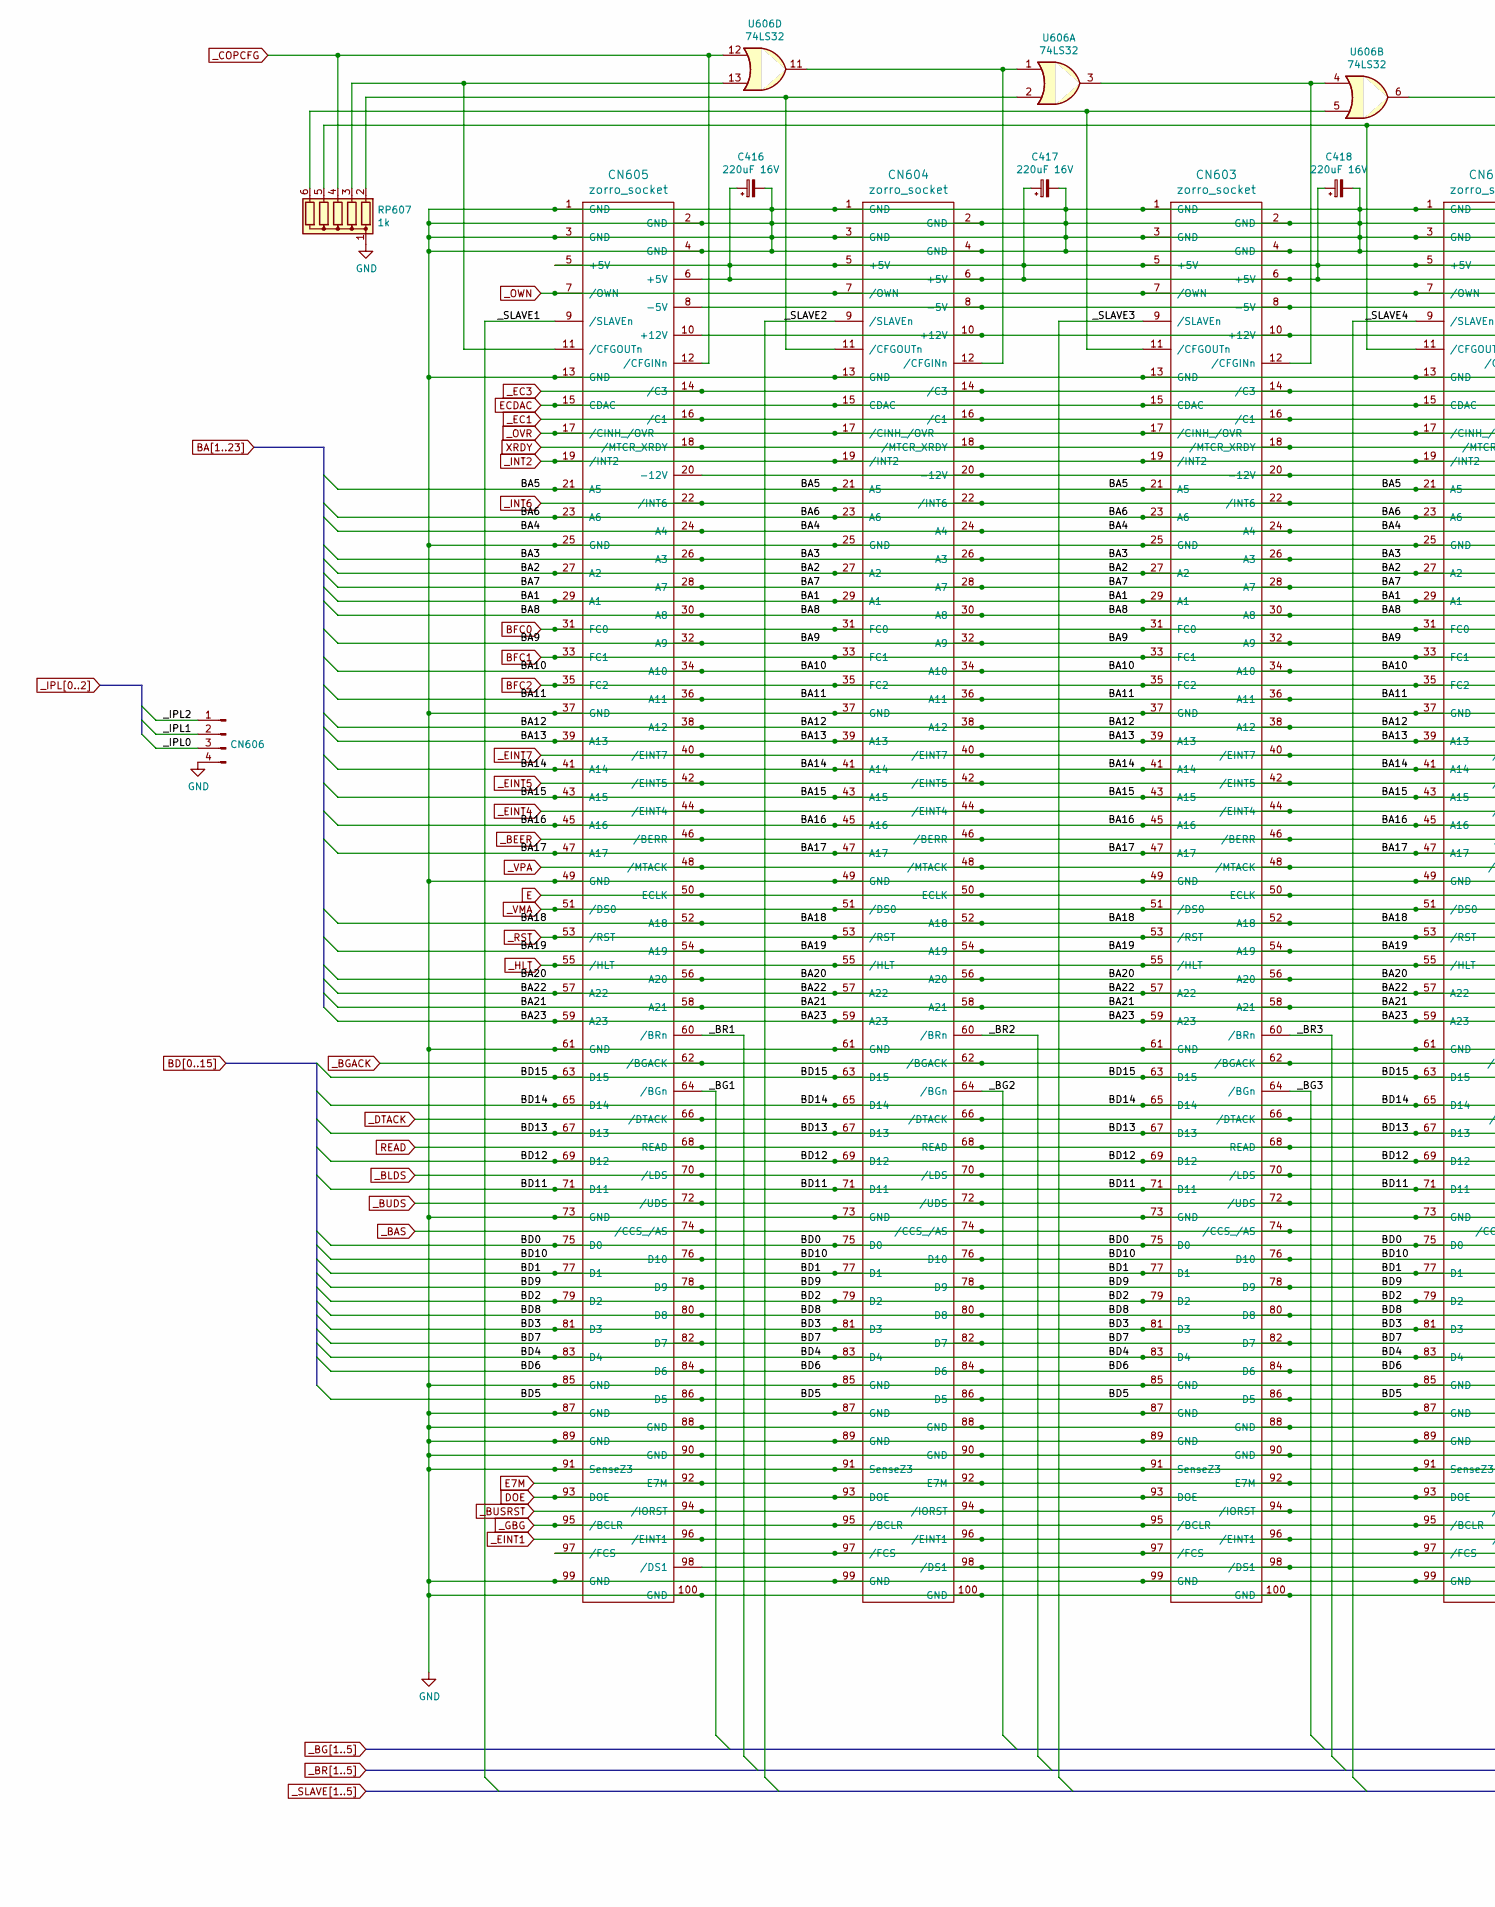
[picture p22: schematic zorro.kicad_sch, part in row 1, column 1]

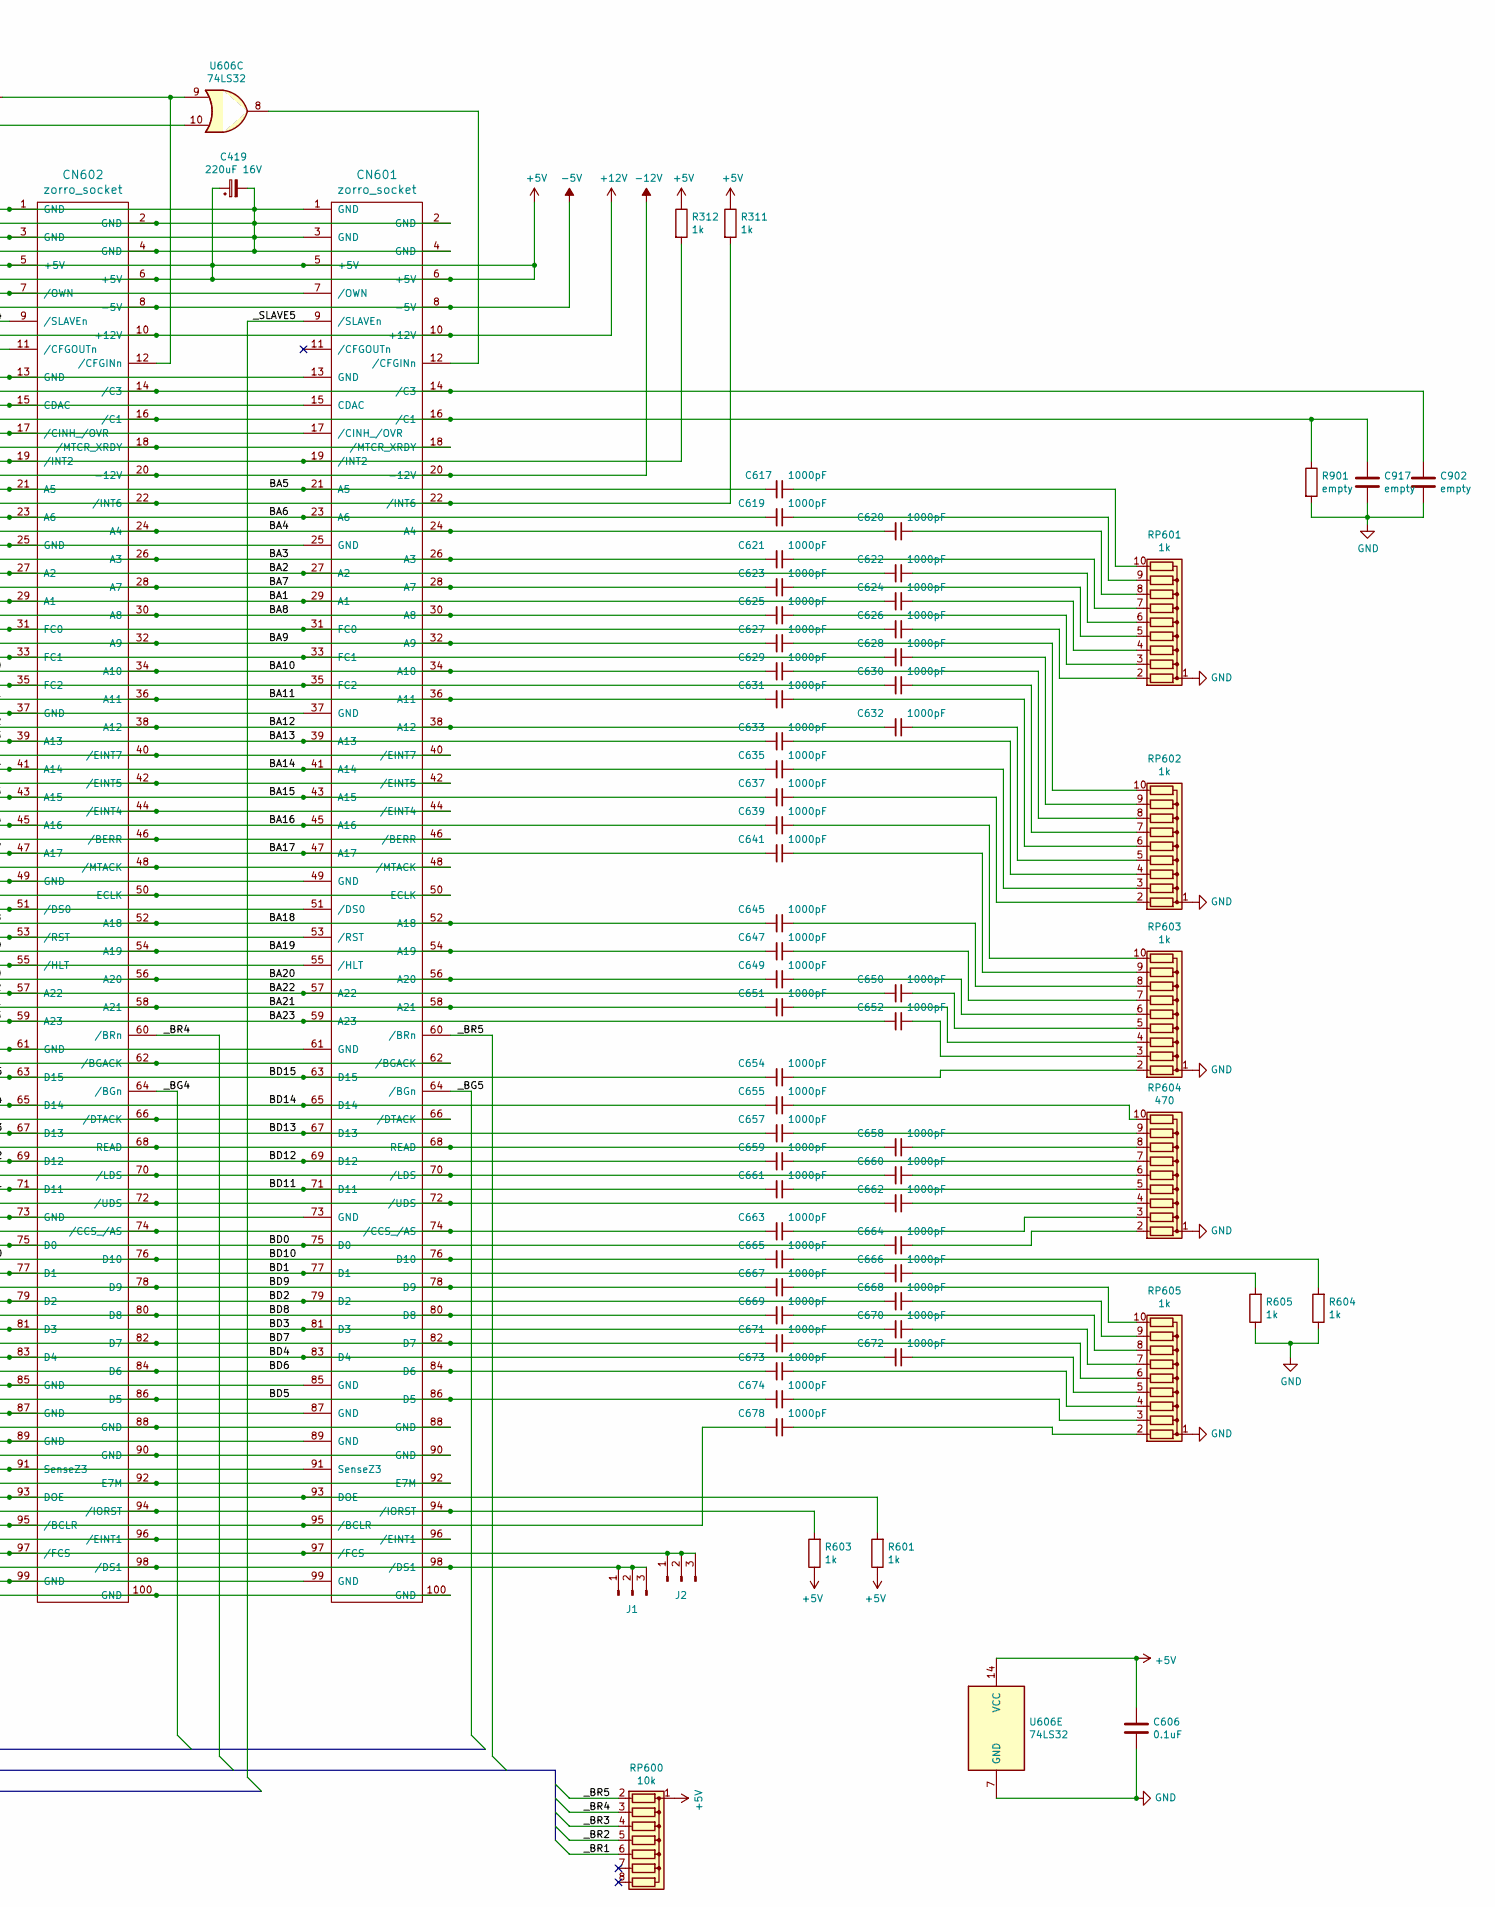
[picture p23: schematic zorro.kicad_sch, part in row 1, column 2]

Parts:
C416, C417, C418, C419: 220uF 16V; C_Axial_L19.0mm_D8.0mm_P25.00mm_Horizontal
C606: 0.1uF; C_Rect_L11.5mm_W2.6mm_P10.00mm_MKT
C617, C619, C620, C621, C622, C623, C624, C625, C626, C627, C628, C629, C630, C631, C632, C633, C635, C637, C639, C641, C645, C647, C649, C650, C651, C652, C654, C655, C657, C658, C659, C660, C661, C662, C663, C664, C665, C666, C667, C668, C669, C670, C671, C672, C673, C674, C678: 1000pF; C_Rect_L11.5mm_W2.0mm_P10.00mm_MKT
C902, C917: empty; C_Rect_L11.5mm_W2.0mm_P10.00mm_MKT
CN601, CN602, CN603, CN604, CN605: zorro_socket; Zorro
CN606: Conn_01x04_Male; PinHeader_1x04_P2.54mm_Vertical
J1, J2: Conn_01x03_Male; PinHeader_1x03_P2.54mm_Vertical
R311, R312, R601, R603, R604, R605: 1k; R_Axial_DIN0207_L6.3mm_D2.5mm_P10.16mm_Horizontal
R901: empty; R_Axial_DIN0207_L6.3mm_D2.5mm_P10.16mm_Horizontal
RP600: 10k; R_Array_SIP8
RP601, RP602, RP603, RP605: 1k; R_Array_SIP10
RP604: 470; R_Array_SIP10
RP607: 1k; R_Array_SIP6
U606: 74LS32; DIP-14_W7.62mm_Socket

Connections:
+12V: CN601.10 (+12V), CN602.10 (+12V), CN603.10 (+12V), CN604.10 (+12V), CN605.10 (+12V); also elsewhere on the board
-5V: CN601.8 (-5V), CN602.8 (-5V), CN603.8 (-5V), CN604.8 (-5V), CN605.8 (-5V); also elsewhere on the board
-12V: CN601.20 (-12V), CN602.20 (-12V), CN603.20 (-12V), CN604.20 (-12V), CN605.20 (-12V); also elsewhere on the board
BA1: C624.2, CN601.29 (A1), CN602.29 (A1), CN603.29 (A1), CN604.29 (A1), CN605.29 (A1); also elsewhere on the board
BA2: C622.2, CN601.27 (A2), CN602.27 (A2), CN603.27 (A2), CN604.27 (A2), CN605.27 (A2); also elsewhere on the board
BA3: C621.2, CN601.26 (A3), CN602.26 (A3), CN603.26 (A3), CN604.26 (A3), CN605.26 (A3); also elsewhere on the board
BA4: C620.2, CN601.24 (A4), CN602.24 (A4), CN603.24 (A4), CN604.24 (A4), CN605.24 (A4); also elsewhere on the board
BA5: C617.2, CN601.21 (A5), CN602.21 (A5), CN603.21 (A5), CN604.21 (A5), CN605.21 (A5); also elsewhere on the board
BA6: C619.2, CN601.23 (A6), CN602.23 (A6), CN603.23 (A6), CN604.23 (A6), CN605.23 (A6); also elsewhere on the board
BA7: C623.2, CN601.28 (A7), CN602.28 (A7), CN603.28 (A7), CN604.28 (A7), CN605.28 (A7); also elsewhere on the board
BA8: C625.2, CN601.30 (A8), CN602.30 (A8), CN603.30 (A8), CN604.30 (A8), CN605.30 (A8); also elsewhere on the board
BA9: C627.2, CN601.32 (A9), CN602.32 (A9), CN603.32 (A9), CN604.32 (A9), CN605.32 (A9); also elsewhere on the board
BA10: C629.2, CN601.34 (A10), CN602.34 (A10), CN603.34 (A10), CN604.34 (A10), CN605.34 (A10); also elsewhere on the board
BA11: C631.2, CN601.36 (A11), CN602.36 (A11), CN603.36 (A11), CN604.36 (A11), CN605.36 (A11); also elsewhere on the board
BA12: C632.2, CN601.38 (A12), CN602.38 (A12), CN603.38 (A12), CN604.38 (A12), CN605.38 (A12); also elsewhere on the board
BA13: C633.2, CN601.39 (A13), CN602.39 (A13), CN603.39 (A13), CN604.39 (A13), CN605.39 (A13); also elsewhere on the board
BA14: C635.2, CN601.41 (A14), CN602.41 (A14), CN603.41 (A14), CN604.41 (A14), CN605.41 (A14); also elsewhere on the board
BA15: C637.2, CN601.43 (A15), CN602.43 (A15), CN603.43 (A15), CN604.43 (A15), CN605.43 (A15); also elsewhere on the board
BA16: C639.2, CN601.45 (A16), CN602.45 (A16), CN603.45 (A16), CN604.45 (A16), CN605.45 (A16); also elsewhere on the board
BA17: C641.2, CN601.47 (A17), CN602.47 (A17), CN603.47 (A17), CN604.47 (A17), CN605.47 (A17); also elsewhere on the board
BA18: C645.2, CN601.52 (A18), CN602.52 (A18), CN603.52 (A18), CN604.52 (A18), CN605.52 (A18); also elsewhere on the board
BA19: C647.2, CN601.54 (A19), CN602.54 (A19), CN603.54 (A19), CN604.54 (A19), CN605.54 (A19); also elsewhere on the board
BA20: C649.2, CN601.56 (A20), CN602.56 (A20), CN603.56 (A20), CN604.56 (A20), CN605.56 (A20); also elsewhere on the board
BA21: C651.2, CN601.58 (A21), CN602.58 (A21), CN603.58 (A21), CN604.58 (A21), CN605.58 (A21); also elsewhere on the board
BA22: C650.2, CN601.57 (A22), CN602.57 (A22), CN603.57 (A22), CN604.57 (A22), CN605.57 (A22); also elsewhere on the board
BA23: C652.2, CN601.59 (A23), CN602.59 (A23), CN603.59 (A23), CN604.59 (A23), CN605.59 (A23); also elsewhere on the board
BD0: C664.2, CN601.75 (D0), CN602.75 (D0), CN603.75 (D0), CN604.75 (D0), CN605.75 (D0); also elsewhere on the board
BD1: C666.2, CN601.77 (D1), CN602.77 (D1), CN603.77 (D1), CN604.77 (D1), CN605.77 (D1); also elsewhere on the board
BD2: C668.2, CN601.79 (D2), CN602.79 (D2), CN603.79 (D2), CN604.79 (D2), CN605.79 (D2); also elsewhere on the board
BD3: C670.2, CN601.81 (D3), CN602.81 (D3), CN603.81 (D3), CN604.81 (D3), CN605.81 (D3); also elsewhere on the board
BD4: C672.2, CN601.83 (D4), CN602.83 (D4), CN603.83 (D4), CN604.83 (D4), CN605.83 (D4); also elsewhere on the board
BD5: C674.2, CN601.86 (D5), CN602.86 (D5), CN603.86 (D5), CN604.86 (D5), CN605.86 (D5); also elsewhere on the board
BD6: C673.2, CN601.84 (D6), CN602.84 (D6), CN603.84 (D6), CN604.84 (D6), CN605.84 (D6); also elsewhere on the board
BD7: C671.2, CN601.82 (D7), CN602.82 (D7), CN603.82 (D7), CN604.82 (D7), CN605.82 (D7); also elsewhere on the board
BD8: C669.2, CN601.80 (D8), CN602.80 (D8), CN603.80 (D8), CN604.80 (D8), CN605.80 (D8); also elsewhere on the board
BD9: C667.2, CN601.78 (D9), CN602.78 (D9), CN603.78 (D9), CN604.78 (D9), CN605.78 (D9); also elsewhere on the board
BD10: C665.2, CN601.76 (D10), CN602.76 (D10), CN603.76 (D10), CN604.76 (D10), CN605.76 (D10); also elsewhere on the board
BD11: C661.2, CN601.71 (D11), CN602.71 (D11), CN603.71 (D11), CN604.71 (D11), CN605.71 (D11); also elsewhere on the board
BD12: C659.2, CN601.69 (D12), CN602.69 (D12), CN603.69 (D12), CN604.69 (D12), CN605.69 (D12); also elsewhere on the board
BD13: C657.2, CN601.67 (D13), CN602.67 (D13), CN603.67 (D13), CN604.67 (D13), CN605.67 (D13); also elsewhere on the board
BD14: C655.2, CN601.65 (D14), CN602.65 (D14), CN603.65 (D14), CN604.65 (D14), CN605.65 (D14); also elsewhere on the board
BD15: C654.2, CN601.63 (D15), CN602.63 (D15), CN603.63 (D15), CN604.63 (D15), CN605.63 (D15); also elsewhere on the board
BFC0: C626.2, CN601.31 (FC0), CN602.31 (FC0), CN603.31 (FC0), CN604.31 (FC0), CN605.31 (FC0); also elsewhere on the board
BFC1: C628.2, CN601.33 (FC1), CN602.33 (FC1), CN603.33 (FC1), CN604.33 (FC1), CN605.33 (FC1); also elsewhere on the board
BFC2: C630.2, CN601.35 (FC2), CN602.35 (FC2), CN603.35 (FC2), CN604.35 (FC2), CN605.35 (FC2); also elsewhere on the board
DOE: CN601.93 (DOE), CN602.93 (DOE), CN603.93 (DOE), CN604.93 (DOE), CN605.93 (DOE), R601.2; also elsewhere on the board
E: CN601.50 (ECLK), CN602.50 (ECLK), CN603.50 (ECLK), CN604.50 (ECLK), CN605.50 (ECLK); also elsewhere on the board
E7M: CN601.92 (E7M), CN602.92 (E7M), CN603.92 (E7M), CN604.92 (E7M), CN605.92 (E7M); also elsewhere on the board
ECDAC: CN601.15 (CDAC), CN602.15 (CDAC), CN603.15 (CDAC), CN604.15 (CDAC), CN605.15 (CDAC); also elsewhere on the board
GND: C416.2, C417.2, C418.2, C419.2, C606.2, C902.2, C917.2, CN601.1 (GND), CN601.2 (GND), CN601.3 (GND), CN601.4 (GND), CN601.13 (GND), CN601.25 (GND), CN601.37 (GND), CN601.49 (GND), CN601.61 (GND), CN601.73 (GND), CN601.85 (GND), CN601.87 (GND), CN601.88 (GND), CN601.89 (GND), CN601.90 (GND), CN601.91 (SenseZ3), CN601.99 (GND), CN601.100 (GND), CN602.1 (GND), CN602.2 (GND), CN602.3 (GND), CN602.4 (GND), CN602.13 (GND), CN602.25 (GND), CN602.37 (GND), CN602.49 (GND), CN602.61 (GND), CN602.73 (GND), CN602.85 (GND), CN602.87 (GND), CN602.88 (GND), CN602.89 (GND), CN602.90 (GND), CN602.91 (SenseZ3), CN602.99 (GND), CN602.100 (GND), CN603.1 (GND), CN603.2 (GND), CN603.3 (GND), CN603.4 (GND), CN603.13 (GND), CN603.25 (GND), CN603.37 (GND), CN603.49 (GND), CN603.61 (GND), CN603.73 (GND), CN603.85 (GND), CN603.87 (GND), CN603.88 (GND), CN603.89 (GND), CN603.90 (GND), CN603.91 (SenseZ3), CN603.99 (GND), CN603.100 (GND), CN604.1 (GND), CN604.2 (GND), CN604.3 (GND), CN604.4 (GND), CN604.13 (GND), CN604.25 (GND), CN604.37 (GND), CN604.49 (GND), CN604.61 (GND), CN604.73 (GND), CN604.85 (GND), CN604.87 (GND), CN604.88 (GND), CN604.89 (GND), CN604.90 (GND), CN604.91 (SenseZ3), CN604.99 (GND), CN604.100 (GND), CN605.1 (GND), CN605.2 (GND), CN605.3 (GND), CN605.4 (GND), CN605.13 (GND), CN605.25 (GND), CN605.37 (GND), CN605.49 (GND), CN605.61 (GND), CN605.73 (GND), CN605.85 (GND), CN605.87 (GND), CN605.88 (GND), CN605.89 (GND), CN605.90 (GND), CN605.91 (SenseZ3), CN605.99 (GND), CN605.100 (GND), CN606.4, R604.1, R605.1, R901.2, RP601.1 (common), RP602.1 (common), RP603.1 (common), RP604.1 (common), RP605.1 (common), RP607.1 (common), U606.7 (GND); also elsewhere on the board
unnamed: C617.1, RP601.10 (R9)
unnamed: C619.1, RP601.9 (R8)
unnamed: C620.1, RP601.8 (R7)
unnamed: C621.1, RP601.7 (R6)
unnamed: C622.1, RP601.6 (R5)
unnamed: C623.1, RP601.5 (R4)
unnamed: C624.1, RP601.4 (R3)
unnamed: C625.1, RP601.3 (R2)
unnamed: C626.1, RP601.2 (R1)
unnamed: C627.1, RP602.10 (R9)
unnamed: C628.1, RP602.9 (R8)
unnamed: C629.1, RP602.8 (R7)
unnamed: C630.1, RP602.7 (R6)
unnamed: C631.1, RP602.6 (R5)
unnamed: C632.1, RP602.5 (R4)
unnamed: C633.1, RP602.4 (R3)
unnamed: C635.1, RP602.3 (R2)
unnamed: C637.1, RP602.2 (R1)
unnamed: C639.1, RP603.10 (R9)
unnamed: C641.1, RP603.9 (R8)
unnamed: C645.1, RP603.8 (R7)
unnamed: C647.1, RP603.7 (R6)
unnamed: C649.1, RP603.6 (R5)
unnamed: C650.1, RP603.5 (R4)
unnamed: C651.1, RP603.4 (R3)
unnamed: C652.1, RP603.3 (R2)
unnamed: C654.1, RP603.2 (R1)
unnamed: C655.1, RP604.10 (R9)
unnamed: C657.1, RP604.9 (R8)
unnamed: C658.1, RP604.8 (R7)
unnamed: C659.1, RP604.7 (R6)
unnamed: C660.1, RP604.6 (R5)
unnamed: C661.1, RP604.5 (R4)
unnamed: C662.1, RP604.4 (R3)
unnamed: C663.1, RP604.3 (R2)
unnamed: C664.1, RP604.2 (R1)
unnamed: C665.1, R604.2
unnamed: C666.1, R605.2
unnamed: C667.1, RP605.10 (R9)
unnamed: C668.1, RP605.9 (R8)
unnamed: C669.1, RP605.8 (R7)
unnamed: C670.1, RP605.7 (R6)
unnamed: C671.1, RP605.6 (R5)
unnamed: C672.1, RP605.5 (R4)
unnamed: C673.1, RP605.4 (R3)
unnamed: C674.1, RP605.3 (R2)
unnamed: C678.1, RP605.2 (R1)
unnamed: CN601.12 (/CFGINn), U606.8
unnamed: CN601.97 (/FCS), CN602.97 (/FCS), CN603.97 (/FCS), CN604.97 (/FCS), CN605.97 (/FCS), J2.1, J2.2, J2.3
unnamed: CN601.98 (/DS1), CN602.98 (/DS1), CN603.98 (/DS1), CN604.98 (/DS1), CN605.98 (/DS1), J1.1, J1.2, J1.3
unnamed: CN602.11 (/CFGOUTn), RP607.5 (R4), U606.10
unnamed: CN602.12 (/CFGINn), U606.6, U606.9
unnamed: CN603.11 (/CFGOUTn), RP607.6 (R5), U606.5
unnamed: CN603.12 (/CFGINn), U606.3, U606.4
unnamed: CN604.11 (/CFGOUTn), RP607.2 (R1), U606.2
unnamed: CN604.12 (/CFGINn), U606.1, U606.11
unnamed: CN605.11 (/CFGOUTn), RP607.3 (R2), U606.13
READ: C658.2, CN601.68 (READ), CN602.68 (READ), CN603.68 (READ), CN604.68 (READ), CN605.68 (READ); also elsewhere on the board
XRDY: CN601.18 (/MTCR_XRDY), CN602.18 (/MTCR_XRDY), CN603.18 (/MTCR_XRDY), CN604.18 (/MTCR_XRDY), CN605.18 (/MTCR_XRDY); also elsewhere on the board
_BAS: C663.2, CN601.74 (/CCS_/AS), CN602.74 (/CCS_/AS), CN603.74 (/CCS_/AS), CN604.74 (/CCS_/AS), CN605.74 (/CCS_/AS); also elsewhere on the board
_BEER: CN601.46 (/BERR), CN602.46 (/BERR), CN603.46 (/BERR), CN604.46 (/BERR), CN605.46 (/BERR); also elsewhere on the board
_BG1: CN605.64 (/BGn); also elsewhere on the board
_BG2: CN604.64 (/BGn); also elsewhere on the board
_BG3: CN603.64 (/BGn); also elsewhere on the board
_BG4: CN602.64 (/BGn); also elsewhere on the board
_BG5: CN601.64 (/BGn); also elsewhere on the board
_BGACK: CN601.62 (/BGACK), CN602.62 (/BGACK), CN603.62 (/BGACK), CN604.62 (/BGACK), CN605.62 (/BGACK); also elsewhere on the board
_BLDS: C660.2, CN601.70 (/LDS), CN602.70 (/LDS), CN603.70 (/LDS), CN604.70 (/LDS), CN605.70 (/LDS); also elsewhere on the board
_BR1: CN605.60 (/BRn), RP600.6 (R5); also elsewhere on the board
_BR2: CN604.60 (/BRn), RP600.5 (R4); also elsewhere on the board
_BR3: CN603.60 (/BRn), RP600.4 (R3); also elsewhere on the board
_BR4: CN602.60 (/BRn), RP600.3 (R2); also elsewhere on the board
_BR5: CN601.60 (/BRn), RP600.2 (R1); also elsewhere on the board
_BUDS: C662.2, CN601.72 (/UDS), CN602.72 (/UDS), CN603.72 (/UDS), CN604.72 (/UDS), CN605.72 (/UDS); also elsewhere on the board
_BUSRST: CN601.94 (/IORST), CN602.94 (/IORST), CN603.94 (/IORST), CN604.94 (/IORST), CN605.94 (/IORST), R603.2; also elsewhere on the board
_COPCFG: CN605.12 (/CFGINn), RP607.4 (R3), U606.12; also elsewhere on the board
_DTACK: CN601.66 (/DTACK), CN602.66 (/DTACK), CN603.66 (/DTACK), CN604.66 (/DTACK), CN605.66 (/DTACK); also elsewhere on the board
_EC1: C917.1, CN601.16 (/C1), CN602.16 (/C1), CN603.16 (/C1), CN604.16 (/C1), CN605.16 (/C1), R901.1; also elsewhere on the board
_EC3: C902.1, CN601.14 (/C3), CN602.14 (/C3), CN603.14 (/C3), CN604.14 (/C3), CN605.14 (/C3); also elsewhere on the board
_EINT1: CN601.96 (/EINT1), CN602.96 (/EINT1), CN603.96 (/EINT1), CN604.96 (/EINT1), CN605.96 (/EINT1); also elsewhere on the board
_EINT4: CN601.44 (/EINT4), CN602.44 (/EINT4), CN603.44 (/EINT4), CN604.44 (/EINT4), CN605.44 (/EINT4); also elsewhere on the board
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

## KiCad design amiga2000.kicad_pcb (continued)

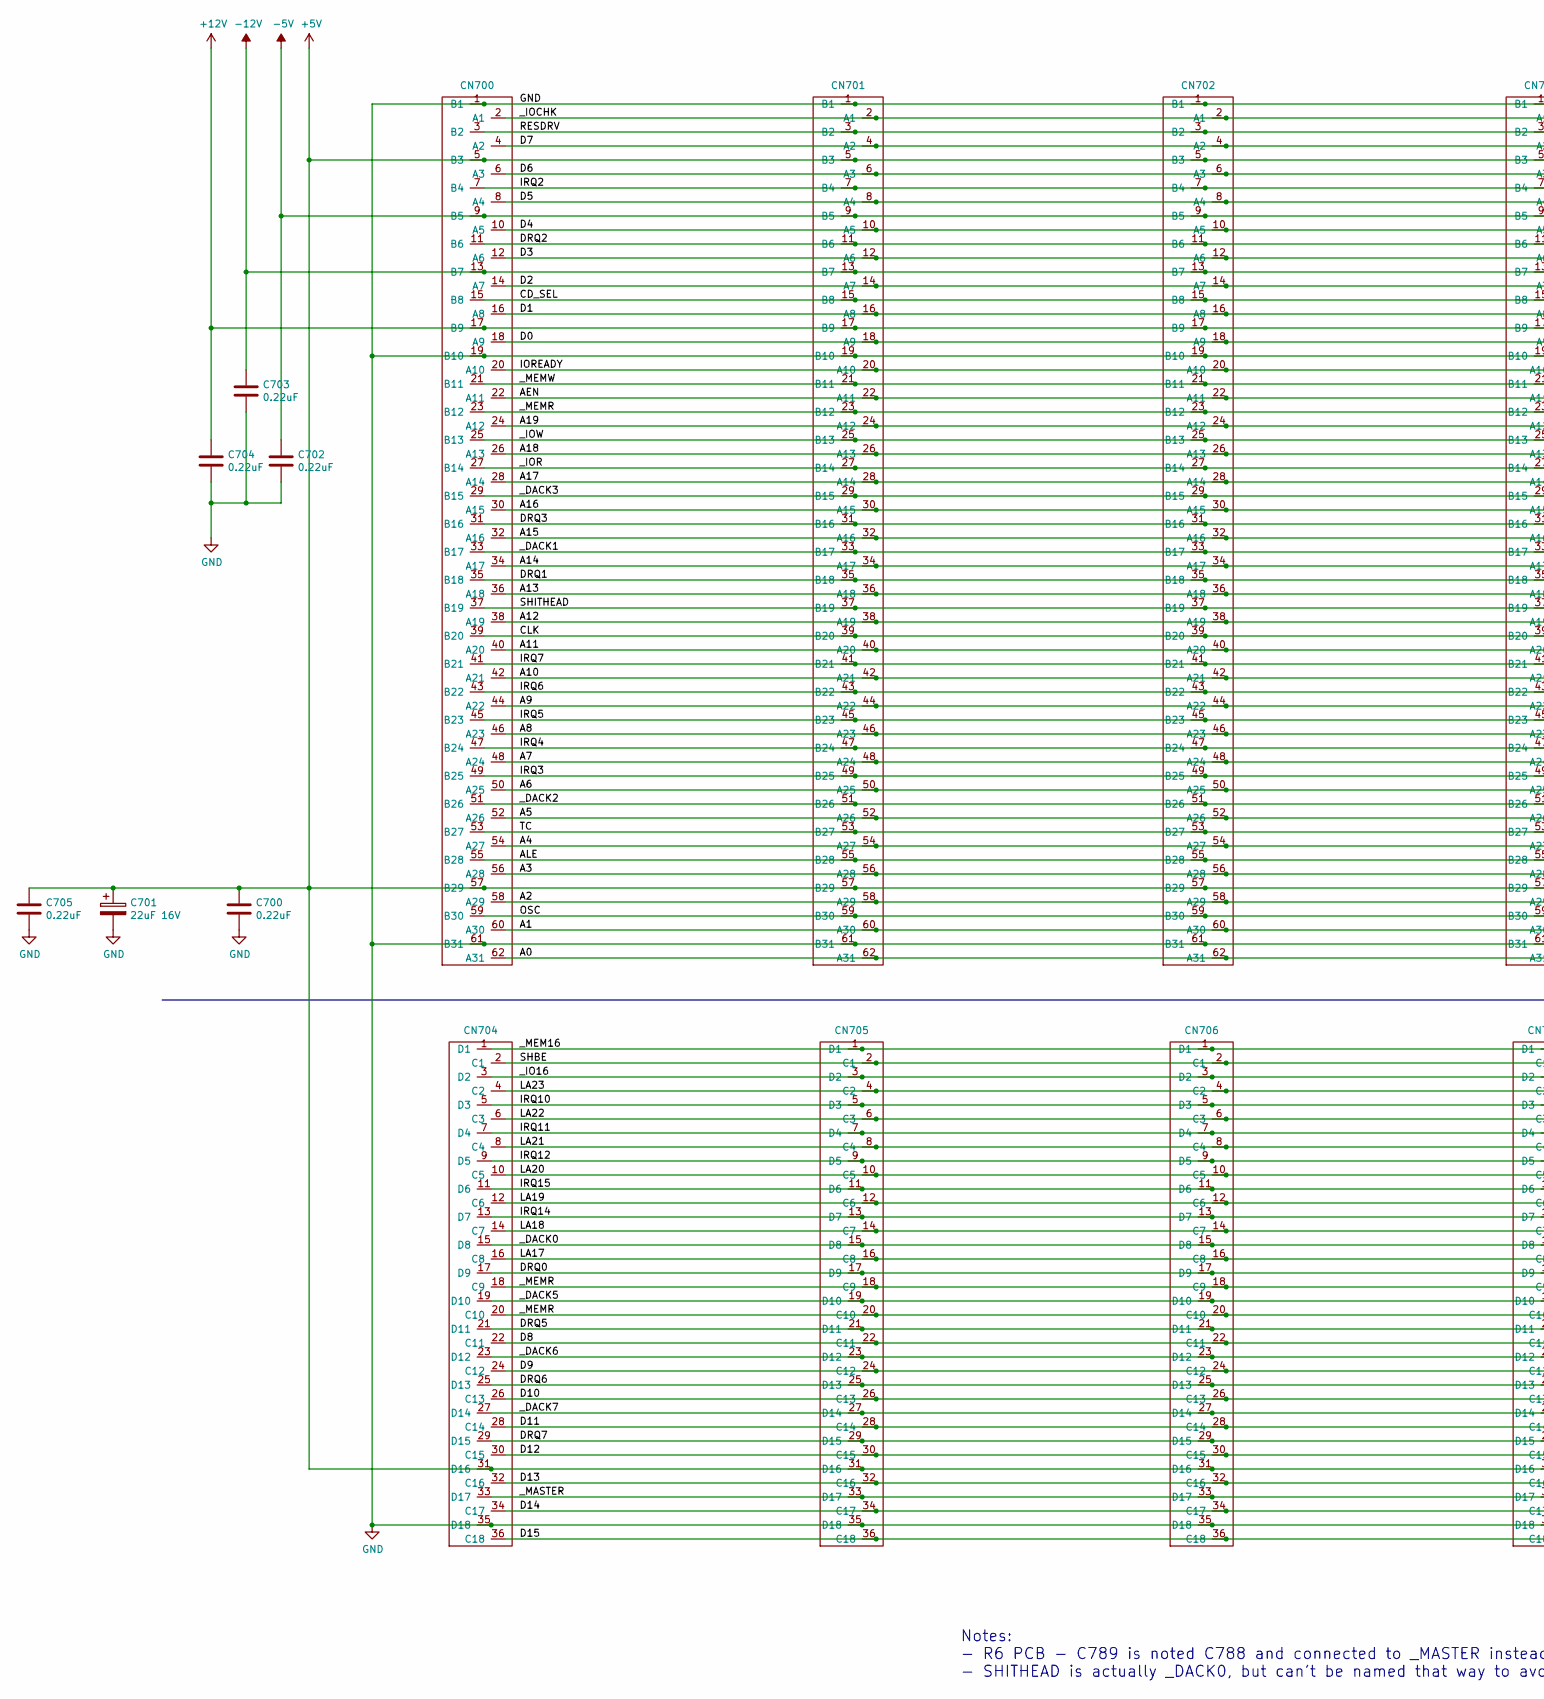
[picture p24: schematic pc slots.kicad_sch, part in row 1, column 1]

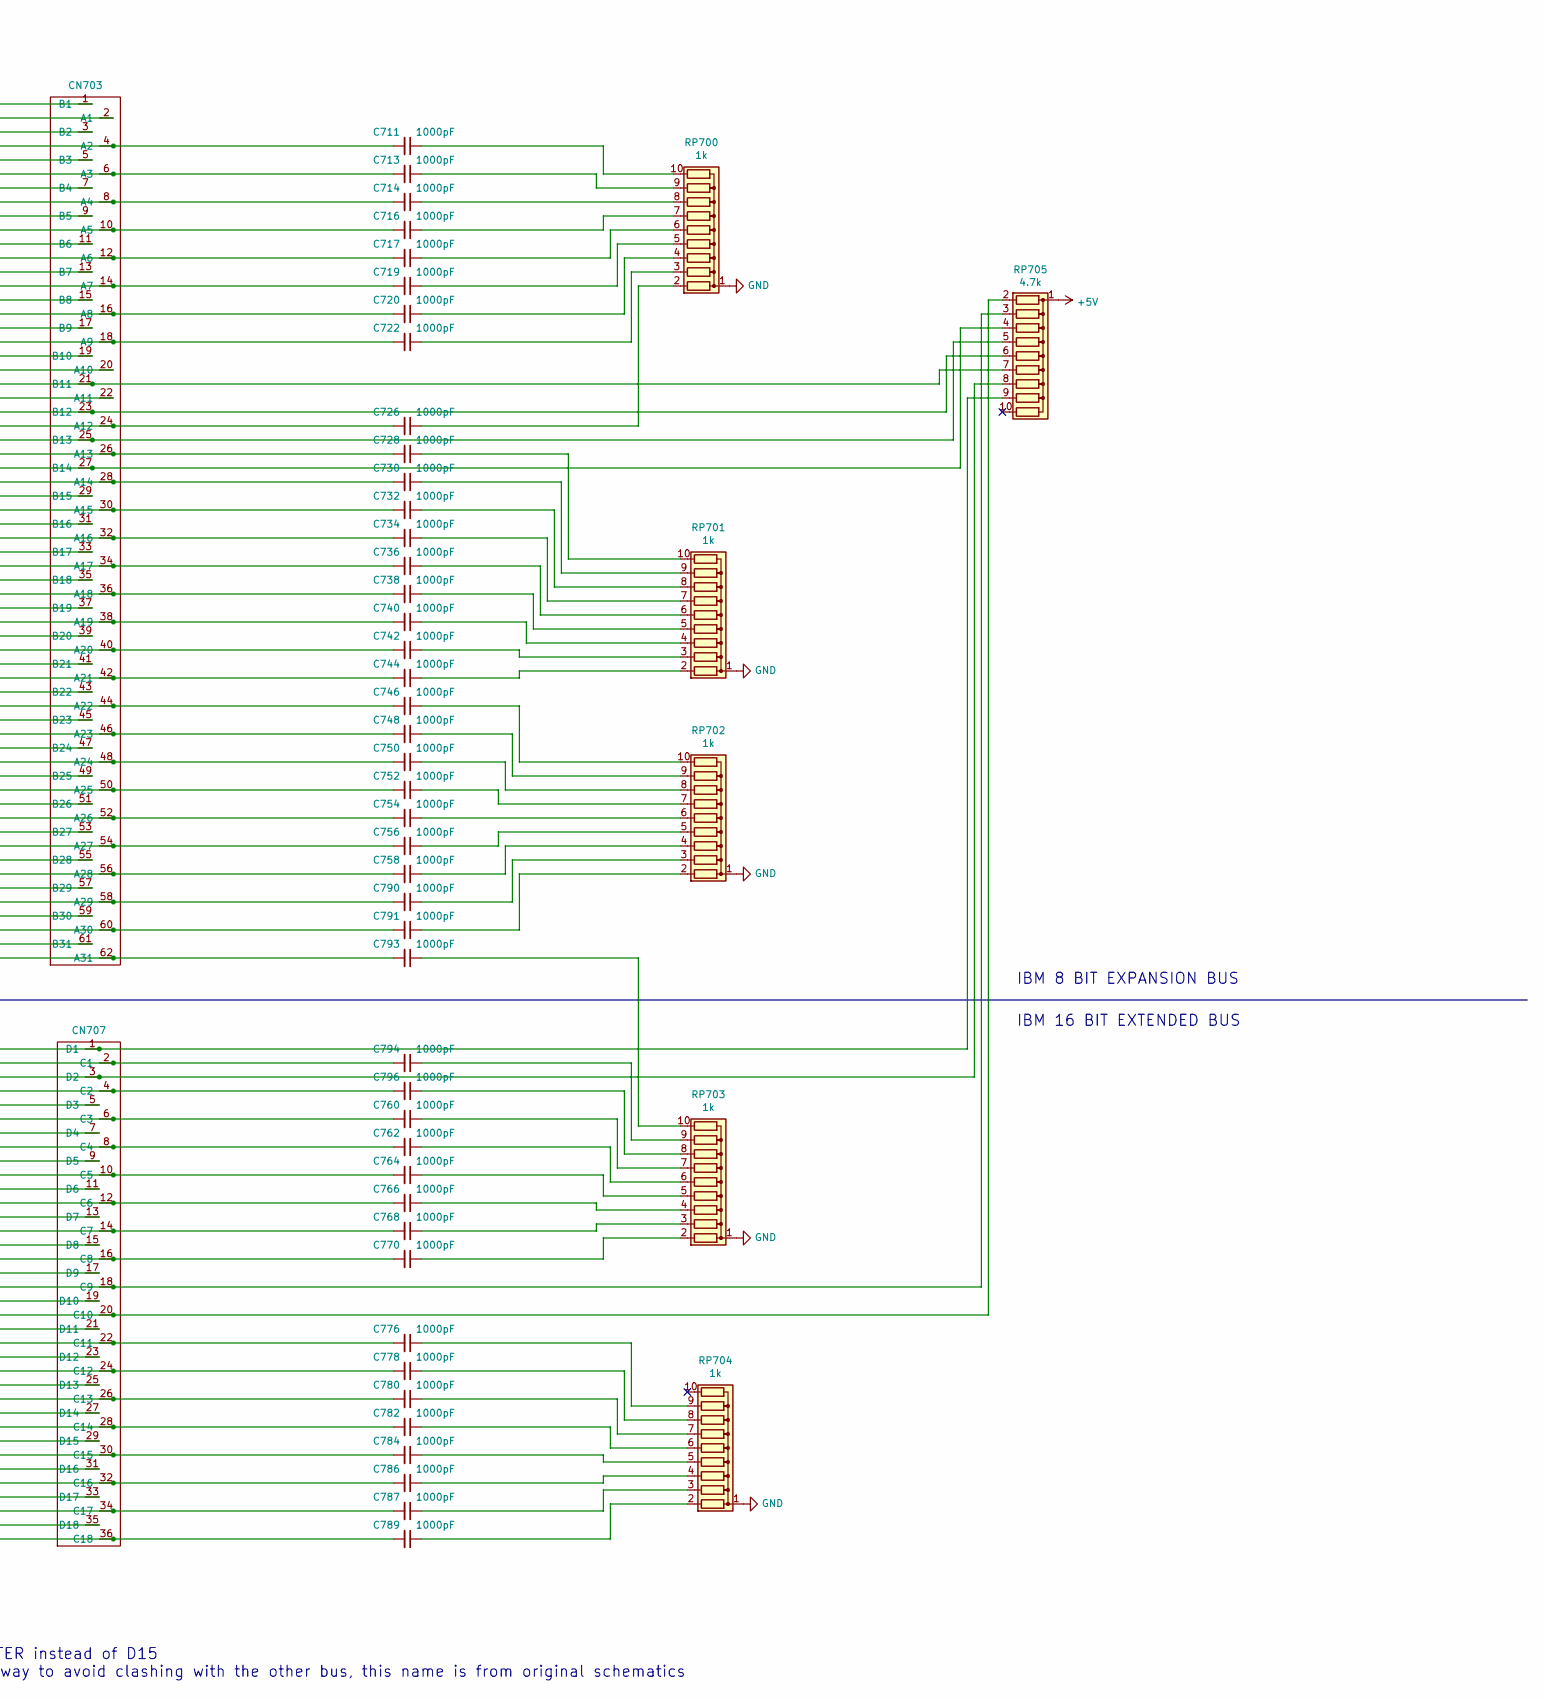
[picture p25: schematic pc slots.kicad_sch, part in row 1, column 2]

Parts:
C700, C702, C703, C704, C705: 0.22uF; C_Rect_L11.5mm_W2.6mm_P10.00mm_MKT
C701: 22uF 16V; CP_Radial_Tantal_D5.0mm_P5.00mm
C711, C713, C714, C716, C717, C719, C720, C722, C726, C728, C730, C732, C734, C736, C738, C740, C742, C744, C746, C748, C750, C752, C754, C756, C758, C760, C762, C764, C766, C768, C770, C776, C778, C780, C782, C784, C786, C787, C789, C790, C791, C793, C794, C796: 1000pF; C_Rect_L11.5mm_W2.0mm_P10.00mm_MKT
CN700, CN701, CN702, CN703: IBM_8_BIT_EXPANSION_BUS; ISA8
CN704, CN705, CN706, CN707: IBM_16_BIT_EXTENDED_BUS; ISA16
RP700, RP701, RP702, RP703, RP704: 1k; R_Array_SIP10
RP705: 4.7k; R_Array_SIP10

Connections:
+12V: C704.1, CN700.17 (B9), CN701.17 (B9), CN702.17 (B9), CN703.17 (B9); also elsewhere on the board
-5V: C702.1, CN700.9 (B5), CN701.9 (B5), CN702.9 (B5), CN703.9 (B5); also elsewhere on the board
-12V: C703.1, CN700.13 (B7), CN701.13 (B7), CN702.13 (B7), CN703.13 (B7); also elsewhere on the board
/pc slots/A0: C793.2, CN700.62 (A31), CN701.62 (A31), CN702.62 (A31), CN703.62 (A31)
/pc slots/A1: C791.2, CN700.60 (A30), CN701.60 (A30), CN702.60 (A30), CN703.60 (A30)
/pc slots/A2: C790.2, CN700.58 (A29), CN701.58 (A29), CN702.58 (A29), CN703.58 (A29)
/pc slots/A3: C758.2, CN700.56 (A28), CN701.56 (A28), CN702.56 (A28), CN703.56 (A28)
/pc slots/A4: C756.2, CN700.54 (A27), CN701.54 (A27), CN702.54 (A27), CN703.54 (A27)
/pc slots/A5: C754.2, CN700.52 (A26), CN701.52 (A26), CN702.52 (A26), CN703.52 (A26)
/pc slots/A6: C752.2, CN700.50 (A25), CN701.50 (A25), CN702.50 (A25), CN703.50 (A25)
/pc slots/A7: C750.2, CN700.48 (A24), CN701.48 (A24), CN702.48 (A24), CN703.48 (A24)
/pc slots/A8: C748.2, CN700.46 (A23), CN701.46 (A23), CN702.46 (A23), CN703.46 (A23)
/pc slots/A9: C746.2, CN700.44 (A22), CN701.44 (A22), CN702.44 (A22), CN703.44 (A22)
/pc slots/A10: C744.2, CN700.42 (A21), CN701.42 (A21), CN702.42 (A21), CN703.42 (A21)
/pc slots/A11: C742.2, CN700.40 (A20), CN701.40 (A20), CN702.40 (A20), CN703.40 (A20)
/pc slots/A12: C740.2, CN700.38 (A19), CN701.38 (A19), CN702.38 (A19), CN703.38 (A19)
/pc slots/A13: C738.2, CN700.36 (A18), CN701.36 (A18), CN702.36 (A18), CN703.36 (A18)
/pc slots/A14: C736.2, CN700.34 (A17), CN701.34 (A17), CN702.34 (A17), CN703.34 (A17)
/pc slots/A15: C734.2, CN700.32 (A16), CN701.32 (A16), CN702.32 (A16), CN703.32 (A16)
/pc slots/A16: C732.2, CN700.30 (A15), CN701.30 (A15), CN702.30 (A15), CN703.30 (A15)
/pc slots/A17: C730.2, CN700.28 (A14), CN701.28 (A14), CN702.28 (A14), CN703.28 (A14)
/pc slots/A18: C728.2, CN700.26 (A13), CN701.26 (A13), CN702.26 (A13), CN703.26 (A13)
/pc slots/A19: C726.2, CN700.24 (A12), CN701.24 (A12), CN702.24 (A12), CN703.24 (A12)
/pc slots/AEN: CN700.22 (A11), CN701.22 (A11), CN702.22 (A11), CN703.22 (A11)
/pc slots/ALE: CN700.55 (B28), CN701.55 (B28), CN702.55 (B28), CN703.55 (B28)
/pc slots/CD_SEL: CN700.15 (B8), CN701.15 (B8), CN702.15 (B8), CN703.15 (B8)
/pc slots/CLK: CN700.39 (B20), CN701.39 (B20), CN702.39 (B20), CN703.39 (B20)
/pc slots/D0: C722.2, CN700.18 (A9), CN701.18 (A9), CN702.18 (A9), CN703.18 (A9)
/pc slots/D1: C720.2, CN700.16 (A8), CN701.16 (A8), CN702.16 (A8), CN703.16 (A8)
/pc slots/D2: C719.2, CN700.14 (A7), CN701.14 (A7), CN702.14 (A7), CN703.14 (A7)
/pc slots/D3: C717.2, CN700.12 (A6), CN701.12 (A6), CN702.12 (A6), CN703.12 (A6)
/pc slots/D4: C716.2, CN700.10 (A5), CN701.10 (A5), CN702.10 (A5), CN703.10 (A5)
/pc slots/D5: C714.2, CN700.8 (A4), CN701.8 (A4), CN702.8 (A4), CN703.8 (A4)
/pc slots/D6: C713.2, CN700.6 (A3), CN701.6 (A3), CN702.6 (A3), CN703.6 (A3)
/pc slots/D7: C711.2, CN700.4 (A2), CN701.4 (A2), CN702.4 (A2), CN703.4 (A2)
/pc slots/D8: C776.2, CN704.22 (C11), CN705.22 (C11), CN706.22 (C11), CN707.22 (C11)
/pc slots/D9: C778.2, CN704.24 (C12), CN705.24 (C12), CN706.24 (C12), CN707.24 (C12)
/pc slots/D10: C780.2, CN704.26 (C13), CN705.26 (C13), CN706.26 (C13), CN707.26 (C13)
/pc slots/D11: C782.2, CN704.28 (C14), CN705.28 (C14), CN706.28 (C14), CN707.28 (C14)
/pc slots/D12: C784.2, CN704.30 (C15), CN705.30 (C15), CN706.30 (C15), CN707.30 (C15)
/pc slots/D13: C786.2, CN704.32 (C16), CN705.32 (C16), CN706.32 (C16), CN707.32 (C16)
/pc slots/D14: C787.2, CN704.34 (C17), CN705.34 (C17), CN706.34 (C17), CN707.34 (C17)
/pc slots/D15: C789.2, CN704.36 (C18), CN705.36 (C18), CN706.36 (C18), CN707.36 (C18)
/pc slots/DRQ0: CN704.17 (D9), CN705.17 (D9), CN706.17 (D9), CN707.17 (D9)
/pc slots/DRQ1: CN700.35 (B18), CN701.35 (B18), CN702.35 (B18), CN703.35 (B18)
/pc slots/DRQ2: CN700.11 (B6), CN701.11 (B6), CN702.11 (B6), CN703.11 (B6)
/pc slots/DRQ3: CN700.31 (B16), CN701.31 (B16), CN702.31 (B16), CN703.31 (B16)
/pc slots/DRQ5: CN704.21 (D11), CN705.21 (D11), CN706.21 (D11), CN707.21 (D11)
/pc slots/DRQ6: CN704.25 (D13), CN705.25 (D13), CN706.25 (D13), CN707.25 (D13)
/pc slots/DRQ7: CN704.29 (D15), CN705.29 (D15), CN706.29 (D15), CN707.29 (D15)
/pc slots/IOREADY: CN700.20 (A10), CN701.20 (A10), CN702.20 (A10), CN703.20 (A10)
/pc slots/IRQ2: CN700.7 (B4), CN701.7 (B4), CN702.7 (B4), CN703.7 (B4)
/pc slots/IRQ3: CN700.49 (B25), CN701.49 (B25), CN702.49 (B25), CN703.49 (B25)
/pc slots/IRQ4: CN700.47 (B24), CN701.47 (B24), CN702.47 (B24), CN703.47 (B24)
/pc slots/IRQ5: CN700.45 (B23), CN701.45 (B23), CN702.45 (B23), CN703.45 (B23)
/pc slots/IRQ6: CN700.43 (B22), CN701.43 (B22), CN702.43 (B22), CN703.43 (B22)
/pc slots/IRQ7: CN700.41 (B21), CN701.41 (B21), CN702.41 (B21), CN703.41 (B21)
/pc slots/IRQ10: CN704.5 (D3), CN705.5 (D3), CN706.5 (D3), CN707.5 (D3)
/pc slots/IRQ11: CN704.7 (D4), CN705.7 (D4), CN706.7 (D4), CN707.7 (D4)
/pc slots/IRQ12: CN704.9 (D5), CN705.9 (D5), CN706.9 (D5), CN707.9 (D5)
/pc slots/IRQ14: CN704.13 (D7), CN705.13 (D7), CN706.13 (D7), CN707.13 (D7)
/pc slots/IRQ15: CN704.11 (D6), CN705.11 (D6), CN706.11 (D6), CN707.11 (D6)
/pc slots/LA17: C770.2, CN704.16 (C8), CN705.16 (C8), CN706.16 (C8), CN707.16 (C8)
/pc slots/LA18: C768.2, CN704.14 (C7), CN705.14 (C7), CN706.14 (C7), CN707.14 (C7)
/pc slots/LA19: C766.2, CN704.12 (C6), CN705.12 (C6), CN706.12 (C6), CN707.12 (C6)
/pc slots/LA20: C764.2, CN704.10 (C5), CN705.10 (C5), CN706.10 (C5), CN707.10 (C5)
/pc slots/LA21: C762.2, CN704.8 (C4), CN705.8 (C4), CN706.8 (C4), CN707.8 (C4)
/pc slots/LA22: C760.2, CN704.6 (C3), CN705.6 (C3), CN706.6 (C3), CN707.6 (C3)
/pc slots/LA23: C796.2, CN704.4 (C2), CN705.4 (C2), CN706.4 (C2), CN707.4 (C2)
/pc slots/OSC: CN700.59 (B30), CN701.59 (B30), CN702.59 (B30), CN703.59 (B30)
/pc slots/RESDRV: CN700.3 (B2), CN701.3 (B2), CN702.3 (B2), CN703.3 (B2)
/pc slots/SHBE: C794.2, CN704.2 (C1), CN705.2 (C1), CN706.2 (C1), CN707.2 (C1)
/pc slots/SHITHEAD: CN700.37 (B19), CN701.37 (B19), CN702.37 (B19), CN703.37 (B19)
/pc slots/TC: CN700.53 (B27), CN701.53 (B27), CN702.53 (B27), CN703.53 (B27)
/pc slots/_DACK0: CN704.15 (D8), CN705.15 (D8), CN706.15 (D8), CN707.15 (D8)
/pc slots/_DACK1: CN700.33 (B17), CN701.33 (B17), CN702.33 (B17), CN703.33 (B17)
/pc slots/_DACK2: CN700.51 (B26), CN701.51 (B26), CN702.51 (B26), CN703.51 (B26)
/pc slots/_DACK3: CN700.29 (B15), CN701.29 (B15), CN702.29 (B15), CN703.29 (B15)
/pc slots/_DACK5: CN704.19 (D10), CN705.19 (D10), CN706.19 (D10), CN707.19 (D10)
/pc slots/_DACK6: CN704.23 (D12), CN705.23 (D12), CN706.23 (D12), CN707.23 (D12)
/pc slots/_DACK7: CN704.27 (D14), CN705.27 (D14), CN706.27 (D14), CN707.27 (D14)
/pc slots/_IO16: CN704.3 (D2), CN705.3 (D2), CN706.3 (D2), CN707.3 (D2), RP705.8 (R7)
/pc slots/_IOCHK: CN700.2 (A1), CN701.2 (A1), CN702.2 (A1), CN703.2 (A1)
/pc slots/_IOR: CN700.27 (B14), CN701.27 (B14), CN702.27 (B14), CN703.27 (B14), RP705.4 (R3)
/pc slots/_IOW: CN700.25 (B13), CN701.25 (B13), CN702.25 (B13), CN703.25 (B13), RP705.5 (R4)
/pc slots/_MASTER: CN704.33 (D17), CN705.33 (D17), CN706.33 (D17), CN707.33 (D17)
/pc slots/_MEM16: CN704.1 (D1), CN705.1 (D1), CN706.1 (D1), CN707.1 (D1), RP705.9 (R8)
/pc slots/_MEMR: CN700.23 (B12), CN701.23 (B12), CN702.23 (B12), CN703.23 (B12), CN704.18 (C9), CN704.20 (C10), CN705.18 (C9), CN705.20 (C10), CN706.18 (C9), CN706.20 (C10), CN707.18 (C9), CN707.20 (C10), RP705.2 (R1), RP705.3 (R2), RP705.6 (R5)
/pc slots/_MEMW: CN700.21 (B11), CN701.21 (B11), CN702.21 (B11), CN703.21 (B11), RP705.7 (R6)
GND: C700.2, C701.2, C702.2, C703.2, C704.2, C705.2, CN700.1 (B1), CN700.19 (B10), CN700.61 (B31), CN701.1 (B1), CN701.19 (B10), CN701.61 (B31), CN702.1 (B1), CN702.19 (B10), CN702.61 (B31), CN703.1 (B1), CN703.19 (B10), CN703.61 (B31), CN704.35 (D18), CN705.35 (D18), CN706.35 (D18), CN707.35 (D18), RP700.1 (common), RP701.1 (common), RP702.1 (common), RP703.1 (common), RP704.1 (common); also elsewhere on the board
unnamed: C711.1, RP700.10 (R9)
unnamed: C713.1, RP700.9 (R8)
unnamed: C714.1, RP700.8 (R7)
unnamed: C716.1, RP700.7 (R6)
unnamed: C717.1, RP700.6 (R5)
unnamed: C719.1, RP700.5 (R4)
unnamed: C720.1, RP700.4 (R3)
unnamed: C722.1, RP700.3 (R2)
unnamed: C726.1, RP700.2 (R1)
unnamed: C728.1, RP701.10 (R9)
unnamed: C730.1, RP701.9 (R8)
unnamed: C732.1, RP701.8 (R7)
unnamed: C734.1, RP701.7 (R6)
unnamed: C736.1, RP701.6 (R5)
unnamed: C738.1, RP701.5 (R4)
unnamed: C740.1, RP701.4 (R3)
unnamed: C742.1, RP701.3 (R2)
unnamed: C744.1, RP701.2 (R1)
unnamed: C746.1, RP702.10 (R9)
unnamed: C748.1, RP702.9 (R8)
unnamed: C750.1, RP702.8 (R7)
unnamed: C752.1, RP702.7 (R6)
unnamed: C754.1, RP702.6 (R5)
unnamed: C756.1, RP702.5 (R4)
unnamed: C758.1, RP702.4 (R3)
unnamed: C760.1, RP703.7 (R6)
unnamed: C762.1, RP703.6 (R5)
unnamed: C764.1, RP703.5 (R4)
unnamed: C766.1, RP703.4 (R3)
unnamed: C768.1, RP703.3 (R2)
unnamed: C770.1, RP703.2 (R1)
unnamed: C776.1, RP704.9 (R8)
unnamed: C778.1, RP704.8 (R7)
unnamed: C780.1, RP704.7 (R6)
unnamed: C782.1, RP704.6 (R5)
unnamed: C784.1, RP704.5 (R4)
unnamed: C786.1, RP704.4 (R3)
unnamed: C787.1, RP704.3 (R2)
unnamed: C789.1, RP704.2 (R1)
unnamed: C790.1, RP702.3 (R2)
unnamed: C791.1, RP702.2 (R1)
unnamed: C793.1, RP703.10 (R9)
unnamed: C794.1, RP703.9 (R8)
unnamed: C796.1, RP703.8 (R7)

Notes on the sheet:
IBM 8 BIT EXPANSION BUS
IBM 16 BIT EXTENDED BUS
Notes: - R6 PCB - C789 is noted C788 and connected to _MASTER instead of D15 - SHITHEAD is actually _DACK0, but can't be named that way to avoid clashing with the other bus, this name is from original schematics

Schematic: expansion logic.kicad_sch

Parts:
BT800: 3/60DK Ni-Cd 3.6V 60mAH; PinSocket_2x01_P2.54mm_Vertical
C800, C802, C803, C804, C812: 0.1uF; C_Rect_L11.5mm_W2.6mm_P10.00mm_MKT
C810: 20pF; C_Rect_L11.5mm_W2.6mm_P10.00mm_MKT
C811: 4.7uF 16V; CP_Radial_D5.0mm_P2.50mm
C904, C920: 100pF; C_Rect_L11.5mm_W2.6mm_P10.00mm_MKT
D800, D801: 1N4148; D_DO-35_SOD27_P7.62mm_Horizontal
R2, R800: 1k; R_Axial_DIN0207_L6.3mm_D2.5mm_P10.16mm_Horizontal
R801, R803: 470; R_Axial_DIN0207_L6.3mm_D2.5mm_P10.16mm_Horizontal
R804: 10k; R_Axial_DIN0207_L6.3mm_D2.5mm_P10.16mm_Horizontal
R806, R807: 4.7k; R_Axial_DIN0207_L6.3mm_D2.5mm_P10.16mm_Horizontal
R904, R905: 47; R_Axial_DIN0207_L6.3mm_D2.5mm_P10.16mm_Horizontal
RP800: 1k; R_Array_SIP8
RP801: 4.7k; R_Array_SIP8
U302: 74LS32; DIP-14_W7.62mm_Socket
U800: BUSTER5721; DIP-48_W15.24mm_Socket
U801: MSM6242; DIP-18_W7.62mm_Socket
U802: 74LS138; DIP-16_W7.62mm_Socket
U803: 74LS08; DIP-14_W7.62mm_Socket
U804: 74LS148; DIP-16_W7.62mm_Socket
VC800: 22-47pF; C_Rect_L7.0mm_W6.5mm_P5.00mm
Y800: 32768Hz; Crystal_DS15_D1.5mm_L5.0mm_Horizontal

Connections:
+12V: R801.1; also elsewhere on the board
A2: U801.4 (A0); also elsewhere on the board
A3: U801.5 (A1); also elsewhere on the board
A4: U801.6 (A2); also elsewhere on the board
A5: U801.7 (A3); also elsewhere on the board
BA19: U800.30 (_A19); also elsewhere on the board
BA20: U800.31 (_A20); also elsewhere on the board
BA21: U800.32 (_A21); also elsewhere on the board
BA22: U800.33 (_A22); also elsewhere on the board
BA23: U800.34 (_A23); also elsewhere on the board
C1: U800.19 (C1); also elsewhere on the board
C3: U800.20 (C3); also elsewhere on the board
D0: U801.14 (D0); also elsewhere on the board
D1: U801.13 (D1); also elsewhere on the board
D2: U801.12 (D2); also elsewhere on the board
D3: U801.11 (D3); also elsewhere on the board
DMAOUT: U302.11; also elsewhere on the board
DOE: R904.1; also elsewhere on the board
GND: BT800.2 (-), C800.1, C802.1, C803.2, C804.2, C810.2, C811.2, C812.2, C904.2, C920.2, U302.13, U800.1 (GND), U800.24 (GND), U800.43 (TEST), U801.2 (_CS0), U801.9 (GND), U802.4 (E1), U802.5 (E2), U802.8 (GND), U803.7 (GND), U804.5 (EI), U804.8 (GND), VC800.2; also elsewhere on the board
unnamed: BT800.1 (+), R803.2
unnamed: C810.1, U801.17 (_XT), Y800.1
unnamed: C811.1, C812.1, D801.1 (K), R803.1, U801.18 (VCC)
unnamed: D800.2 (A), D801.2 (A), R801.2
unnamed: R804.2, U801.1 (STDP)
unnamed: R904.2, U800.47 (DOE)
unnamed: R905.1, U800.22 (_C4)
unnamed: U801.16 (XT), VC800.1, Y800.2
unnamed: U802.9 (O6), U803.1
unnamed: U802.10 (O5), U804.12 (I2)
unnamed: U802.11 (O4), U804.13 (I3)
unnamed: U802.12 (O3), U803.4
unnamed: U802.13 (O2), U803.9
unnamed: U802.14 (O1), U804.3 (I6)
unnamed: U802.15 (O0), U803.12
unnamed: U803.3, U804.11 (I1)
unnamed: U803.6, U804.1 (I4)
unnamed: U803.8, U804.2 (I5)
unnamed: U803.11, U804.4 (I7)
READ: U800.35 (READ); also elsewhere on the board
_BAS: R2.2, U800.36 (_AS); also elsewhere on the board
_BEER: U800.26 (_BEER); also elsewhere on the board
_BG: U800.17 (_BG); also elsewhere on the board
_BG1: U800.2 (_BG1); also elsewhere on the board
_BG2: U800.3 (_BG2); also elsewhere on the board
_BG3: U800.4 (_BG3); also elsewhere on the board
_BG4: U800.5 (_BG4); also elsewhere on the board
_BG5: U800.6 (_BG5); also elsewhere on the board
_BLDS: U800.37 (_LDS); also elsewhere on the board
_BOSS: U800.39 (_BOSS); also elsewhere on the board
_BR: U800.27 (_BR); also elsewhere on the board
_BR1: U800.7 (_BR1); also elsewhere on the board
_BR2: U800.8 (_BR2); also elsewhere on the board
_BR3: U800.9 (_BR3); also elsewhere on the board
_BR4: U800.10 (_BR4); also elsewhere on the board
_BR5: U800.11 (_BR5); also elsewhere on the board
_BRST: U800.42 (_RST); also elsewhere on the board
_BUDS: U800.38 (_UDS); also elsewhere on the board
_C2: C904.1, U800.21 (_C2); also elsewhere on the board
_C4: C920.1, R905.2; also elsewhere on the board
_CBG: R806.1, U800.29 (_CBG); also elsewhere on the board
_CBR: R807.1, U800.28 (_CBR); also elsewhere on the board
_CDAC: U800.18 (_CDAC); also elsewhere on the board
_CIPL0: RP801.4 (R3), U802.1 (A0); also elsewhere on the board
_CIPL1: RP801.3 (R2), U802.2 (A1); also elsewhere on the board
_CIPL2: RP801.2 (R1), U802.3 (A2); also elsewhere on the board
_CLKRD: U801.8 (_RD); also elsewhere on the board
_CLKWR: U801.10 (_WR); also elsewhere on the board
_D2P: U800.45 (_D2P); also elsewhere on the board
_DBOE: U800.46 (_DBOE); also elsewhere on the board
_EINT1: RP801.8 (R7), U803.2; also elsewhere on the board
_EINT4: RP801.7 (R6), U803.5; also elsewhere on the board
_EINT5: RP801.6 (R5), U803.10; also elsewhere on the board
_EINT7: RP801.5 (R4), U803.13; also elsewhere on the board
_GBG: U800.23 (_GBG); also elsewhere on the board
_IPL0: U804.9 (S0); also elsewhere on the board
_IPL1: U804.7 (S1); also elsewhere on the board
_IPL2: U804.6 (S2); also elsewhere on the board
_OVR: U800.40 (_OVR); also elsewhere on the board
_OWN: R800.1, U302.12, U800.41 (_OWN); also elsewhere on the board
_SLAVE1: RP800.6 (R5), U800.12 (_SLAVE1); also elsewhere on the board
_SLAVE2: RP800.5 (R4), U800.13 (_SLAVE2); also elsewhere on the board
_SLAVE3: RP800.4 (R3), U800.14 (_SLAVE3); also elsewhere on the board
_SLAVE4: RP800.3 (R2), U800.15 (_SLAVE4); also elsewhere on the board
_SLAVE5: RP800.2 (R1), U800.16 (_SLAVE5); also elsewhere on the board

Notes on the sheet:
REV 6.2 fix p36 to +5 via 1k

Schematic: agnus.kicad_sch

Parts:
C101, C102, C107, C108, C110, C918: 0.1uF; C_Rect_L11.5mm_W2.6mm_P10.00mm_MKT
C415: 4.7uF 16V; CP_Radial_D5.0mm_P2.50mm
C905, C907, C908: 100pF; C_Rect_L11.5mm_W2.6mm_P10.00mm_MKT
FB101, FB907: Ferrite_Bead_Small; L_Axial_L7.0mm_D3.3mm_P10.16mm_Horizontal_Fastron_MICC
FB102: Ferrite_Bead_Small; L_Axial_L9.5mm_D4.0mm_P15.24mm_Horizontal_Fastron_SMCC
J101: Conn_01x03_Male; PinHeader_1x03_P2.54mm_Vertical
J102: Jumper_2_Open; SolderJumper-2_P1.3mm_Open_RoundedPad1.0x1.5mm
J900: Jumper_2_Bridged; PinHeader_2x01_P2.54mm_Vertical
R101, R109, R916: 4.7k; R_Axial_DIN0207_L6.3mm_D2.5mm_P10.16mm_Horizontal
R105, R106: 22; R_Axial_DIN0207_L6.3mm_D2.5mm_P10.16mm_Horizontal
R110, R114, R115: 330; R_Axial_DIN0207_L6.3mm_D2.5mm_P10.16mm_Horizontal
RP102, RP902, RP907: 47 (isolated, pack); R_Array_SIP8
U101: AGNUS8372; PLCC-84_THT-Socket
U102: GARY5719; DIP-48_W15.24mm_Socket
U107: 74F04; DIP-14_W7.62mm_Socket
U108: 74LS74A; DIP-14_W7.62mm_Socket
U302: 74LS32; DIP-14_W7.62mm_Socket
U900: 74F00; DIP-14_W7.62mm_Socket
X1: 28.37516MHz (pal); Oscillator_DIP-14
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

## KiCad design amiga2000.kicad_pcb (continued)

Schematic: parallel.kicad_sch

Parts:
C203, C300, C302, C303, C607, C909, C916: 0.1uF; C_Rect_L11.5mm_W2.6mm_P10.00mm_MKT
C259, C260, C261: 100pF; C_Rect_L11.5mm_W2.6mm_P10.00mm_MKT
C322, C323: 0.01uF; C_Rect_L11.5mm_W2.6mm_P10.00mm_MKT
C912: 470uF 16/25v; CP_Radial_D10.0mm_P5.00mm
CN300: KEYBOARD; DIN_5_KBD
CN301: DB25F; DSUB-25_Female_Horizontal_P2.77x2.84mm_EdgePinOffset7.70mm_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
CN302: DB23F; DSUB-23_Female_Horizontal_P2.77x2.84mm_EdgePinOffset7.70mm_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
CN303: Conn_02x17_Odd_Even; PinHeader_2x17_P2.54mm_Vertical
EMI300, EMI301, EMI302, EMI303, EMI304, EMI305, EMI306, EMI307, EMI308, EMI309, EMI310, EMI335, EMI336, EMI337, EMI338: 330pF (Type F 331); EMI_FILTER
EMI311, EMI312, EMI313, EMI314, EMI315, EMI316, EMI317, EMI318, EMI319, EMI320, EMI321: 100pF (Type F 101); EMI_FILTER
EMI322, EMI323, EMI324, EMI339, EMI340, EMI341: 100pF (Type C 101); EMI_FILTER
F3, F4: 4A; C_Rect_L11.5mm_W2.0mm_P10.00mm_MKT
FB301, FB302, FB303: Ferrite_Bead_Small; L_Axial_L7.0mm_D3.3mm_P10.16mm_Horizontal_Fastron_MICC
J3: ACCEL; PinHeader_1x02_P2.54mm_Vertical
J300: Conn_01x03_Male; PinHeader_1x03_P2.54mm_Vertical
J301: DF1:; PinHeader_2x01_P2.54mm_Vertical
Q301: 2N3904; TO-92_Inline
R201, R300, R309: 4.7k; R_Axial_DIN0207_L6.3mm_D2.5mm_P10.16mm_Horizontal
R301, R602: 1k; R_Axial_DIN0207_L6.3mm_D2.5mm_P10.16mm_Horizontal
R310: 47 0.5W; R_Axial_DIN0411_L9.9mm_D3.6mm_P15.24mm_Horizontal
R914: 1 0.5W; R_Axial_DIN0411_L9.9mm_D3.6mm_P15.24mm_Horizontal
RP300: 10k; R_Array_SIP10
RP301: 1k; R_Array_SIP6
U102: GARY5719; DIP-48_W15.24mm_Socket
U108: 74LS74A; DIP-14_W7.62mm_Socket
U203: 74LS38; DIP-14_W7.62mm_Socket
U300: CIA8520; DIP-40_W15.24mm_Socket
U302: 74LS32; DIP-14_W7.62mm_Socket
U303: 74F08; DIP-14_W7.62mm_Socket
U607: 74LS08; DIP-14_W7.62mm_Socket
U900: 74F00; DIP-14_W7.62mm_Socket
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

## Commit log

2019-05-26 Placeholders; Processor done
    [agnus.sch, amiga2000.kicad_pcb, amiga2000.sch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]
2019-05-28 Use correct source rev6. mostly all schematics done for first pass...
    [agnus.sch, amiga2000.sch, chipram.sch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]
2019-05-28 Remove Vref as it's a local label of the sheet
    [parallel.sch, paula.sch]
2019-05-28 Some fixes
    [agnus.sch, chipram.sch, denise.sch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]
2019-05-29 All done; now to review
    [coprocessor slot.sch, expansion logic.sch, paula.sch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]
2019-05-29 Rev is 6.0
    [agnus.sch, amiga2000.sch, chipram.sch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]
2019-05-29 Fix some DRC fuckery
    [chipram.sch, power.sch]
2019-05-29 Rename bus with correct syntax
    [agnus.sch, chipram.sch, coprocessor slot.sch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]
2019-05-29 Some ERC things
    [agnus.sch, chipram.sch, coprocessor slot.sch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]
2019-05-29 Rename some bus things
    [expansion logic.sch, zorro.sch]
2019-05-29 Fix a bunch of DRC errors
    [expansion logic.sch, power.sch, zorro.sch]
2019-05-29 More final ERC fixes
    [denise.sch, expansion logic.sch]
2019-05-29 Include BOMs
    [amiga2000.csv]
2019-05-29 Implemented various rev 6.2 fixes from forums and my own board
    [agnus.sch, amiga2000.sch, processor.sch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]
2019-05-29 Bump rev, update readme
    [agnus.sch, amiga2000.sch, chipram.sch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]
2019-05-31 Rev 6.2 fixes are now documented properly
    [amiga2000.csv, amiga2000.sch, serial.sch]
2019-05-31 REV 6.2 fixes applied
    [amiga2000.sch, coprocessor slot.sch, denise.sch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]
2019-05-31 Fix missing bus address
    [parallel.sch]
2019-05-31 Misread the PCB; It's effectively E and not A1
    [parallel.sch, processor.sch]
2019-05-31 Add PDF of schematics
2019-06-01 Fix the fixes
    [coprocessor slot.sch]
2019-06-01 Document rev 6.3 and 6.4 fixes here
    [amiga2000.sch]
2019-06-03 Review started; oopsie whoopsie
    [amiga2000.sch, paula.sch, processor.sch]
2019-06-03 Add gender to connectors
    [denise.sch, parallel.sch, paula.sch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]
2019-06-03 Re ran annotate; bom; plot
    [amiga2000.csv, paula.sch, serial.sch]
2019-06-03 Review update
    [amiga2000.sch]
2019-06-04 One more review
    [amiga2000.sch, serial.sch]
2019-06-04 Power review; Add missing mouting holes
    [amiga2000.sch, power.sch]
2019-06-04 Spotted error in original scanned schematics
    [amiga2000.sch]
2019-06-05 Will make next kicad DRC happy
    [power.sch]
2019-06-05 more done
    [amiga2000.sch, expansion logic.sch]
2019-06-12 Review done
    [agnus.sch, amiga2000.sch]
2019-06-12 kbd ok
    [amiga2000.sch, parallel.sch]
2019-06-12 All reviews done
    [amiga2000.sch, denise.sch]
2019-06-13 Associate footprints with components
    [agnus.sch, chipram.sch, coprocessor slot.sch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]
2019-06-15 Associate more components
    [agnus.sch, denise.sch, expansion logic.sch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]
2019-06-15 Change namings
    [denise.sch, parallel.sch, serial.sch]
2019-06-15 Associate ISA slots
    [pc slots.sch]
2019-06-15 Update footprints
    [agnus.sch, chipram.sch, coprocessor slot.sch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]
2019-06-15 Components associations finished; regenered netlist and pdf
    [amiga2000.csv, denise.sch, parallel.sch]
2019-06-15 fix fuckup
    [pc slots.sch]
2019-06-15 Continue placing things
    [power.sch]
2019-06-15 More placement
    [agnus.sch, chipram.sch, parallel.sch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]
2019-06-16 first placement pass is done
    [denise.sch, parallel.sch, paula.sch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]
2019-06-16 mod: breakout INT2/OVR to pin header
    [amiga2000.kicad_pcb, parallel.sch]
2019-06-16 Remove old layer used for layouting
    [amiga2000.kicad_pcb]
2019-06-16 Define track widths
    [amiga2000.kicad_pcb]
2019-06-16 Make caps footprint smaller
    [agnus.sch, amiga2000.kicad_pcb, chipram.sch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]
2019-06-16 All components have been realigned; plus small sizes changes
    [amiga2000.kicad_pcb, denise.sch, parallel.sch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]
2019-06-16 Makes the DRC happy
    [amiga2000.kicad_pcb, denise.sch, parallel.sch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]
2019-06-16 It's ok
    [amiga2000.kicad_pcb, expansion logic.sch]
2019-06-16 Add explanation for jumpers
    [amiga2000.kicad_pcb]
2019-06-16 Replot and regenerate BOM
    [amiga2000.csv]
2019-06-16 Add interactive bom
2019-06-16 Din keyboard update
    [amiga2000.kicad_pcb]
2019-06-16 Now with F DB23, connectors are ok
    [amiga2000.kicad_pcb, parallel.sch]
2019-06-16 Regenerate both BOMs after using the right DB23 M/F
    [amiga2000.csv]
2019-06-17 Correct some components orientation
    [amiga2000.kicad_pcb, power.sch]
2019-06-17 Fix capacitor error; regen files
    [amiga2000.kicad_pcb, power.sch]
2019-06-17 Add DoNotPopulate field for components which shouldn't be fitted
    [amiga2000.csv, amiga2000.kicad_pcb, denise.sch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]
2019-06-17 Correct some datasheets
    [agnus.sch, amiga2000.csv, amiga2000.kicad_pcb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]
2019-06-17 Switch footprints for suitable modern replacements
    [agnus.sch, amiga2000.csv, amiga2000.kicad_pcb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]
2019-06-17 Some footprints updates; Add all Mouser references
    [agnus.sch, amiga2000.csv, amiga2000.kicad_pcb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]
2019-06-19 Got the components, reduce some footprints
    [amiga2000.csv, amiga2000.kicad_pcb, chipram.sch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]
2019-06-19 Some footprint changes; Tidy pcb
    [amiga2000.kicad_pcb, pc slots.sch, zorro.sch]
2019-06-19 Board have been autorouted
2019-06-19 Add gerbers
    [amiga2000-B_Mask.gbr, amiga2000-B_Paste.gbr, amiga2000-B_SilkS.gbr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]
2019-08-06 Add power connector ref
2019-08-14 Fix CSV
    [amiga2000.csv]
2019-08-14 Add orig broken csv
    [amiga2000.broken.csv]
2021-05-02 Fix joystick ports; Regenerate gerbers and schematics
    [agnus.sch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]
2021-05-02 Update gerbers archive
2023-04-24 remove legacy files
    [agnus.sch, amiga2000.sch, chipram.sch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]
2023-04-24 Add kicad7 files; add note for ISA bus signal name
    [agnus.kicad_sch, amiga2000.kicad_sch, chipram.kicad_sch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]
